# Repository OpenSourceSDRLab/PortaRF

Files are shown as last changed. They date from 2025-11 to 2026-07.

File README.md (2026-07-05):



# PortaRF
Custom Hardware and Firmware Bin Files for the PortaRF Gadget.

# Introduction
The PortaRF is an open-source hardware platform that combines the [HackRF One R10](https://github.com/greatscottgadgets/hackrf/tree/master/hardware/hackrf-one) and [PortaPack H4M](https://github.com/OpenSourceSDRLab/mayhem-firmware/tree/next/hardware/portapack_h4m) into a single Board. It supports the transmission and reception of radio signals ranging from 1 MHz to 6 GHz, rendering it an exceptionally versatile tool for RF exploration and development.  It is a portable, standalone device for signal analysis and transmission without requiring a computer.

Here is a news report about the PortaRF from [RTL-SDR.com](https://www.rtl-sdr.com/two-youtube-reviews-of-the-new-portarf-a-new-hackrf-portapack-combo/).




# Where to buy
[OpenSourceSDRLab](https://opensourcesdrlab.com/products/portarf) official website.

# Videos
Porta RF Deep Dive (https://www.youtube.com/watch?v=B1F76LqbRrY)

HackRF Portapack Evolved? This is PortaRF (https://www.youtube.com/watch?v=LNKeIju5pRY)

PortaRF - HackRF One and PortaPack H4M Combined Gadget for Mayhem Software Defined Radio (https://www.youtube.com/watch?v=UqoFG5f3fv4)

PortaRF - Utilizing the AI Voice-assisted device control function (https://www.youtube.com/watch?v=Xrx7OxZS-OY))

PortaRF Quick Look (https://www.youtube.com/watch?v=y4wdKojJfC0)

# Hardware Improvements
1. **Doubled flash storage capacity**.
We have replaced the original W25Q80DVSSIQ with W25Q16DV SPI Flash chip, expanding the original firmware storage capacity from 1M byte to 2M byte. This provides a broader creative space for Mayhem firmware developers, enabling the implementation of more complex signal processing algorithms and functions.

2. **4.0-inch IPS resistive touch screen**.
The screen has been upgraded to a 4.0-inch IPS full-view high-definition display. Compared with the original 3.2-inch non-IPS matte screen, it has made a significant improvement in color reproduction, viewing angle and touch accuracy. Whether it's spectrum analysis or parameter settings, the text is clearer and the operation is more precise.

3. **3000mAh lithium battery system**.
The battery capacity has been increased to 3000mAh, significantly extending the battery life. At the same time, an intelligent battery protection board has been used in this battery, providing protection against overcharging, overdischarging, short circuiting, and overcurrent. This lithium battery is produced by a legitimate factory with guaranteed quality.

4. **User-friendly hand-held directional keys**.
PortaRF has added a gamepad-style directional button. It is particularly suitable for rapid directional operations in functions such as spectrum scanning and game applications. It will significantly enhance the direction control efficiency and comfort.

5. **Modular Expansion Board Design**.
The expansion board adopts a Board to Board connector, a socket interface similar to the memory module, which is smaller in size and more stable in installation. This can optimize the internal space utilization.

6. **Light Guide Column LED Status Indication System**.
PortaRF also incorporates the light guide column design, making the LED status lights more visible. Regardless of day or night, the equipment status is clearly visible.

7. **Nice shell design**.
We have designed a brand new shell for the PortaRF and added many design elements, such as the buckle of the shell, which makes the shell fit tightly. The slot of the memory card is designed with grooves, the SD card can be inserted and removed without the need for tools. The dual speaker sound hole design enables better sound output from the speakers.

8. **AI voice-assisted (Beta version)**.
PortaRF incorporates voice-controlled interaction technology. Users can perform operations such as device activation, application switching, and system reboot through natural voice commands. This feature is particularly suitable for scenarios where hands are not available, providing additional convenience operations.

# Applications
<div class="editor_table_wrap">&nbsp;
<table border="1" style="width: 81.0373%; height: 526px;">
<tbody>
<tr style="height: 26.2px;">
<td style="width: 55.25%; height: 26.2px;">
<h3 class="text-xl font-semibold text-indigo-800 mb-3">Receive Applications</h3>
</td>
<td style="width: 44.7339%; height: 26.2px;">
<h3 class="text-xl font-semibold text-indigo-800 mb-3">Transmit Applications</h3>
</td>
</tr>
<tr style="height: 22.4px;">
<td style="width: 55.25%; height: 22.4px;"><strong>Sniff &amp; Capture</strong>: Sniff &amp; capture signals for instant replay or save to SD card for analysis</td>
<td style="width: 44.7339%; height: 22.4px;"><strong>ADS-B</strong>: Transmit ADS-B (Aviation) signals for testing</td>
</tr>
<tr style="height: 44.8px;">
<td style="width: 55.25%; height: 44.8px;"><strong>ADS-B</strong>: Receive and analyze aviation signals with real-time location display</td>
<td style="width: 44.7339%; height: 44.8px;"><strong>APRS</strong>: Transmit APRS packets for GPS, weather stations and telemetry</td>
</tr>
<tr style="height: 22.4px;">
<td style="width: 55.25%; height: 22.4px;"><strong>AIS</strong>: Receive and analyze marine vessel signals</td>
<td style="width: 44.7339%; height: 22.4px;"><strong>GPS</strong>: Transmit GPS signals for testing</td>
</tr>
<tr style="height: 22.4px;">
<td style="width: 55.25%; height: 22.4px;"><strong>AFSK</strong>: Receive, demodulate and analyze AFSK signals</td>
<td style="width: 44.7339%; height: 22.4px;"><strong>Key Fob</strong>: Key-fob capture, replay and emulation for multiple models</td>
</tr>
<tr style="height: 22.4px;">
<td style="width: 55.25%; height: 22.4px;"><strong>Bluetooth</strong>: Sniff MAC addresses of BLE devices</td>
<td style="width: 44.7339%; height: 22.4px;"><strong>Morse Code</strong>: Morse code transmission tool</td>
</tr>
<tr style="height: 22.4px;">
<td style="width: 55.25%; height: 22.4px;"><strong>NRF</strong>: Decode NRF24L01 signals, commonly used for drones</td>
<td style="width: 44.7339%; height: 22.4px;"><strong>Burger Pager</strong>: Transmit restaurant pager signals</td>
</tr>
<tr style="height: 22.4px;">
<td style="width: 55.25%; height: 22.4px;"><strong>Audio</strong>: Decode WFM/NFM/AM radio transmissions</td>
<td style="width: 44.7339%; height: 22.4px;"><strong>POCSAG</strong>: Transmit pager signals</td>
</tr>
<tr style="height: 22.4px;">
<td style="width: 55.25%; height: 22.4px;"><strong>Spectrum Analyzer</strong>: Waterfall spectrum analyzer for detecting signals</td>
<td style="width: 44.7339%; height: 22.4px;"><strong>SSTV</strong>: Transmit Slow Scan Television signals</td>
</tr>
<tr style="height: 22.4px;">
<td style="width: 55.25%; height: 22.4px;"><strong>Analog TV</strong>: Decode and watch analog TV signals, used on FPV drones</td>
<td style="width: 44.7339%; height: 22.4px;"><strong>RDS</strong>: Send Radio Data System messages</td>
</tr>
<tr style="height: 22.4px;">
<td style="width: 55.25%; height: 22.4px;"><strong>ERT Meters</strong>: Decode ERT Meter signals</td>
<td style="width: 44.7339%; height: 22.4px;"><strong>OOK</strong>: Send On-Off Keying packages</td>
</tr>
<tr style="height: 22.4px;">
<td style="width: 55.25%; height: 22.4px;"><strong>POCSAG</strong>: Sniff and decode pager signals</td>
<td style="width: 44.7339%; height: 22.4px;"></td>
</tr>
<tr style="height: 22.4px;">
<td style="width: 55.25%; height: 22.4px;"><strong>Radiosonde</strong>: Sniff and decode weather station signals</td>
<td style="width: 44.7339%; height: 22.4px;"></td>
</tr>
<tr style="height: 22.4px;">
<td style="width: 55.25%; height: 22.4px;"><strong>TPMS</strong>: Decode Tire Pressure Monitoring System sensors</td>
<td style="width: 44.7339%; height: 22.4px;">&nbsp; &nbsp; &nbsp; &nbsp;</td>
</tr>
</tbody>
</table>

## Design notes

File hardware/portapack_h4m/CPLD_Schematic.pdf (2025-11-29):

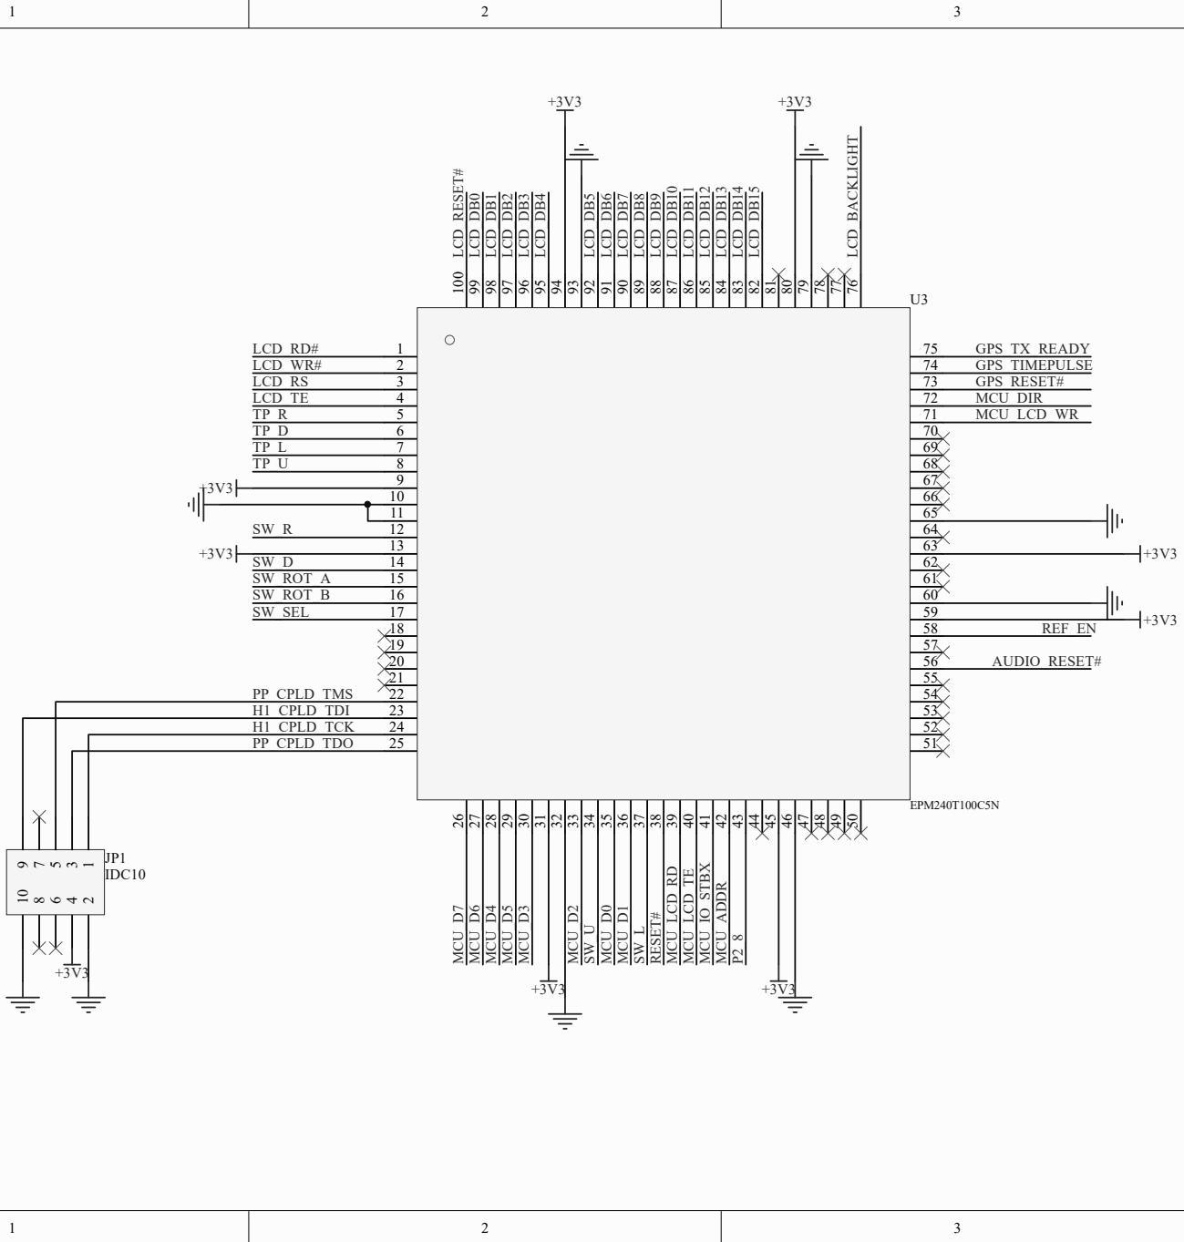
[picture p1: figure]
LCD_DB10; LCD_DB11; LCD_DB12; LCD_DB13; LCD_DB14; LCD_DB15; MCU_DIR MCU_LCD_WR; LCD_RESET#; LCD_BACKLIGHT; GPS_TX_READY GPS_TIMEPULSE; MCU_ADDR; PP_CPLD_TDO; MCU_D7; MCU_D6; MCU_D4; MCU_D5; MCU_D3; MCU_D2; MCU_D0; MCU_D1; RESET#; MCU_LCD_RD; MCU_LCD_TE; MCU_IO_STBX; H1_CPLD_TCK; SW_D SW_ROT_A SW_ROT_B SW_SEL; PP_CPLD_TMS H1_CPLD_TDI; GPS_RESET#; AUDIO_RESET#; REF_EN; LCD_TE; LCD_WR#; LCD_RD#; LCD_DB0; LCD_DB1; LCD_RS; LCD_DB2; LCD_DB3; LCD_DB4; LCD_DB5; LCD_DB6; LCD_DB7; LCD_DB8; LCD_DB9; EPM240T100C5N; JP1 IDC10

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
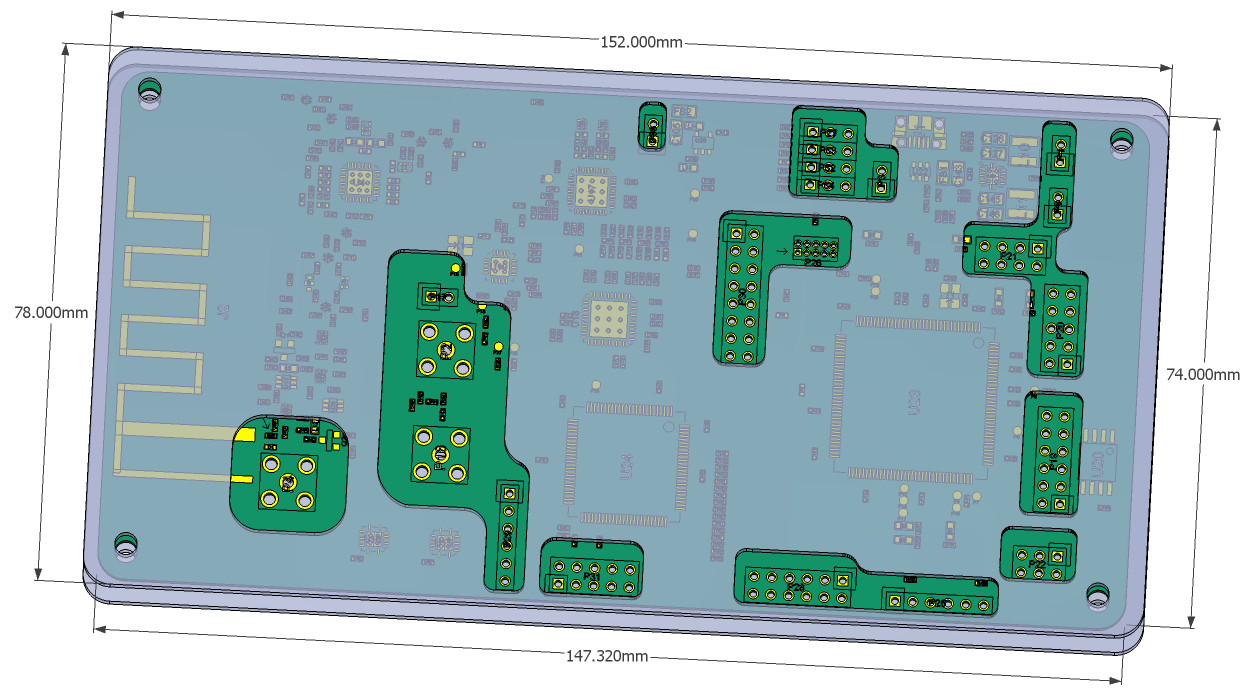
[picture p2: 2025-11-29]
hackrf/hardware/jawbreaker/SoBv1_DP17298/jawbreaker_and_case.png

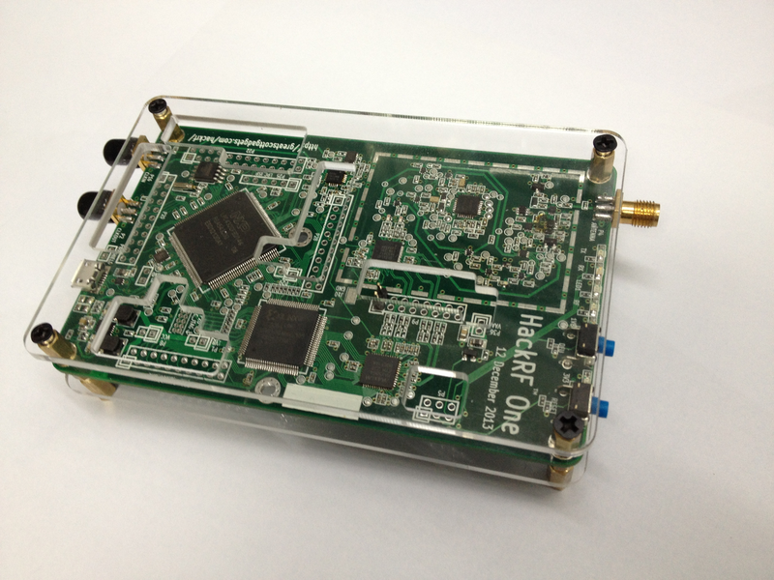
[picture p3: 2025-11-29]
hackrf/hardware/hackrf-one/PlasticCase_CAD/Case_With_HackRF.png

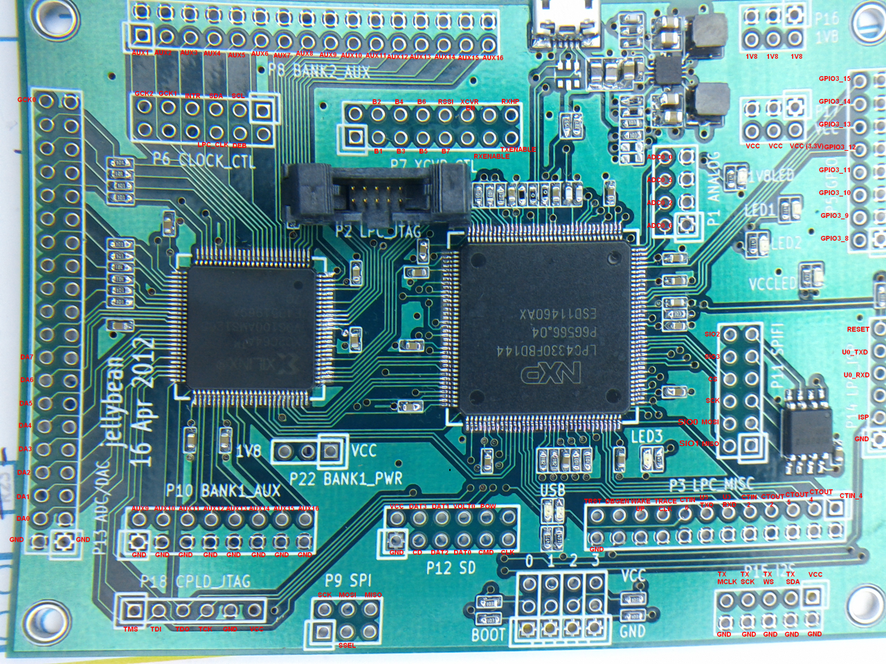
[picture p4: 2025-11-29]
hackrf/hardware/jellybean/JellyBean_pins.png

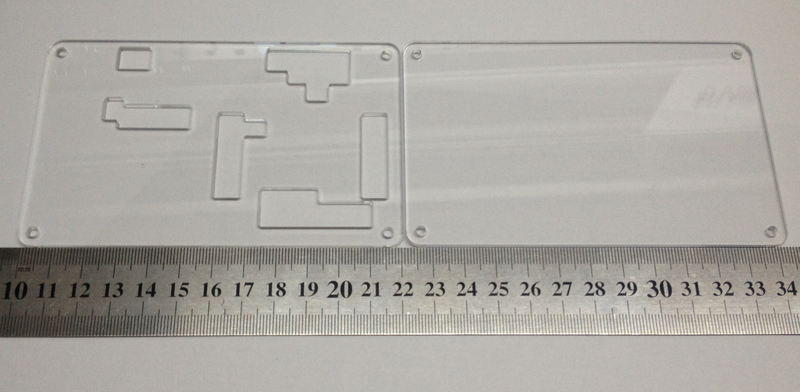
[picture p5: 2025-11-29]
hackrf/hardware/hackrf-one/PlasticCase_CAD/HackRF_One_Case.png

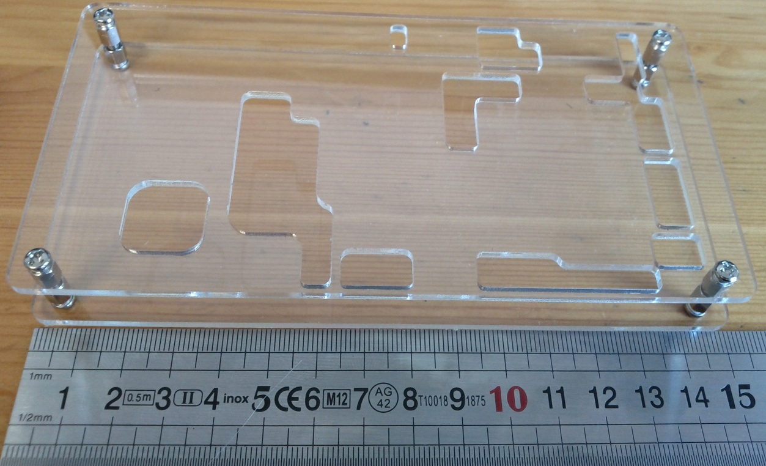
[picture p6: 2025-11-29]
hackrf/hardware/jawbreaker/SoBv1_DP17298/SoBv1-DP17298-jawbreaker.jpg

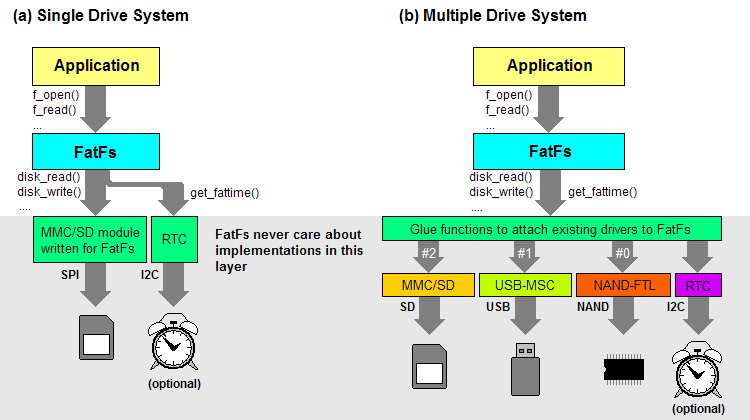
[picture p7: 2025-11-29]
firmware/chibios-portapack/ext/fatfs/doc/res/funcs.png

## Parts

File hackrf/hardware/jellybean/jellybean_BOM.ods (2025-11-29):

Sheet: JellyBean_BOM
Ref | Value | Manufacturer | Footprint | Details | DigiKey Quantity | DigiKey PN
R1 | 0 | Panasonic | ERJ-3GEY0R00V | RES 0.0 OHM 1/10W 0603 SMD | 2 | P0.0GCT-ND
R2 | 0 | Panasonic | ERJ-3GEY0R00V | RES 0.0 OHM 1/10W 0603 SMD
R18 | 100 | Panasonic | ERJ-3GEYJ101V | RES 100 OHM 1/10W 5% 0603 SMD | 10 | P100GCT-ND
R19 | 100 | Panasonic | ERJ-3GEYJ101V | RES 100 OHM 1/10W 5% 0603 SMD
R20 | 100 | Panasonic | ERJ-3GEYJ101V | RES 100 OHM 1/10W 5% 0603 SMD
R21 | 100 | Panasonic | ERJ-3GEYJ101V | RES 100 OHM 1/10W 5% 0603 SMD
R22 | 100 | Panasonic | ERJ-3GEYJ101V | RES 100 OHM 1/10W 5% 0603 SMD
R23 | 100 | Panasonic | ERJ-3GEYJ101V | RES 100 OHM 1/10W 5% 0603 SMD
R24 | 100 | Panasonic | ERJ-3GEYJ101V | RES 100 OHM 1/10W 5% 0603 SMD
R25 | 100 | Panasonic | ERJ-3GEYJ101V | RES 100 OHM 1/10W 5% 0603 SMD
R26 | 100 | Panasonic | ERJ-3GEYJ101V | RES 100 OHM 1/10W 5% 0603 SMD
R27 | 100 | Panasonic | ERJ-3GEYJ101V | RES 100 OHM 1/10W 5% 0603 SMD
R12 | 470 | Panasonic | ERJ-3GEYJ471V | RES 470 OHM 1/10W 5% 0603 SMD | 7 | P470GCT-ND
R13 | 470 | Panasonic | ERJ-3GEYJ471V | RES 470 OHM 1/10W 5% 0603 SMD
R15 | 470 | Panasonic | ERJ-3GEYJ471V | RES 470 OHM 1/10W 5% 0603 SMD
R29 | 470 | Panasonic | ERJ-3GEYJ471V | RES 470 OHM 1/10W 5% 0603 SMD
R3 | 470 | Panasonic | ERJ-3GEYJ471V | RES 470 OHM 1/10W 5% 0603 SMD
R8 | 470 | Panasonic | ERJ-3GEYJ471V | RES 470 OHM 1/10W 5% 0603 SMD
R9 | 470 | Panasonic | ERJ-3GEYJ471V | RES 470 OHM 1/10W 5% 0603 SMD
R30 | 1k8 | Panasonic | ERJ-3GEYJ182V | RES 1.8K OHM 1/10W 5% 0603 SMD | 2 | P1.8KGCT-ND
R31 | 1k8 | Panasonic | ERJ-3GEYJ182V | RES 1.8K OHM 1/10W 5% 0603 SMD
R16 | 10k | Panasonic | ERJ-3GEYJ103V | RES 10K OHM 1/10W 5% 0603 SMD | 13 | P10KGCT-ND
R17 | 10k | Panasonic | ERJ-3GEYJ103V | RES 10K OHM 1/10W 5% 0603 SMD
R28 | 10k | Panasonic | ERJ-3GEYJ103V | RES 10K OHM 1/10W 5% 0603 SMD
R32 | 10k | Panasonic | ERJ-3GEYJ103V | RES 10K OHM 1/10W 5% 0603 SMD
R39 | 10k | Panasonic | ERJ-3GEYJ103V | RES 10K OHM 1/10W 5% 0603 SMD
R4 | 10k | Panasonic | ERJ-3GEYJ103V | RES 10K OHM 1/10W 5% 0603 SMD
R40 | 10k | Panasonic | ERJ-3GEYJ103V | RES 10K OHM 1/10W 5% 0603 SMD
R41 | 10k | Panasonic | ERJ-3GEYJ103V | RES 10K OHM 1/10W 5% 0603 SMD
R42 | 10k | Panasonic | ERJ-3GEYJ103V | RES 10K OHM 1/10W 5% 0603 SMD
R43 | 10k | Panasonic | ERJ-3GEYJ103V | RES 10K OHM 1/10W 5% 0603 SMD
R5 | 10k | Panasonic | ERJ-3GEYJ103V | RES 10K OHM 1/10W 5% 0603 SMD
R6 | 10k | Panasonic | ERJ-3GEYJ103V | RES 10K OHM 1/10W 5% 0603 SMD
R7 | 10k | Panasonic | ERJ-3GEYJ103V | RES 10K OHM 1/10W 5% 0603 SMD
R14 | 12k | Panasonic | ERJ-3EKF1202V | RES 12.0K OHM 1/10W 1% 0603 SMD | 1 | P12.0KHCT-ND
R10 | 15k | Panasonic | ERJ-3GEYJ153V | RES 15K OHM 1/10W 5% 0603 SMD | 1 | P15KGCT-ND
R11 | 33k | Panasonic | ERJ-3GEYJ333V | RES 33K OHM 1/10W 5% 0603 SMD | 1 | P33KGCT-ND
R36 | 160k+560k in parallel (to obtain 3,3V instead of 2.7V) | Panasonic | ERJ-3EKF1603V | RES 160K OHM 1/10W 1% 0603 SMD | 1 | P160KHCT-ND
R35 | 180k | Panasonic | ERJ-3EKF1803V | RES 180K OHM 1/10W 1% 0603 SMD | 1 | P180KHCT-ND
R37 | 360k | Panasonic | ERJ-3EKF3603V | RES 360K OHM 1/10W 1% 0603 SMD | 1 | P360KHCT-ND
R38 | 560k | Panasonic | ERJ-3EKF5603V | RES 560K OHM 1/10W 1% 0603 SMD | 2 | P560KHCT-ND
C24 | 22pF | Murata | GRM1885C1H220JA01D | CAP CER 22PF 50V 5% NP0 0603 | 10 | 490-1411-1-ND
C18 | 47pF | Murata | GRM1885C1H470JA01D | CAP CER 47PF 50V 5% NP0 0603 | 10 | 490-1419-1-ND
C1 | 100nF | Murata | GRM188R71C104KA01D | CAP CER 0.1UF 16V 10% X7R 0603 | 30 | 490-1532-1-ND
C10 | 100nF | Murata | GRM188R71C104KA01D | CAP CER 0.1UF 16V 10% X7R 0603
C11 | 100nF | Murata | GRM188R71C104KA01D | CAP CER 0.1UF 16V 10% X7R 0603
C12 | 100nF | Murata | GRM188R71C104KA01D | CAP CER 0.1UF 16V 10% X7R 0603
C13 | 100nF | Murata | GRM188R71C104KA01D | CAP CER 0.1UF 16V 10% X7R 0603
C14 | 100nF | Murata | GRM188R71C104KA01D | CAP CER 0.1UF 16V 10% X7R 0603
C15 | 100nF | Murata | GRM188R71C104KA01D | CAP CER 0.1UF 16V 10% X7R 0603
C17 | 100nF | Murata | GRM188R71C104KA01D | CAP CER 0.1UF 16V 10% X7R 0603
C19 | 100nF | Murata | GRM188R71C104KA01D | CAP CER 0.1UF 16V 10% X7R 0603
C2 | 100nF | Murata | GRM188R71C104KA01D | CAP CER 0.1UF 16V 10% X7R 0603
C20 | 100nF | Murata | GRM188R71C104KA01D | CAP CER 0.1UF 16V 10% X7R 0603
C22 | 100nF | Murata | GRM188R71C104KA01D | CAP CER 0.1UF 16V 10% X7R 0603
C23 | 100nF | Murata | GRM188R71C104KA01D | CAP CER 0.1UF 16V 10% X7R 0603
C25 | 100nF | Murata | GRM188R71C104KA01D | CAP CER 0.1UF 16V 10% X7R 0603
C26 | 100nF | Murata | GRM188R71C104KA01D | CAP CER 0.1UF 16V 10% X7R 0603
C29 | 100nF | Murata | GRM188R71C104KA01D | CAP CER 0.1UF 16V 10% X7R 0603
C3 | 100nF | Murata | GRM188R71C104KA01D | CAP CER 0.1UF 16V 10% X7R 0603
C32 | 100nF | Murata | GRM188R71C104KA01D | CAP CER 0.1UF 16V 10% X7R 0603
C33 | 100nF | Murata | GRM188R71C104KA01D | CAP CER 0.1UF 16V 10% X7R 0603
C4 | 100nF | Murata | GRM188R71C104KA01D | CAP CER 0.1UF 16V 10% X7R 0603
C5 | 100nF | Murata | GRM188R71C104KA01D | CAP CER 0.1UF 16V 10% X7R 0603
C7 | 100nF | Murata | GRM188R71C104KA01D | CAP CER 0.1UF 16V 10% X7R 0603
C8 | 100nF | Murata | GRM188R71C104KA01D | CAP CER 0.1UF 16V 10% X7R 0603
C9 | 100nF | Murata | GRM188R71C104KA01D | CAP CER 0.1UF 16V 10% X7R 0603
C16 | 100pF | Murata | GRM1885C1H101JA01D | CAP CER 100PF 50V 5% NP0 0603 | 10 | 490-1427-1-ND
C6 | 4u7 | Taiyo Yuden | LMK212BJ475KD-T | CAP CER 4.7UF 10V 10% X5R 0805 | 1 | 587-1297-1-ND
C21 | 10uF | Murata | GRM21BR61A106KE19L | CAP CER 10UF 10V 10% X5R 0805 | 10 | 490-1709-1-ND
C27 | 10uF | Murata | GRM21BR61A106KE19L | CAP CER 10UF 10V 10% X5R 0805
C28 | 10uF | Murata | GRM21BR61A106KE19L | CAP CER 10UF 10V 10% X5R 0805
C30 | 10uF | Murata | GRM21BR61A106KE19L | CAP CER 10UF 10V 10% X5R 0805
C31 | 10uF | Murata | GRM21BR61A106KE19L | CAP CER 10UF 10V 10% X5R 0805
L1 | 4u7 | Taiyo Yuden | NRG4026T4R7M | INDUCTOR 4.7UH 1.6A 20% SMD | 2 | 587-2382-1-ND
L2 | 4u7 | Taiyo Yuden | NRG4026T4R7M | INDUCTOR 4.7UH 1.6A 20% SMD
FB1 | FILTER | Murata | BLM21PG221SN1D | FERRITE CHIP 220 OHM 2000MA 0805 | 1 | 490-1054-1-ND
U1 | GSG-IP4220CZ6 | NXP | IP4220CZ6,125 | IC USB DUAL ESD PROTECT 6TSOP | 1 | 568-3529-1-ND
J1 | GSG-USB-MICRO-B | FCI | 10103594-0001LF | CONN RCPT STD MICRO USB TYPE B | 1 | 609-4050-1-ND
U4 | GSG-XC2C64A-7VQG100C | Xilinx | XC2C64A-7VQG100C | IC CR-II CPLD 64MCELL 100-VQFP | 1 | 122-1409-ND
U2 | LPC43XXFBD144 | NXP | LPC4330FBD144,551 | IC MCU 32BIT 144LQFP | 1 | 568-9450-ND
U5 | TPS62410 | Texas Instruments | TPS62410DRCR | IC BUCK SYNC DUAL ADJ 0.8A 10SON | 1 | 296-25488-1-ND
D3 | LED3 | Everlight | QTLP601CRTR | LED RED STD BRIGHT 0603 SMD | 1 | 1080-1407-1-ND
D5 | 1V8LED | Everlight | QTLP600CYTR | LED YLW SUPER BRIGHT 0606 SMD | 3 | 1080-1404-1-ND
D2 | LED2 | Everlight | QTLP600CYTR | LED YLW SUPER BRIGHT 0606 SMD
D7 | USBLED0 | Everlight | QTLP600CYTR | LED YLW SUPER BRIGHT 0606 SMD
D1 | LED1 | Everlight | QTLP601C4TR | LED GREEN STD BRIGHT 0603 SMD | 3 | 1080-1405-1-ND
D6 | USBLED1 | Everlight | QTLP601C4TR | LED GREEN STD BRIGHT 0603 SMD
D4 | VCCLED | Everlight | QTLP601C4TR | LED GREEN STD BRIGHT 0603 SMD
U3 | W25Q80BV | Winbond | W25Q80BVSSIG | IC FLASH 8MBIT 8SOIC | 1 | W25Q80BVSSIG-ND
P2 | LPC_JTAG | Samtec Inc | EHF-105-01-L-D | CONN HEADER .05" 10POS DUAL T/H | 1 | SAM8205-ND
P16 | 1V8
P13 | ADC/DAC
P1 | ANALOG
P10 | BANK1_AUX
P22 | BANK1_PWR
P8 | BANK2_AUX
P4 | BOOT0
P19 | BOOT1
P20 | BOOT2
P21 | BOOT3
P6 | CLOCK_CTL
P18 | CPLD_JTAG
R33 | DNP
R34 | DNP
P5 | GPIO
P15 | I2S
P14 | LPC_ISP
P3 | LPC_MISC
P12 | SD
P9 | SPI
P11 | SPIFI
P7 | XCVR_CTL
P17 | VCC

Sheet: ImportPart_DigiKey
2,P0.0GCT-ND
10,P100GCT-ND
7,P470GCT-ND
2,P1.8KGCT-ND
13,P10KGCT-ND
1,P12.0KHCT-ND
1,P15KGCT-ND
1,P33KGCT-ND
1,P160KHCT-ND
1,P180KHCT-ND
1,P360KHCT-ND
2,P560KHCT-ND
10,490-1411-1-ND
10,490-1419-1-ND
30,490-1532-1-ND
10,490-1427-1-ND
1,587-1297-1-ND
10,490-1709-1-ND
2,587-2382-1-ND
1,490-1054-1-ND
1,568-3529-1-ND
1,609-4050-1-ND
1,122-1409-ND
1,568-9450-ND
1,296-25488-1-ND
1,1080-1407-1-ND
3,1080-1404-1-ND
3,1080-1405-1-ND
1,W25Q80BVSSIG-ND
1,SAM8205-ND

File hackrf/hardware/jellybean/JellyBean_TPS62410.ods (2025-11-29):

 | TPS62410 VCC |  | TPS62410 1V8
R36 (OHM) | 160000 | R35 (OHM) | 180000
R38 (OHM) | 560000 | R37 (OHM) | 360000
 | VCC (Converter1) |  | 1V8
Out Voltage | 2,7 | Out Voltage | 1,8
After Fix 3.3V
 | TPS62410 VCC
R36 (OHM) | 124444 | 160KOHM in // with 560KOHM
R38 (OHM) | 560000
 | VCC (Converter1)
Out Voltage | 3,3

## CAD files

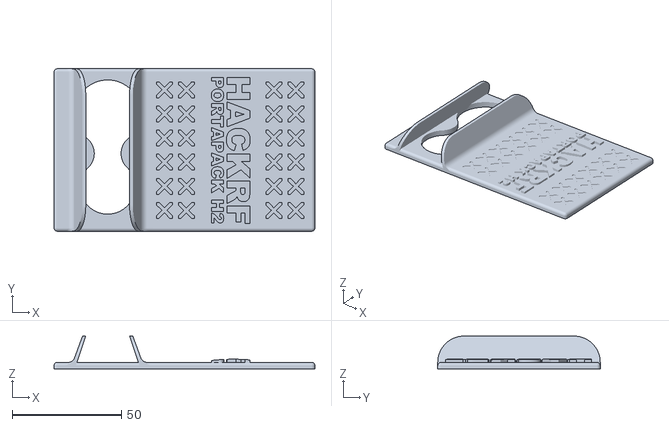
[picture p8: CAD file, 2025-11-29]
hardware/portapack_h2/3d_printed/cover/revisited_cover.stl
119.2 x 74.2 x 15.0

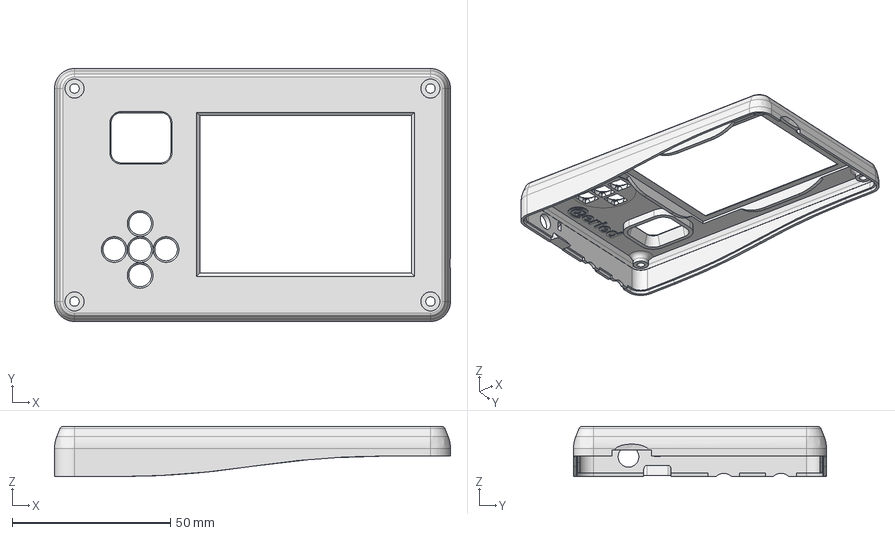
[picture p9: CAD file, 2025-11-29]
hardware/portapack_h2/3d_printed/enclosure/revisited_up.stp
124.9 x 79.8 x 15.9 mm

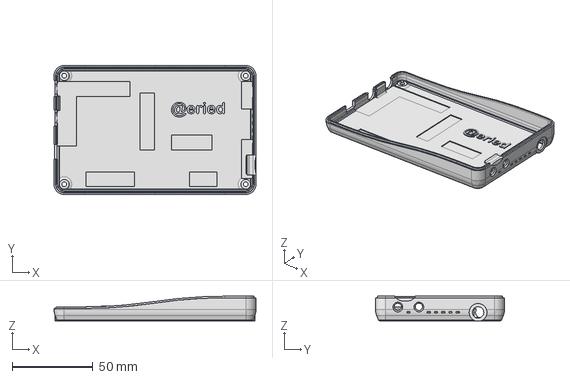
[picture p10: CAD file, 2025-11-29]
hardware/portapack_h2/3d_printed/enclosure/revisited_down.stp
124.9 x 79.8 x 15.2 mm

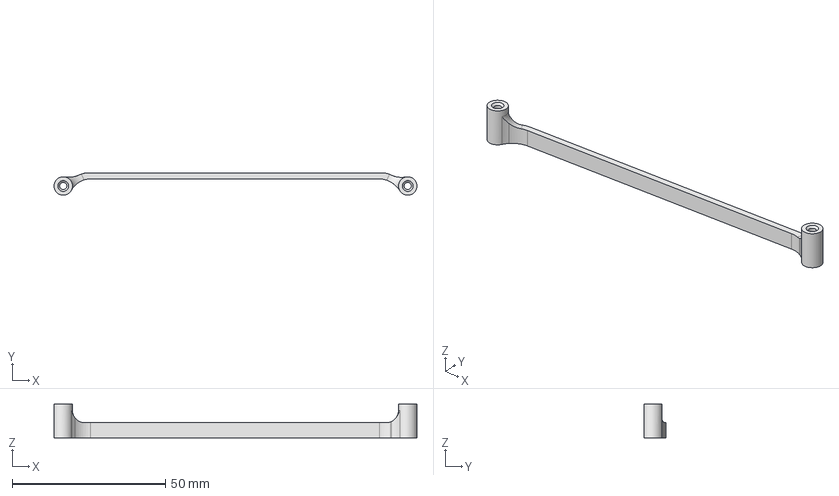
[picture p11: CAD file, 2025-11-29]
hardware/portapack_h2/3d_printed/enclosure/revisited_support.stp
118.3 x 7.32 x 11.0 mm

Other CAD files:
hackrf/hardware/jawbreaker/SoBv1_DP17298/SoBv1-DP17298-jawbreaker-Bottom.skp
hackrf/hardware/jawbreaker/SoBv1_DP17298/SoBv1-DP17298-jawbreaker-Top.skp
hardware/portapack_h2/3d_printed/enclosure/revisited_down.stl
hardware/portapack_h2/3d_printed/enclosure/revisited_support.stl
hardware/portapack_h2/3d_printed/enclosure/revisited_up.stl

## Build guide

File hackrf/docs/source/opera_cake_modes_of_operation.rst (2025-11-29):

==================
Modes of Operation
==================

Opera Cake supports three modes of operation: ``manual``, ``frequency``, and ``time``. The operating mode can be set with the ``--mode`` or ``-m`` option, and the active operating mode is displayed with the ``--list`` or ``-l`` option.

Manual Mode
~~~~~~~~~~~

The default mode of operation is ``manual``. In manual mode, fixed port connections are configured with the ``-a`` and ``-b`` options as in the :ref:`port configuration examples <portconfiguration>`. If the operating mode has been changed, it can be changed back to manual mode with:

.. code-block:: sh

	hackrf_operacake -m manual

Frequency Mode
~~~~~~~~~~~~~~

In frequency mode, the A0 port connection switches automatically whenever the HackRF is tuned to a different frequency. This is useful when antennas for different frequency bands are connected to various ports.

The bands are specified in priority order. The final band specified will be used for frequencies not covered by the other bands specified.

To assign frequency bands to ports you must use the ``-f <port:min:max>`` option for each band, with the minimum and maximum frequencies specified in MHz. For example, to use port A1 for 100 MHz to 600 MHz, A3 for 600 MHz to 1200 MHz, and B2 for 0 MHz to 4 GHz:

.. code-block:: sh

	hackrf_operacake -m frequency -f A1:100:600 -f A3:600:1200 -f B2:0:4000

If tuning to precisely 600 MHz, A1 will be used as it is listed first. Tuning to any frequency over 4 GHz will use B2 as it is the last listed and therefore the default port.

Only the A0 port connection is specified in frequency mode. Whenever the A0 connection is switched, the B0 connection is also switched to the secondary port mirroring A0's secondary port. For example, when A0 switches to B2, B0 is switched to A2.

Once configured, an Opera Cake will remain in frequency mode until the mode is reconfigured or until the HackRF One is reset. You can pre-configure the Opera Cake in frequency mode, and the automatic switching will continue to work while using other software.

Although multiple Opera Cakes on a single HackRF One may be set to frequency mode at the same time, they share a single switching plan. This can be useful, for example, for a filter bank consisting of eight filters.

Time Mode
~~~~~~~~~

In time mode, the A0 port connection switches automatically over time, counted in units of the sample period. This is useful for experimentation with pseudo-doppler direction finding.

To cycle through four ports, one port every 1000 samples:

.. code-block:: none

	hackrf_operacake -m time -t A1:1000 -t A2:1000 -t A3:1000 -t A4:1000

When the duration on multiple ports is the same, the ``-w`` option can be used to set the default dwell time:

.. code-block:: none

	hackrf_operacake --mode time -w 1000 -t A1 -t A2 -t A3 -t A4

Only the A0 port connection is specified in time mode. Whenever the A0 connection is switched, the B0 connection is switched to the secondary port mirroring A0's secondary port. For example, when A0 switches to B2, B0 is switched to A2.

Once configured, an Opera Cake will remain in time mode until the mode is reconfigured or until the HackRF One is reset. You can pre-configure the Opera Cake in time mode, and the automatic switching will continue to work while using other software.

Although multiple Opera Cakes on a single HackRF One may be set to time mode at the same time, they share a single switching plan.

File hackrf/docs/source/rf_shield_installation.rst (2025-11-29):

===============================================
RF Shield Installation Instructions
===============================================

Official Great Scott Gadgets HackRF Ones do not come from the factory with an RF shield installed around the radio section of the PCB. They do, however, have pads in place so that one may be installed if a user has a reason and an inclination to do so. The reason that they do not come preinstalled is that early testing revealed that the RF shield did little to improve the performance of the HackRF One. The recommended RF shield is the BMI-S-230-F-R (frame) with the BMI-S-230-C (shield). A two part RF shield is recommended because the shield section can be removed to allow access to the RF section of the HackRF One. This can be important if it becomes necessary to probe any part of the RF section, or to replace any parts of the RF section. However, even with a two part RF shield, it can be difficult to access the RF section of the HackRF One in certain situations. The following steps are a basic set of instructions for installing a RF shield on a HackRF One.

**CAUTION: Soldering a RF shield onto a HackRF One comes with a certain amount of risk. Beyond the inherent risks of soldering itself, this process may damage the HackRF One and no warranty is available to cover damage incurred from this process. If you do choose to install a RF shield on your HackRF One please proceed with caution.**

1. Remove the HackRF One from the injection molded plastic case. 

  **BE WARNED: Opening the plastic case of your HackRF One will most likely destroy the tabs that hold it together.**  

  Instructions for removing a HackRF One from its case can be found :ref:`here <open_your_hackrf_one>`.

2. Prepare the HackRF One PCB for soldering on the shield frame, by adding flux to the RF shield pads around the radio section on the PCB.

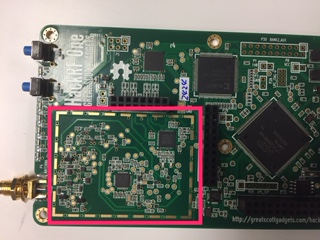
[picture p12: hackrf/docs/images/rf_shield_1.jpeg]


3. Place the RF shield frame on the HackRF One, aligning it so that it makes contact with all of the pads around the RF section of the board.

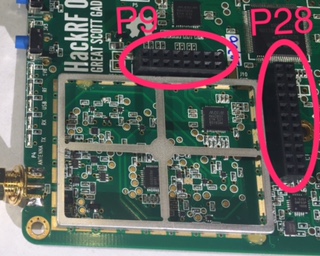
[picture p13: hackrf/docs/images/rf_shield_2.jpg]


4. Solder the shield to one pad to anchor it to the H1. Visually inspect the frame to assure that it is still aligned properly.

+---------------------------------------+---------------------------------------+
| 
+---------------------------------------+---------------------------------------+

5. Connect the frame to another pad on the opposite side from the first connection. Again, check that the frame is still aligned properly.

+---------------------------------------+---------------------------------------+
| 
+---------------------------------------+---------------------------------------+

6. Connect at least one more pad, and then remove the pick and place bridge from the frame. *Removing the pick and place bridge is optional, but it is recommended.*

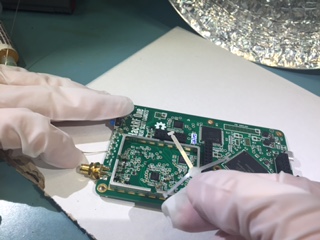
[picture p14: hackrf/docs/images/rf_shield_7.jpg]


7. Continue soldering the rest of the pads to the frame.

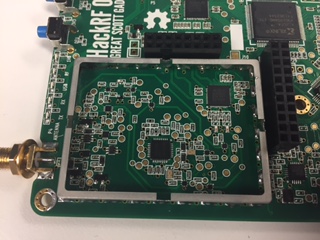
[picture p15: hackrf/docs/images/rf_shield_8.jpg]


8. Clean the flux and soldering residue with the appropriate solvent for the type of flux used. Be sure to let the HackRF One dry completely before plugging it in to a power source.

9. Place the RF shield onto the frame and snap it into place.

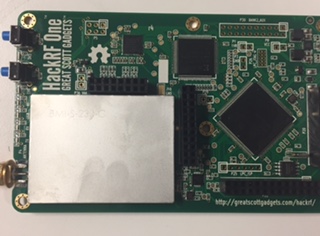
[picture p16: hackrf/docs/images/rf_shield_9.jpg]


10. If desired, put the HackRF One back into the plastic case, if it is still able to click together.

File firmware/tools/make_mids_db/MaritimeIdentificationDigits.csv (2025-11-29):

Digit | Allocated to
201 | Albania (Republic of)
202 | Andorra (Principality of)
203 | Austria
204 | Portugal - Azores
205 | Belgium
206 | Belarus (Republic of)
207 | Bulgaria (Republic of)
208 | Vatican City State
209 | Cyprus (Republic of)
210 | Cyprus (Republic of)
211 | Germany (Federal Republic of)
212 | Cyprus (Republic of)
213 | Georgia
214 | Moldova (Republic of)
215 | Malta
216 | Armenia (Republic of)
218 | Germany (Federal Republic of)
219 | Denmark
220 | Denmark
224 | Spain
225 | Spain
226 | France
227 | France
228 | France
229 | Malta
230 | Finland
231 | Denmark - Faroe Islands
232 | United Kingdom of Great Britain and Northern Ireland
233 | United Kingdom of Great Britain and Northern Ireland
234 | United Kingdom of Great Britain and Northern Ireland
235 | United Kingdom of Great Britain and Northern Ireland
236 | United Kingdom of Great Britain and Northern Ireland - Gibraltar
237 | Greece
238 | Croatia (Republic of)
239 | Greece
240 | Greece
241 | Greece
242 | Morocco (Kingdom of)
243 | Hungary
244 | Netherlands (Kingdom of the)
245 | Netherlands (Kingdom of the)
246 | Netherlands (Kingdom of the)
247 | Italy
248 | Malta
249 | Malta
250 | Ireland
251 | Iceland
252 | Liechtenstein (Principality of)
253 | Luxembourg
254 | Monaco (Principality of)
255 | Portugal - Madeira
256 | Malta
257 | Norway
258 | Norway
259 | Norway
261 | Poland (Republic of)
262 | Montenegro
263 | Portugal
264 | Romania
265 | Sweden
266 | Sweden
267 | Slovak Republic
268 | San Marino (Republic of)
269 | Switzerland (Confederation of)
270 | Czech Republic
271 | Turkey
272 | Ukraine
273 | Russian Federation
274 | North Macedonia (Republic of)
275 | Latvia (Republic of)
276 | Estonia (Republic of)
277 | Lithuania (Republic of)
278 | Slovenia (Republic of)
279 | Serbia (Republic of)
301 | United Kingdom of Great Britain and Northern Ireland - Anguilla
303 | United States of America - Alaska (State of)
304 | Antigua and Barbuda
305 | Antigua and Barbuda
306 | Netherlands (Kingdom of the) - Bonaire, Sint Eustatius and Saba
306 | Netherlands (Kingdom of the) - Curaçao
306 | Netherlands (Kingdom of the) - Sint Maarten (Dutch part)
307 | Netherlands (Kingdom of the) - Aruba
308 | Bahamas (Commonwealth of the)
309 | Bahamas (Commonwealth of the)
310 | United Kingdom of Great Britain and Northern Ireland - Bermuda
311 | Bahamas (Commonwealth of the)
312 | Belize
314 | Barbados
316 | Canada
319 | United Kingdom of Great Britain and Northern Ireland - Cayman Islands
321 | Costa Rica
323 | Cuba
325 | Dominica (Commonwealth of)
327 | Dominican Republic
329 | France - Guadeloupe (French Department of)
330 | Grenada
331 | Denmark - Greenland
332 | Guatemala (Republic of)
334 | Honduras (Republic of)
336 | Haiti (Republic of)
338 | United States of America
339 | Jamaica
341 | Saint Kitts and Nevis (Federation of)
343 | Saint Lucia
345 | Mexico
347 | France - Martinique (French Department of)
348 | United Kingdom of Great Britain and Northern Ireland - Montserrat
350 | Nicaragua
351 | Panama (Republic of)
352 | Panama (Republic of)
353 | Panama (Republic of)
354 | Panama (Republic of)
355 | Panama (Republic of)
356 | Panama (Republic of)
357 | Panama (Republic of)
358 | United States of America - Puerto Rico
359 | El Salvador (Republic of)
361 | France - Saint Pierre and Miquelon (Territorial Collectivity of)
362 | Trinidad and Tobago
364 | United Kingdom of Great Britain and Northern Ireland - Turks and Caicos Islands
366 | United States of America
367 | United States of America
368 | United States of America
369 | United States of America
370 | Panama (Republic of)
371 | Panama (Republic of)
372 | Panama (Republic of)
373 | Panama (Republic of)
374 | Panama (Republic of)
375 | Saint Vincent and the Grenadines
376 | Saint Vincent and the Grenadines
377 | Saint Vincent and the Grenadines
378 | United Kingdom of Great Britain and Northern Ireland - British Virgin Islands
379 | United States of America - United States Virgin Islands
401 | Afghanistan
403 | Saudi Arabia (Kingdom of)
405 | Bangladesh (People's Republic of)
408 | Bahrain (Kingdom of)
410 | Bhutan (Kingdom of)
412 | China (People's Republic of)
413 | China (People's Republic of)
414 | China (People's Republic of)
416 | China (People's Republic of) - Taiwan (Province of China)
417 | Sri Lanka (Democratic Socialist Republic of)
419 | India (Republic of)
422 | Iran (Islamic Republic of)
423 | Azerbaijan (Republic of)
425 | Iraq (Republic of)
428 | Israel (State of)
431 | Japan
432 | Japan
434 | Turkmenistan
436 | Kazakhstan (Republic of)
437 | Uzbekistan (Republic of)
438 | Jordan (Hashemite Kingdom of)
440 | Korea (Republic of)
441 | Korea (Republic of)
443 | State of Palestine (In accordance with Resolution 99 Rev. Dubai, 2018)
445 | Democratic People's Republic of Korea
447 | Kuwait (State of)
450 | Lebanon
451 | Kyrgyz Republic
453 | China (People's Republic of) - Macao (Special Administrative Region of China)
455 | Maldives (Republic of)
457 | Mongolia
459 | Nepal (Federal Democratic Republic of)
461 | Oman (Sultanate of)
463 | Pakistan (Islamic Republic of)
466 | Qatar (State of)
468 | Syrian Arab Republic
470 | United Arab Emirates
471 | United Arab Emirates
472 | Tajikistan (Republic of)
473 | Yemen (Republic of)
475 | Yemen (Republic of)
477 | China (People's Republic of) - Hong Kong (Special Administrative Region of China)
478 | Bosnia and Herzegovina
501 | France - Adelie Land
503 | Australia
506 | Myanmar (Union of)
508 | Brunei Darussalam
510 | Micronesia (Federated States of)
511 | Palau (Republic of)
512 | New Zealand
514 | Cambodia (Kingdom of)
515 | Cambodia (Kingdom of)
516 | Australia - Christmas Island (Indian Ocean)
518 | New Zealand - Cook Islands
520 | Fiji (Republic of)
523 | Australia - Cocos (Keeling) Islands
525 | Indonesia (Republic of)
529 | Kiribati (Republic of)
531 | Lao People's Democratic Republic
533 | Malaysia
536 | United States of America - Northern Mariana Islands (Commonwealth of the)
538 | Marshall Islands (Republic of the)
540 | France - New Caledonia
542 | New Zealand - Niue
544 | Nauru (Republic of)
546 | France - French Polynesia
548 | Philippines (Republic of the)
550 | Timor-Leste (Democratic Republic of)
553 | Papua New Guinea
555 | United Kingdom of Great Britain and Northern Ireland - Pitcairn Island
557 | Solomon Islands
559 | United States of America - American Samoa
561 | Samoa (Independent State of)
563 | Singapore (Republic of)
564 | Singapore (Republic of)
565 | Singapore (Republic of)
566 | Singapore (Republic of)
567 | Thailand
570 | Tonga (Kingdom of)
572 | Tuvalu
574 | Viet Nam (Socialist Republic of)
576 | Vanuatu (Republic of)
577 | Vanuatu (Republic of)
578 | France - Wallis and Futuna Islands
601 | South Africa (Republic of)
603 | Angola (Republic of)
605 | Algeria (People's Democratic Republic of)
607 | France - Saint Paul and Amsterdam Islands
608 | United Kingdom of Great Britain and Northern Ireland - Ascension Island
609 | Burundi (Republic of)
610 | Benin (Republic of)
611 | Botswana (Republic of)
612 | Central African Republic
613 | Cameroon (Republic of)
615 | Congo (Republic of the)
616 | Comoros (Union of the)
617 | Cabo Verde (Republic of)
618 | France - Crozet Archipelago
619 | Côte d'Ivoire (Republic of)
620 | Comoros (Union of the)
621 | Djibouti (Republic of)
622 | Egypt (Arab Republic of)
624 | Ethiopia (Federal Democratic Republic of)
625 | Eritrea
626 | Gabonese Republic
627 | Ghana
629 | Gambia (Republic of the)
630 | Guinea-Bissau (Republic of)
631 | Equatorial Guinea (Republic of)
632 | Guinea (Republic of)
633 | Burkina Faso
634 | Kenya (Republic of)
635 | France - Kerguelen Islands
636 | Liberia (Republic of)
637 | Liberia (Republic of)
638 | South Sudan (Republic of)
642 | Libya (State of)
644 | Lesotho (Kingdom of)
645 | Mauritius (Republic of)
647 | Madagascar (Republic of)
649 | Mali (Republic of)
650 | Mozambique (Republic of)
654 | Mauritania (Islamic Republic of)
655 | Malawi
656 | Niger (Republic of the)
657 | Nigeria (Federal Republic of)
659 | Namibia (Republic of)
660 | France - Reunion (French Department of)
661 | Rwanda (Republic of)
662 | Sudan (Republic of the)
663 | Senegal (Republic of)
664 | Seychelles (Republic of)
665 | United Kingdom of Great Britain and Northern Ireland - Saint Helena
666 | Somalia (Federal Republic of)
667 | Sierra Leone
668 | Sao Tome and Principe (Democratic Republic of)
669 | Eswatini (Kingdom of)
670 | Chad (Republic of)
671 | Togolese Republic
672 | Tunisia
674 | Tanzania (United Republic of)
675 | Uganda (Republic of)
676 | Democratic Republic of the Congo
677 | Tanzania (United Republic of)
678 | Zambia (Republic of)
679 | Zimbabwe (Republic of)
701 | Argentine Republic
710 | Brazil (Federative Republic of)
720 | Bolivia (Plurinational State of)
725 | Chile
730 | Colombia (Republic of)
735 | Ecuador
740 | United Kingdom of Great Britain and Northern Ireland - Falkland Islands (Malvinas)
745 | France - Guiana (French Department of)
750 | Guyana
755 | Paraguay (Republic of)
760 | Peru
765 | Suriname (Republic of)
770 | Uruguay (Eastern Republic of)
775 | Venezuela (Bolivarian Republic of)

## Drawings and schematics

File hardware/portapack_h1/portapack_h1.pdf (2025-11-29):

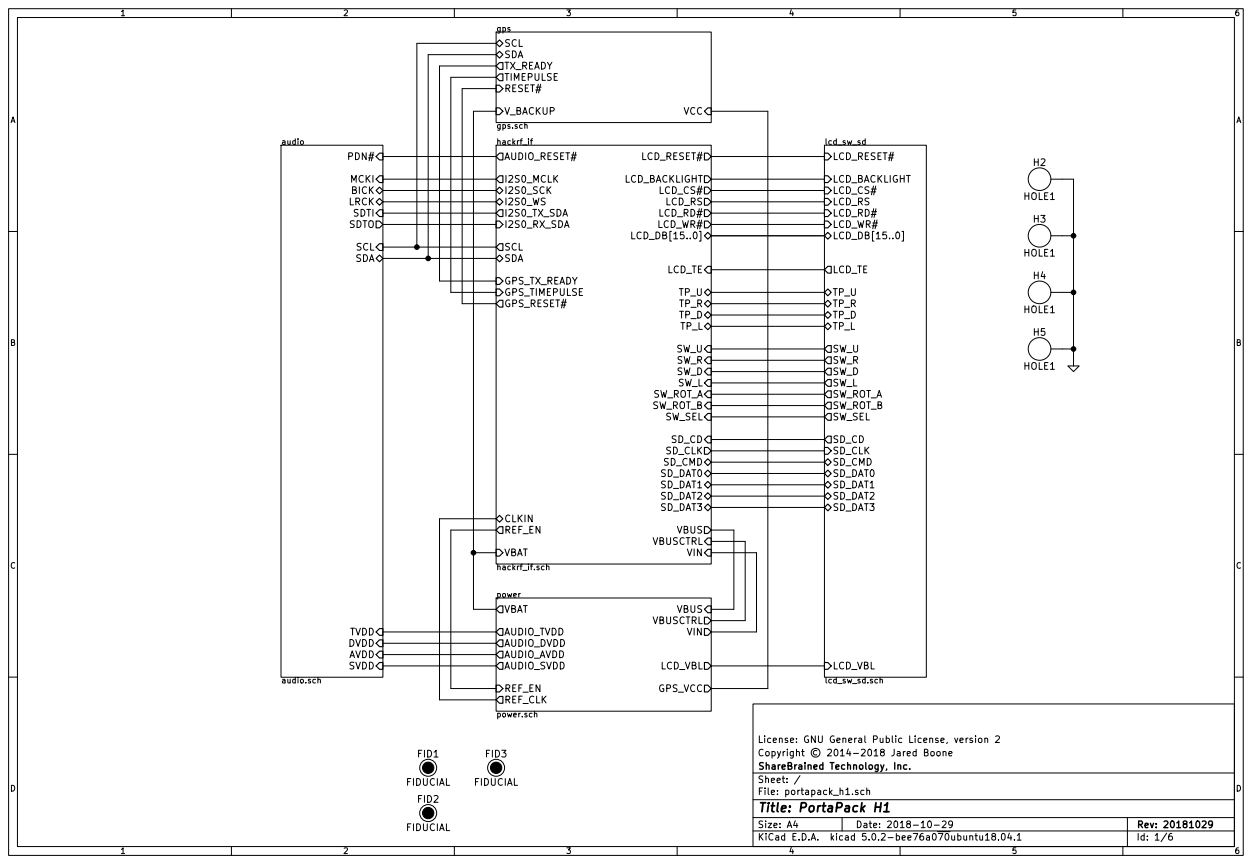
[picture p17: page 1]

License: GNU General Public License, version 2
Copyright © 2014-2018 Jared Boone
File: portapack_h1.sch Sheet: / ShareBrained Technology, Inc.

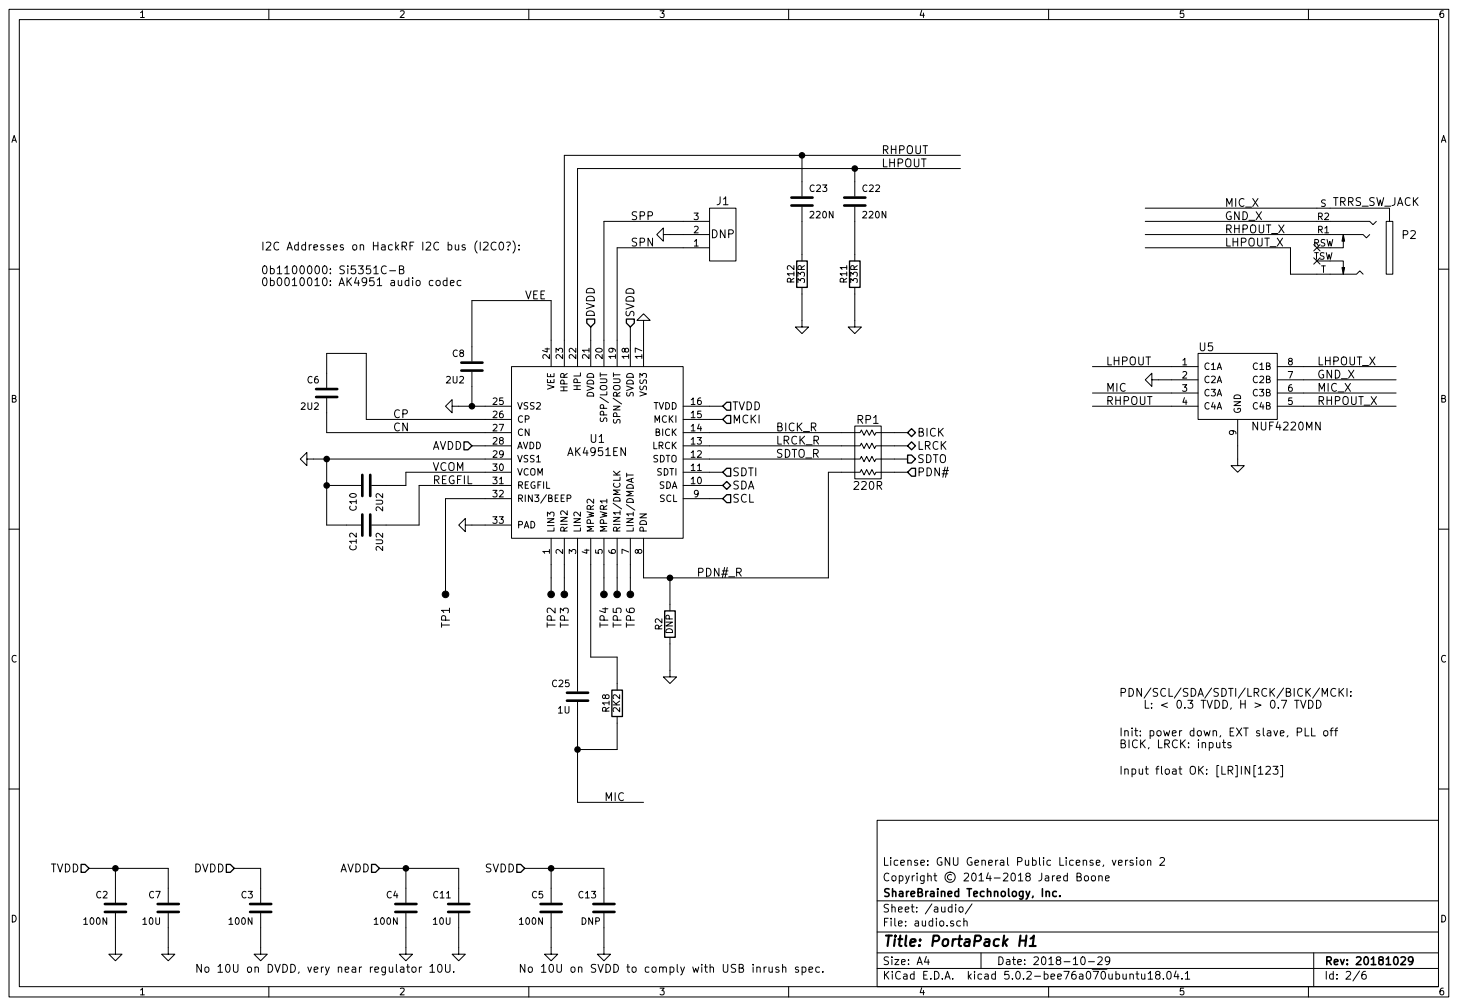
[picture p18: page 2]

I2C Addresses on HackRF I2C bus (I2C0?):

8 SCL 9 SDA 10 SPP/LOUT 20 VCOM 30 SDTI 11 DVDD 21 REGFIL 31 SDTO 12 HPL 22 RIN3/BEEP 32

LRCK_R
SDTO_R

PDN/SCL/SDA/SDTI/LRCK/BICK/MCKI:
L: < 0.3 TVDD, H > 0.7 TVDD

Init: power down, EXT slave, PLL off
BICK, LRCK: inputs

Copyright © 2014-2018 Jared Boone
File: audio.sch Sheet: /audio/ ShareBrained Technology, Inc.

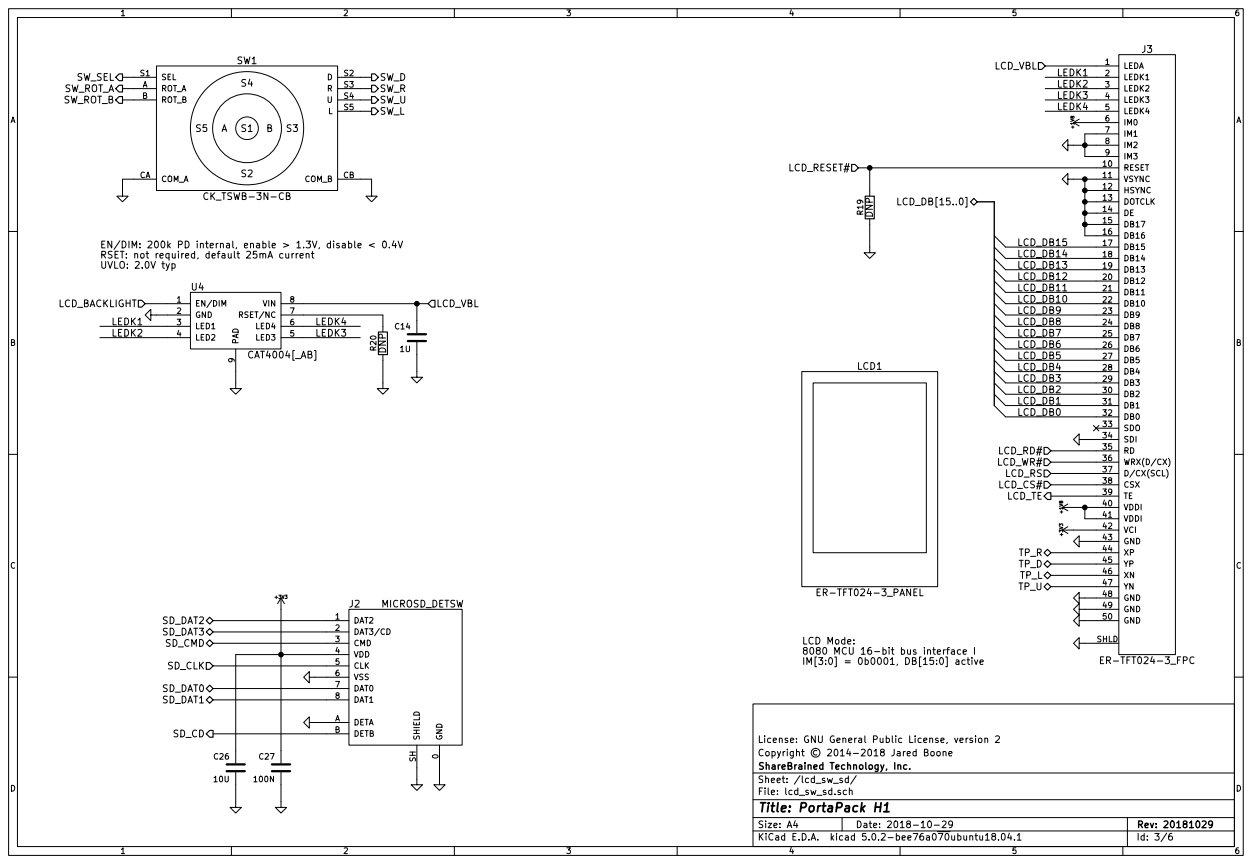
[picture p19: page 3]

EN/DIM: 200k PD internal, enable > 1.3V, disable < 0.4V
RSET: not required, default 25mA current
UVLO: 2.0V typ

LCD Mode:
8080 MCU 16-bit bus interface I
IM[3:0] = 0b0001, DB[15:0] active

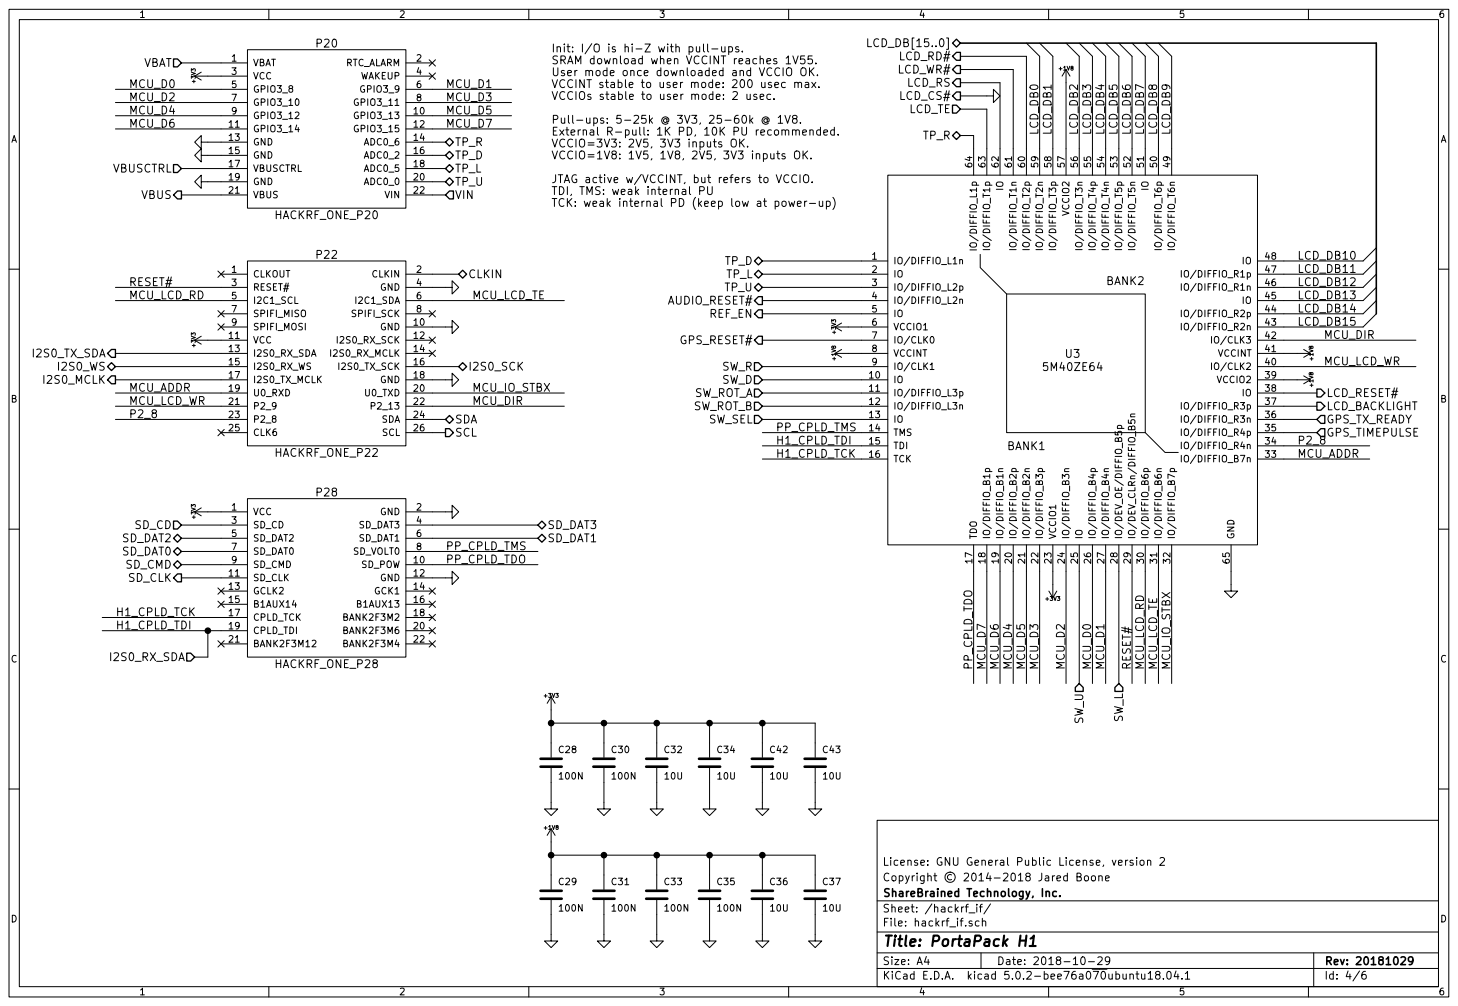
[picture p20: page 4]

Init: I/O is hi-Z with pull-ups.
SRAM download when VCCINT reaches 1V55.
User mode once downloaded and VCCIO OK.
VCCINT stable to user mode: 200 usec max.
VCCIOs stable to user mode: 2 usec.
Pull-ups: 5-25k @ 3V3, 25-60k @ 1V8.
External R-pull: 1K PD, 10K PU recommended.
VCCIO=3V3: 2V5, 3V3 inputs OK.
VCCIO=1V8: 1V5, 1V8, 2V5, 3V3 inputs OK.
JTAG active w/VCCINT, but refers to VCCIO.
TDI, TMS: weak internal PU
TCK: weak internal PD (keep low at power-up)

License: GNU General Public License, version 2
Copyright © 2014-2018 Jared Boone
ShareBrained Technology, Inc.
Sheet: /hackrf_if/
File: hackrf_if.sch
Id: 4/6 Title: PortaPack H1

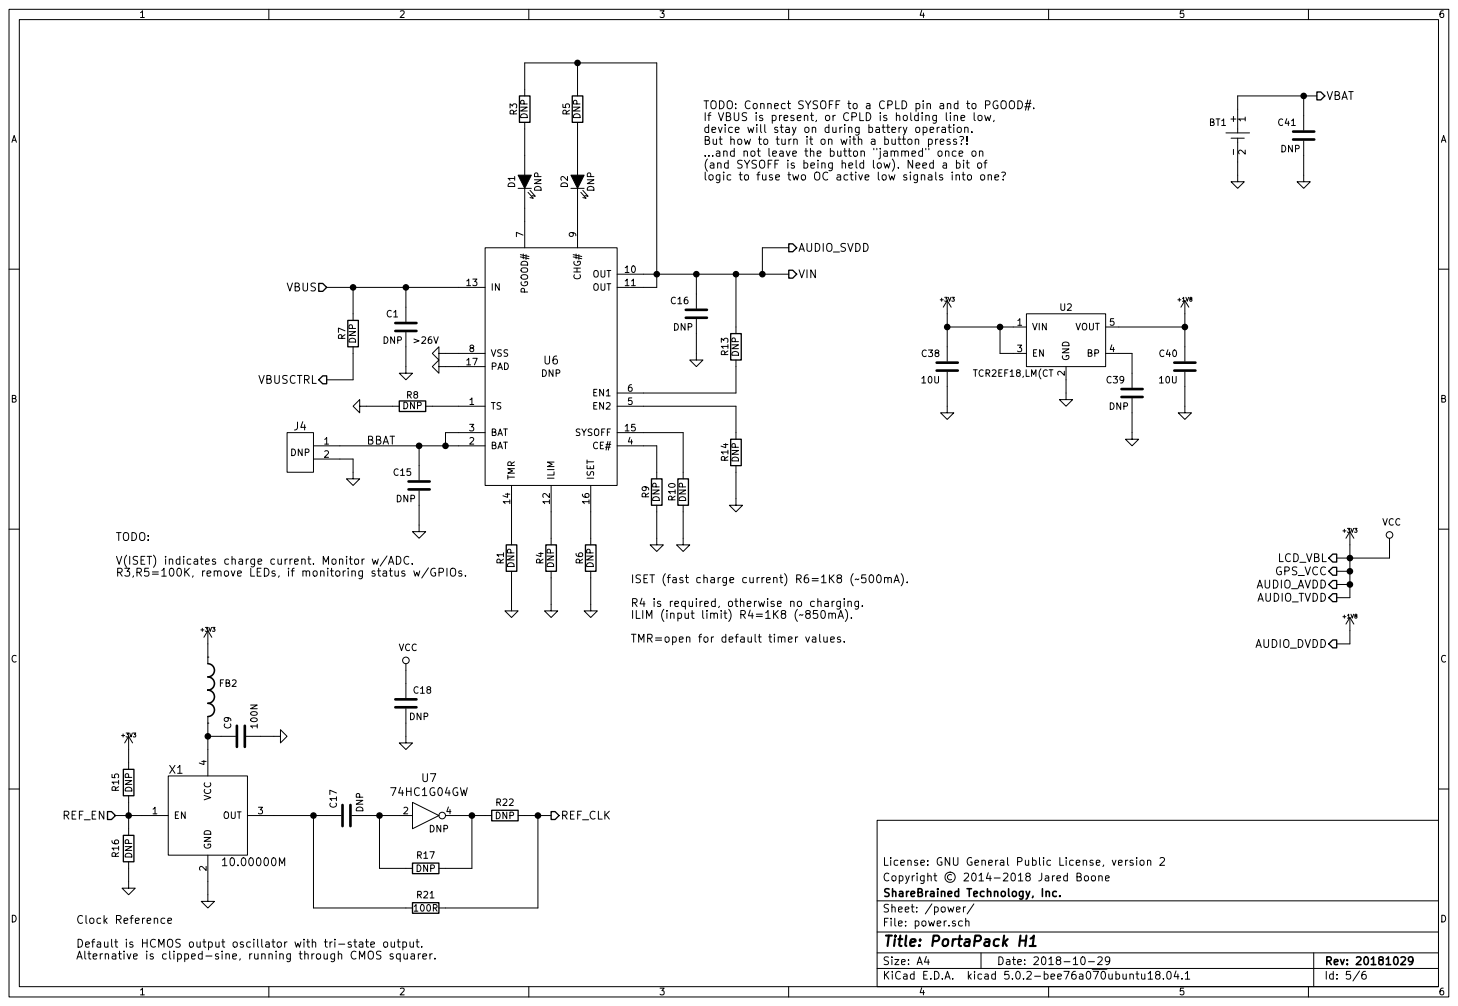
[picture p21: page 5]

TODO: Connect SYSOFF to a CPLD pin and to PGOOD#.
If VBUS is present, or CPLD is holding line low,
device will stay on during battery operation.
But how to turn it on with a button press?!
...and not leave the button "jammed" once on
(and SYSOFF is being held low). Need a bit of
logic to fuse two OC active low signals into one?

2 EN 3 BP 4 VOUT 5 U2 TCR2EF18,LM(CT C38

TODO:
V(ISET) indicates charge current. Monitor w/ADC.

R4 is required, otherwise no charging.
ILIM (input limit) R4=1K8 (850mA).

License: GNU General Public License, version 2
Copyright © 2014-2018 Jared Boone
ShareBrained Technology, Inc.
Sheet: /power/
File: power.sch
Id: 5/6 Title: PortaPack H1

Default is HCMOS output oscillator with tri-state output.

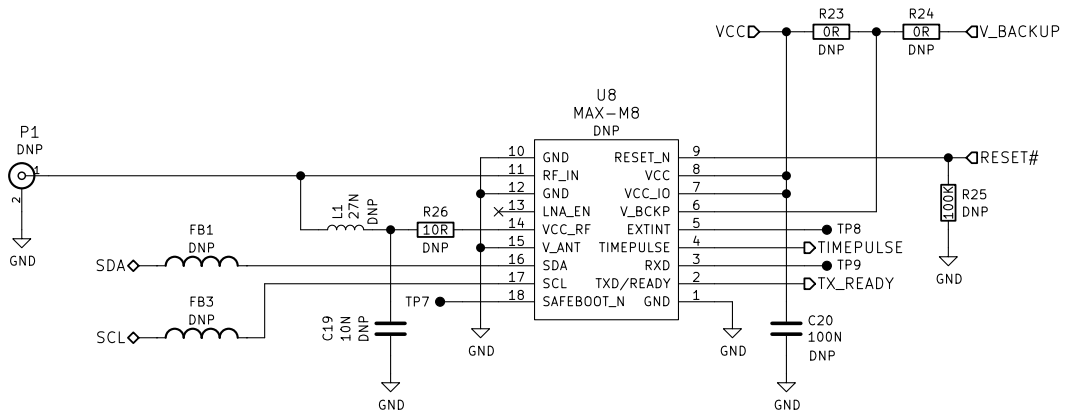
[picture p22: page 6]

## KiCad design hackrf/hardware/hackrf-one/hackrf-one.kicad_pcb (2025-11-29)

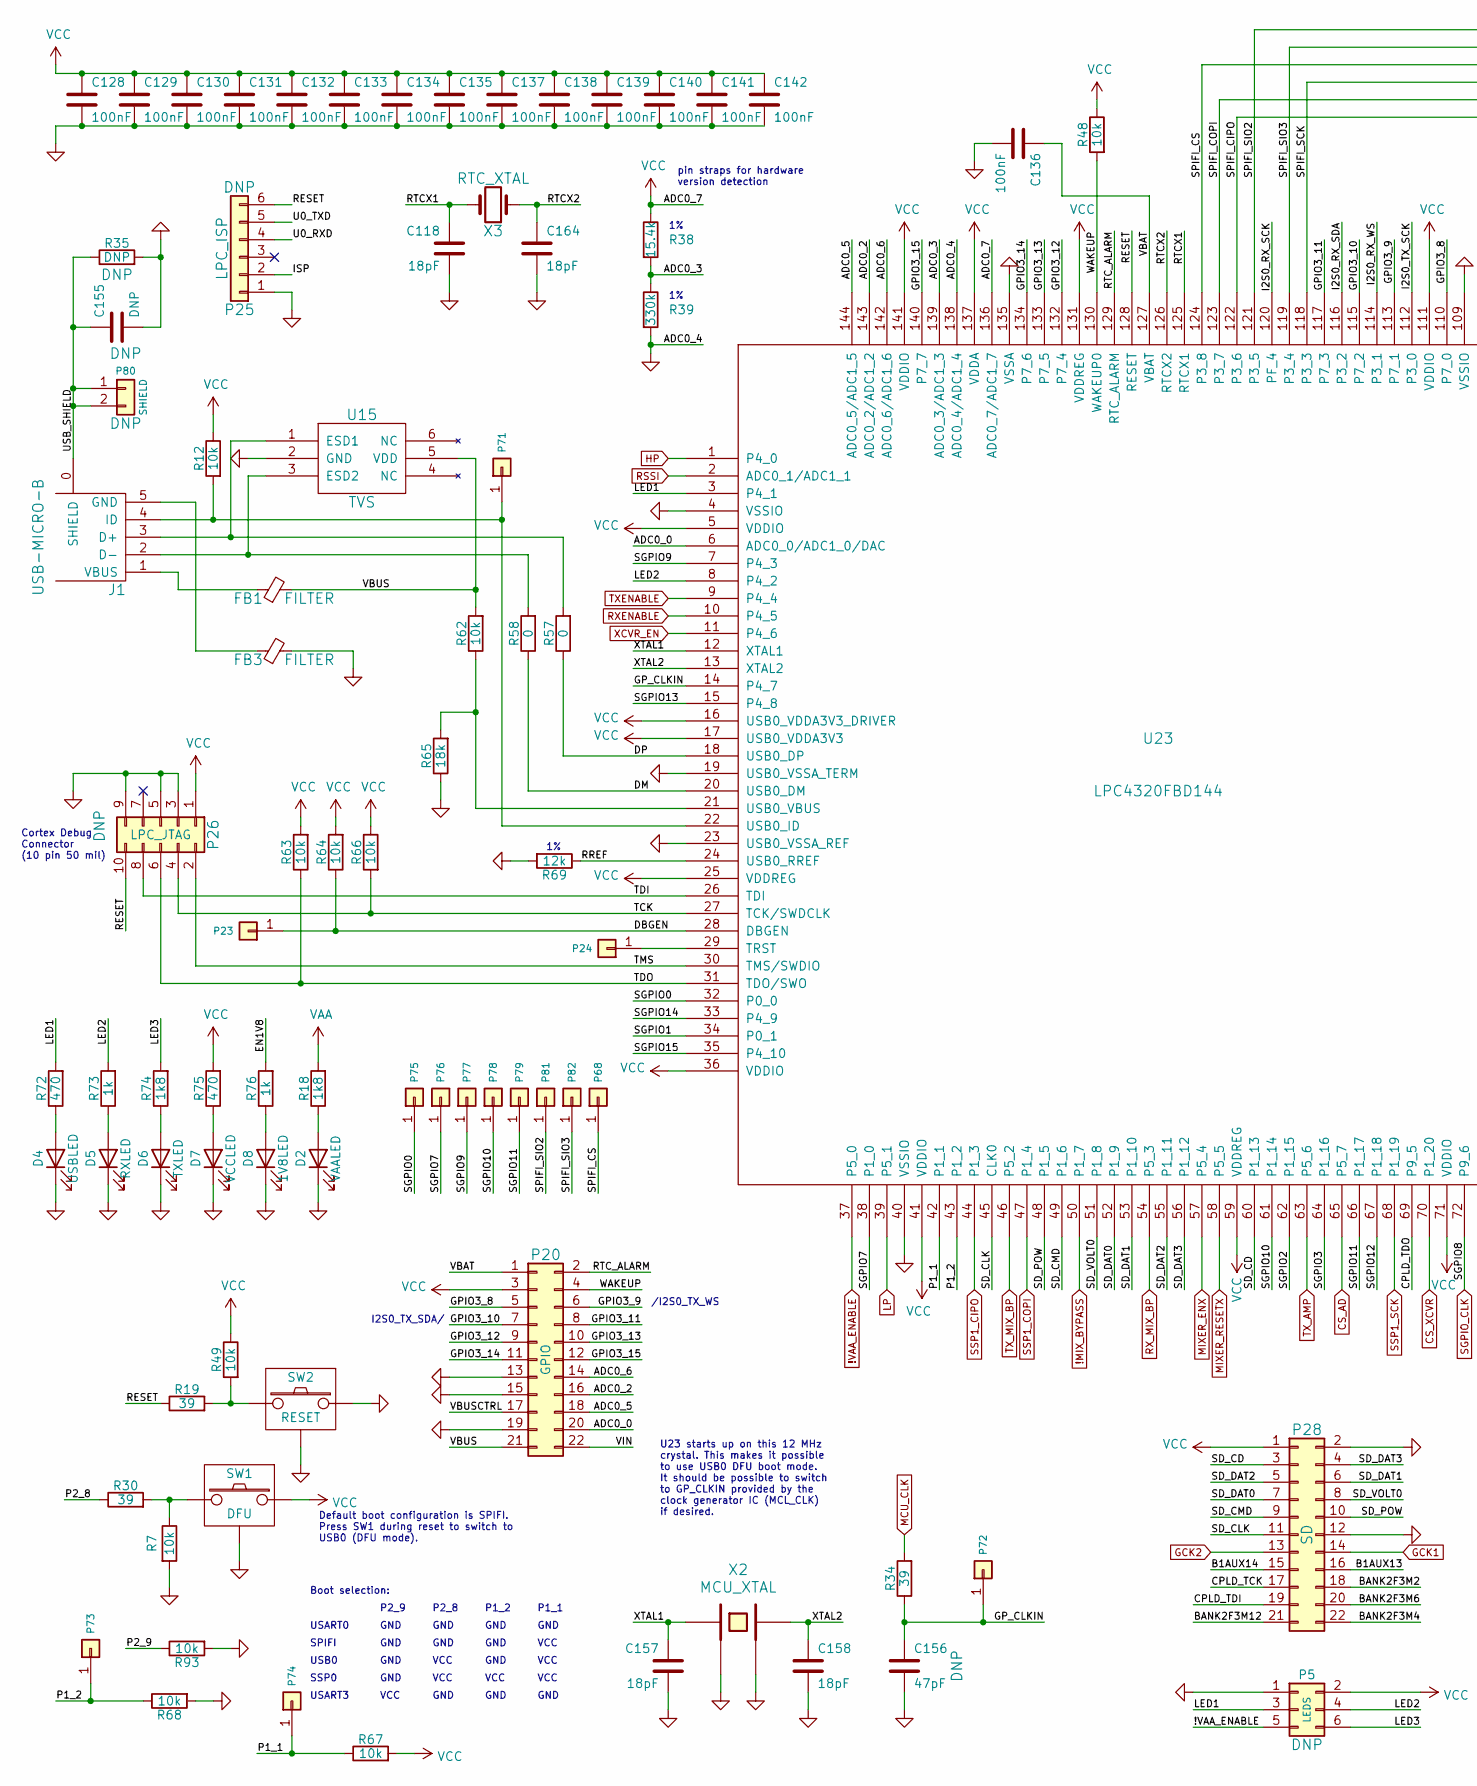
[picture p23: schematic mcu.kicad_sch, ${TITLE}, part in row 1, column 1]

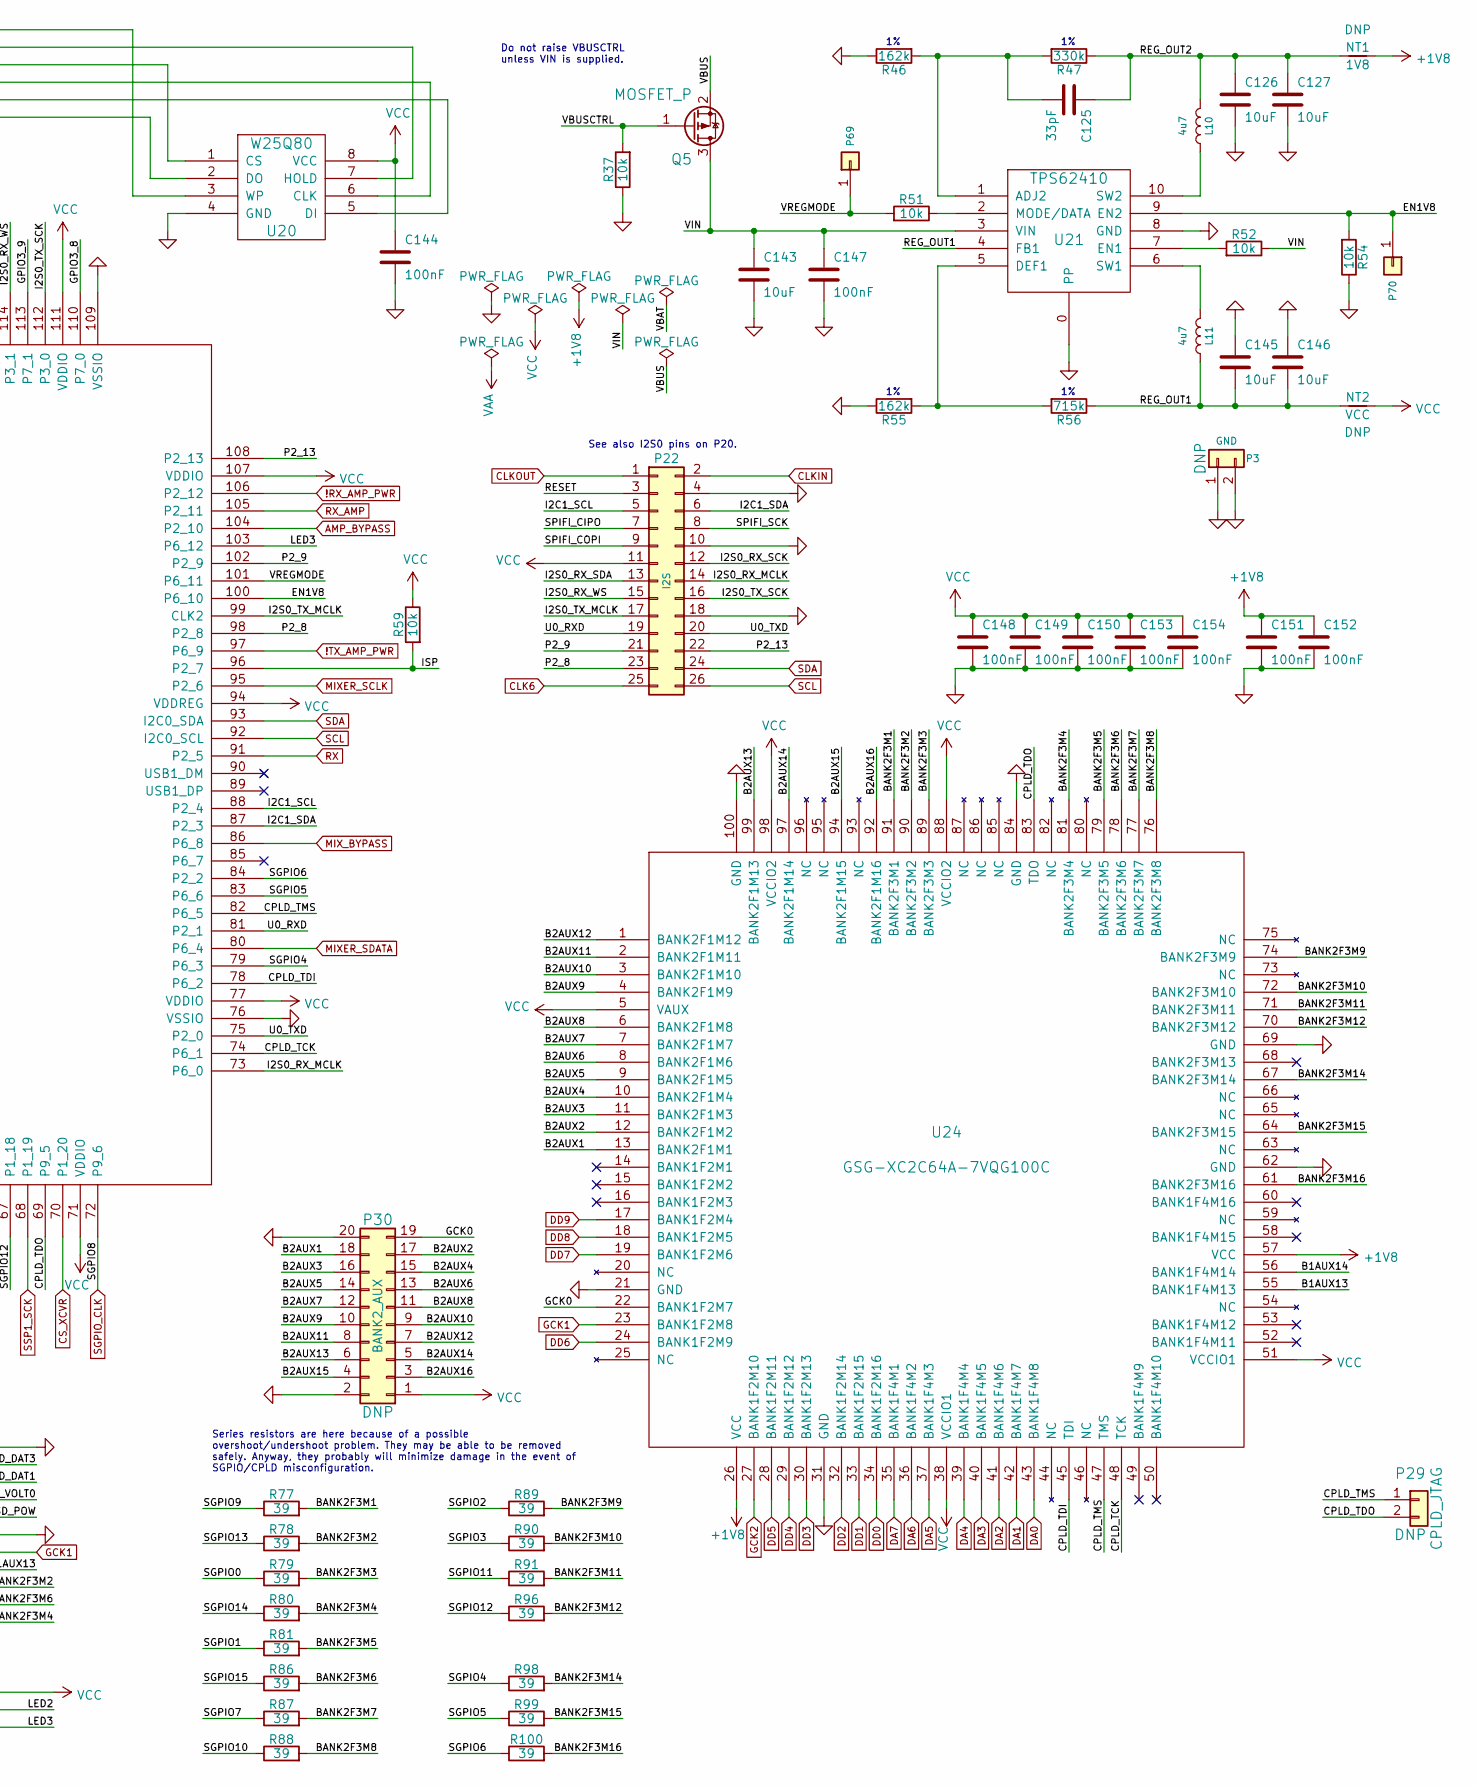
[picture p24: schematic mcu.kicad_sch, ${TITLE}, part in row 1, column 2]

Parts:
C118, C157, C158, C164: 18pF; GSG-0402; Part Number CL05C180JB5NNNC
C125: 33pF; GSG-0402; Part Number CL05C330JB5NNNC
C126, C127, C143, C145, C146: 10uF; GSG-0805; Part Number CL21A106KOQNNNE
C128, C129, C130, C131, C132, C133, C134, C135, C136, C137, C138, C139, C140, C141, C142, C144, C147, C148, C149, C150, C151, C152, C153, C154: 100nF; GSG-0402; Part Number CL05A104KA5NNNC
C155: DNP; GSG-0805
C156: 47pF; GSG-0402; Part Number CL05C470JB5NNNC
D2: VAALED; LTST-S220; Part Number LTST-S220KRKT
D4: USBLED; LTST-S220; Part Number LTST-S220KGKT
D5: RXLED; LTST-S220; Part Number LTST-S220KSKT
D6: TXLED; LTST-S220; Part Number LTST-S220KRKT
D7: VCCLED; LTST-S220; Part Number LTST-S220KGKT
D8: 1V8LED; LTST-S220; Part Number LTST-S220KSKT
FB1, FB3: FILTER; GSG-0805; Part Number BLM21PG221SN1D
J1: USB-MICRO-B; GSG-USB-MICROB-FCI-10103592-EXT; Part Number 10103592-0001LF
L10, L11: 4u7; GSG-NRG4026; Part Number NRS4018T4R7MDGJ
NT1: 1V8; HEADER-1x2-SHORTED
NT2: VCC; HEADER-1x2-SHORTED
P3: GND; GSG-HEADER-NOMARK-1x2
P5: LEDS; GSG-HEADER-2x3
P20: GPIO; GSG-HEADER-2x11; Part Number PPPC112LFBN-RC
P22: I2S; GSG-HEADER-2x13; Part Number PPPC132LFBN-RC
P23: DBGEN; GSG-TESTPOINT-50MIL
P24: TRST; GSG-TESTPOINT-50MIL
P25: LPC_ISP; GSG-HEADER-1x6
P26: LPC_JTAG; GSG-50MIL-HEADER-2x5-TH; Part Number GRPB052VWVN-RC
P28: SD; GSG-HEADER-2x11; Part Number PPPC112LFBN-RC
P29: CPLD_JTAG; GSG-HEADER-1x2
P30: BANK2_AUX; GSG-HEADER-2x10
P68: SPIFI_CS; GSG-TESTPOINT-50MIL
P69: VREGMODE; GSG-TESTPOINT-50MIL
P70: EN_1V8; GSG-TESTPOINT-50MIL
P71: ID; GSG-TESTPOINT-50MIL
P72: GP_CLKIN; GSG-TESTPOINT-50MIL
P73: P1_2; GSG-TESTPOINT-50MIL
P74: P1_1; GSG-TESTPOINT-50MIL
P75: SGPIO0; GSG-TESTPOINT-50MIL
P76: SGPIO7; GSG-TESTPOINT-50MIL
P77: SGPIO9; GSG-TESTPOINT-50MIL
P78: SGPIO10; GSG-TESTPOINT-50MIL
P79: SGPIO11; GSG-TESTPOINT-50MIL
P80: SHIELD; GSG-HEADER-NOMARK-1x2
P81: SPIFI_SIO2; GSG-TESTPOINT-50MIL
P82: SPIFI_SIO3; GSG-TESTPOINT-50MIL
Q5: MOSFET_P; SOT23-3; Part Number YJL2301C
R7, R12, R37, R48, R49, R51, R52, R54, R59, R62, R63, R64, R66, R67, R68, R93: 10k; GSG-0402; Part Number RMCF0402JT10K0
R18, R74: 1k8; GSG-0402; Part Number RMCF0402JT1K80
R19, R30, R34, R77, R78, R79, R80, R81, R86, R87, R88, R89, R90, R91, R96, R98, R99, R100: 39; GSG-0402; Part Number RMCF0402JT39R0
R35: DNP; GSG-0805
R38: 15.4k; GSG-0402; Part Number RC0402FR-0715K4L
R39, R47: 330k; GSG-0402; Part Number RMCF0402FT330K
R46, R55: 162k; GSG-0402; Part Number RMCF0402FT162K
R56: 715k; GSG-0402; Part Number RMCF0402FT715K
R57, R58: 0; GSG-0402; Part Number RMCF0402ZT0R00
R65: 18k; GSG-0402; Part Number RC0402JR-0718KL
R69: 12k; GSG-0402; Part Number RC0402FR-0712KL
R72, R75: 470; GSG-0402; Part Number RMCF0402JT470R
R73, R76: 1k; GSG-0402; Part Number RMCF0402FT1K00
SW1: DFU; GSG-SWITCH-FSMRA; Part Number FSMRA3JH
SW2: RESET; GSG-SWITCH-FSMRA; Part Number FSMRA3JH
U15: TVS; GSG-LXES1TBCC2-004; Part Number VBUS54CV-HSF-G4-08
U20: W25Q80; GSG-SOIC8-208; Part Number W25Q80DVSSIG
U21: TPS62410; GSG-S-PVSON-N10; Part Number TPS62410DRCR
U23: LPC4320FBD144; GSG-LQFP144; Part Number LPC4320FBD144,551
U24: GSG-XC2C64A-7VQG100C; GSG-VQ100; Part Number XC2C64A-7VQG100C
X2: MCU_XTAL; GSG-XTAL3.2x2.5mm; Part Number 7V-12.000MAAE-T
X3: RTC_XTAL; GSG-XTAL-AB26TRQ; Part Number AB26TRQ-32.768KHZ-T

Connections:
!MIX_BYPASS: U23.50 (P1_7); also elsewhere on the board
!RX_AMP_PWR: U23.106 (P2_12); also elsewhere on the board
!TX_AMP_PWR: U23.97 (P6_9); also elsewhere on the board
!VAA_ENABLE: P5.5, U23.37 (P5_0); also elsewhere on the board
+1V8: C151.1, C152.1, NT1.1, U24.26 (VCC), U24.57 (VCC)
/mcu/usb/power/ADC0_0: P20.20, U23.6 (ADC0_0/ADC1_0/DAC)
/mcu/usb/power/ADC0_2: P20.16, U23.143 (ADC0_2/ADC1_2)
/mcu/usb/power/ADC0_3: R38.2, R39.1, U23.139 (ADC0_3/ADC1_3)
/mcu/usb/power/ADC0_5: P20.18, U23.144 (ADC0_5/ADC1_5)
/mcu/usb/power/ADC0_6: P20.14, U23.142 (ADC0_6/ADC1_6)
/mcu/usb/power/B1AUX13: P28.16, U24.55 (BANK1F4M13)
/mcu/usb/power/B1AUX14: P28.15, U24.56 (BANK1F4M14)
/mcu/usb/power/B2AUX1: P30.18, U24.13 (BANK2F1M1)
/mcu/usb/power/B2AUX2: P30.17, U24.12 (BANK2F1M2)
/mcu/usb/power/B2AUX3: P30.16, U24.11 (BANK2F1M3)
/mcu/usb/power/B2AUX4: P30.15, U24.10 (BANK2F1M4)
/mcu/usb/power/B2AUX5: P30.14, U24.9 (BANK2F1M5)
/mcu/usb/power/B2AUX6: P30.13, U24.8 (BANK2F1M6)
/mcu/usb/power/B2AUX7: P30.12, U24.7 (BANK2F1M7)
/mcu/usb/power/B2AUX8: P30.11, U24.6 (BANK2F1M8)
/mcu/usb/power/B2AUX9: P30.10, U24.4 (BANK2F1M9)
/mcu/usb/power/B2AUX10: P30.9, U24.3 (BANK2F1M10)
/mcu/usb/power/B2AUX11: P30.8, U24.2 (BANK2F1M11)
/mcu/usb/power/B2AUX12: P30.7, U24.1 (BANK2F1M12)
/mcu/usb/power/B2AUX13: P30.6, U24.99 (BANK2F1M13)
/mcu/usb/power/B2AUX14: P30.5, U24.97 (BANK2F1M14)
/mcu/usb/power/B2AUX15: P30.4, U24.94 (BANK2F1M15)
/mcu/usb/power/B2AUX16: P30.3, U24.92 (BANK2F1M16)
/mcu/usb/power/BANK2F3M1: R77.2, U24.91 (BANK2F3M1)
/mcu/usb/power/BANK2F3M2: P28.18, R78.2, U24.90 (BANK2F3M2)
/mcu/usb/power/BANK2F3M3: R79.2, U24.89 (BANK2F3M3)
/mcu/usb/power/BANK2F3M4: P28.22, R80.2, U24.81 (BANK2F3M4)
/mcu/usb/power/BANK2F3M5: R81.2, U24.79 (BANK2F3M5)
/mcu/usb/power/BANK2F3M6: P28.20, R86.2, U24.78 (BANK2F3M6)
/mcu/usb/power/BANK2F3M7: R87.2, U24.77 (BANK2F3M7)
/mcu/usb/power/BANK2F3M8: R88.2, U24.76 (BANK2F3M8)
/mcu/usb/power/BANK2F3M9: R89.2, U24.74 (BANK2F3M9)
/mcu/usb/power/BANK2F3M10: R90.2, U24.72 (BANK2F3M10)
/mcu/usb/power/BANK2F3M11: R91.2, U24.71 (BANK2F3M11)
/mcu/usb/power/BANK2F3M12: P28.21, R96.2, U24.70 (BANK2F3M12)
/mcu/usb/power/BANK2F3M14: R98.2, U24.67 (BANK2F3M14)
/mcu/usb/power/BANK2F3M15: R99.2, U24.64 (BANK2F3M15)
/mcu/usb/power/BANK2F3M16: R100.2, U24.61 (BANK2F3M16)
/mcu/usb/power/CPLD_TCK: P28.17, U23.74 (P6_1), U24.48 (TCK)
/mcu/usb/power/CPLD_TDI: P28.19, U23.78 (P6_2), U24.45 (TDI)
/mcu/usb/power/CPLD_TDO: P29.2, U23.69 (P9_5), U24.83 (TDO)
/mcu/usb/power/CPLD_TMS: P29.1, U23.82 (P6_5), U24.47 (TMS)
/mcu/usb/power/DBGEN: P23.1, R64.1, U23.28 (DBGEN)
/mcu/usb/power/DM: R58.1, U23.20 (USB0_DM)
/mcu/usb/power/DP: R57.1, U23.18 (USB0_DP)
/mcu/usb/power/EN1V8: P70.1, R54.2, R76.2, U21.9 (EN2), U23.100 (P6_10)
/mcu/usb/power/GCK0: P30.19, U24.22 (BANK1F2M7)
/mcu/usb/power/GPIO3_8: P20.5, U23.110 (P7_0)
/mcu/usb/power/GPIO3_9: P20.6, U23.113 (P7_1)
/mcu/usb/power/GPIO3_10: P20.7, U23.115 (P7_2)
/mcu/usb/power/GPIO3_11: P20.8, U23.117 (P7_3)
/mcu/usb/power/GPIO3_12: P20.9, U23.132 (P7_4)
/mcu/usb/power/GPIO3_13: P20.10, U23.133 (P7_5)
/mcu/usb/power/GPIO3_14: P20.11, U23.134 (P7_6)
/mcu/usb/power/GPIO3_15: P20.12, U23.140 (P7_7)
/mcu/usb/power/GP_CLKIN: C156.1, P72.1, R34.1, U23.14 (P4_7)
/mcu/usb/power/I2C1_SCL: P22.5, U23.88 (P2_4)
/mcu/usb/power/I2C1_SDA: P22.6, U23.87 (P2_3)
/mcu/usb/power/I2S0_RX_MCLK: P22.14, U23.73 (P6_0)
/mcu/usb/power/I2S0_RX_SCK: P22.12, U23.120 (PF_4)
/mcu/usb/power/I2S0_RX_SDA: P22.13, U23.116 (P3_2)
/mcu/usb/power/I2S0_RX_WS: P22.15, U23.114 (P3_1)
/mcu/usb/power/I2S0_TX_MCLK: P22.17, U23.99 (CLK2)
/mcu/usb/power/I2S0_TX_SCK: P22.16, U23.112 (P3_0)
/mcu/usb/power/ISP: P25.2, R59.2, U23.96 (P2_7)
/mcu/usb/power/LED1: P5.3, R72.2, U23.3 (P4_1)
/mcu/usb/power/LED2: P5.4, R73.2, U23.8 (P4_2)
/mcu/usb/power/LED3: P5.6, R74.2, U23.103 (P6_12)
/mcu/usb/power/P1_1: P74.1, R67.1, U23.42 (P1_1)
/mcu/usb/power/P1_2: P73.1, R68.1, U23.43 (P1_2)
/mcu/usb/power/P2_8: P22.23, R30.1, U23.98 (P2_8)
/mcu/usb/power/P2_9: P22.21, R93.1, U23.102 (P2_9)
/mcu/usb/power/P2_13: P22.22, U23.108 (P2_13)
/mcu/usb/power/REG_OUT1: C145.2, C146.2, L11.1, NT2.2, R56.1, U21.4 (FB1)
/mcu/usb/power/REG_OUT2: C125.1, C126.1, C127.1, L10.2, NT1.2, R47.1
/mcu/usb/power/RESET: P22.3, P25.6, P26.10, R19.1, U23.128 (RESET)
/mcu/usb/power/RREF: R69.1, U23.24 (USB0_RREF)
/mcu/usb/power/RTCX1: C118.1, U23.125 (RTCX1), X3.2
/mcu/usb/power/RTCX2: C164.1, U23.126 (RTCX2), X3.1
/mcu/usb/power/RTC_ALARM: P20.2, U23.129 (RTC_ALARM)
/mcu/usb/power/SD_CD: P28.3, U23.60 (P1_13)
/mcu/usb/power/SD_CLK: P28.11, U23.45 (CLK0)
/mcu/usb/power/SD_CMD: P28.9, U23.49 (P1_6)
/mcu/usb/power/SD_DAT0: P28.7, U23.52 (P1_9)
/mcu/usb/power/SD_DAT1: P28.6, U23.53 (P1_10)
/mcu/usb/power/SD_DAT2: P28.5, U23.55 (P1_11)
/mcu/usb/power/SD_DAT3: P28.4, U23.56 (P1_12)
/mcu/usb/power/SD_POW: P28.10, U23.48 (P1_5)
/mcu/usb/power/SD_VOLT0: P28.8, U23.51 (P1_8)
/mcu/usb/power/SGPIO0: P75.1, R79.1, U23.32 (P0_0)
/mcu/usb/power/SGPIO1: R81.1, U23.34 (P0_1)
/mcu/usb/power/SGPIO2: R89.1, U23.62 (P1_15)
/mcu/usb/power/SGPIO3: R90.1, U23.64 (P1_16)
/mcu/usb/power/SGPIO4: R98.1, U23.79 (P6_3)
/mcu/usb/power/SGPIO5: R99.1, U23.83 (P6_6)
/mcu/usb/power/SGPIO6: R100.1, U23.84 (P2_2)
/mcu/usb/power/SGPIO7: P76.1, R87.1, U23.38 (P1_0)
/mcu/usb/power/SGPIO9: P77.1, R77.1, U23.7 (P4_3)
/mcu/usb/power/SGPIO10: P78.1, R88.1, U23.61 (P1_14)
/mcu/usb/power/SGPIO11: P79.1, R91.1, U23.66 (P1_17)
/mcu/usb/power/SGPIO12: R96.1, U23.67 (P1_18)
/mcu/usb/power/SGPIO13: R78.1, U23.15 (P4_8)
/mcu/usb/power/SGPIO14: R80.1, U23.33 (P4_9)
/mcu/usb/power/SGPIO15: R86.1, U23.35 (P4_10)
/mcu/usb/power/SPIFI_CIPO: P22.7, U20.2 (DO), U23.122 (P3_6)
/mcu/usb/power/SPIFI_COPI: P22.9, U20.5 (DI), U23.123 (P3_7)
/mcu/usb/power/SPIFI_CS: P68.1, U20.1 (CS), U23.124 (P3_8)
/mcu/usb/power/SPIFI_SCK: P22.8, U20.6 (CLK), U23.118 (P3_3)
/mcu/usb/power/SPIFI_SIO2: P81.1, U20.3 (WP), U23.121 (P3_5)
/mcu/usb/power/SPIFI_SIO3: P82.1, U20.7 (HOLD), U23.119 (P3_4)
/mcu/usb/power/TCK: P26.4, R66.2, U23.27 (TCK/SWDCLK)
/mcu/usb/power/TDI: P26.8, U23.26 (TDI)
/mcu/usb/power/TDO: P26.6, R63.1, U23.31 (TDO/SWO)
/mcu/usb/power/TMS: P26.2, U23.30 (TMS/SWDIO)
/mcu/usb/power/U0_RXD: P22.19, P25.4, U23.81 (P2_1)
/mcu/usb/power/U0_TXD: P22.20, P25.5, U23.75 (P2_0)
/mcu/usb/power/USB_SHIELD: C155.1, J1.0 (SHIELD), P80.1, P80.2, R35.1
/mcu/usb/power/VBAT: C136.1, P20.1, U23.127 (VBAT)
/mcu/usb/power/VBUS: FB1.2, P20.21, Q5.2 (S), R62.2, U15.5 (VDD)
/mcu/usb/power/VBUSCTRL: P20.17, Q5.1 (G), R37.2
/mcu/usb/power/VIN: C143.1, C147.1, P20.22, Q5.3 (D), R52.1, U21.3 (VIN)
/mcu/usb/power/VREGMODE: P69.1, R51.2, U23.101 (P6_11)
/mcu/usb/power/WAKEUP: P20.4, R48.2, U23.130 (WAKEUP0)
/mcu/usb/power/XTAL1: C157.1, U23.12 (XTAL1), X2.1
/mcu/usb/power/XTAL2: C158.1, U23.13 (XTAL2), X2.3
AMP_BYPASS: U23.104 (P2_10); also elsewhere on the board
CLK6: P22.25; also elsewhere on the board
CLKIN: P22.2; also elsewhere on the board
CLKOUT: P22.1; also elsewhere on the board
CS_AD: U23.65 (P5_7); also elsewhere on the board
CS_XCVR: U23.70 (P1_20); also elsewhere on the board
DA0: U24.43 (BANK1F4M8); also elsewhere on the board
DA1: U24.42 (BANK1F4M7); also elsewhere on the board
DA2: U24.41 (BANK1F4M6); also elsewhere on the board
DA3: U24.40 (BANK1F4M5); also elsewhere on the board
DA4: U24.39 (BANK1F4M4); also elsewhere on the board
DA5: U24.37 (BANK1F4M3); also elsewhere on the board
DA6: U24.36 (BANK1F4M2); also elsewhere on the board
DA7: U24.35 (BANK1F4M1); also elsewhere on the board
DD0: U24.34 (BANK1F2M16); also elsewhere on the board
DD1: U24.33 (BANK1F2M15); also elsewhere on the board
DD2: U24.32 (BANK1F2M14); also elsewhere on the board
DD3: U24.30 (BANK1F2M13); also elsewhere on the board
DD4: U24.29 (BANK1F2M12); also elsewhere on the board
DD5: U24.28 (BANK1F2M11); also elsewhere on the board
DD6: U24.24 (BANK1F2M9); also elsewhere on the board
DD7: U24.19 (BANK1F2M6); also elsewhere on the board
DD8: U24.18 (BANK1F2M5); also elsewhere on the board
DD9: U24.17 (BANK1F2M4); also elsewhere on the board
GCK1: P28.14, U24.23 (BANK1F2M8); also elsewhere on the board
GCK2: P28.13, U24.27 (BANK1F2M10); also elsewhere on the board
GND: C118.2, C126.2, C127.2, C128.2, C129.2, C130.2, C131.2, C132.2, C133.2, C134.2, C135.2, C136.2, C137.2, C138.2, C139.2, C140.2, C141.2, C142.2, C143.2, C144.2, C145.1, C146.1, C147.2, C148.2, C149.2, C150.2, C151.2, C152.2, C153.2, C154.2, C155.2, C156.2, C157.2, C158.2, C164.2, D2.1 (K), D4.1 (K), D5.1 (K), D6.1 (K), D7.1 (K), D8.1 (K), FB3.2, P3.1, P3.2, P5.1, P20.13, P20.15, P20.19, P22.4, P22.10, P22.18, P25.1, P26.3, P26.5, P26.9, P28.2, P28.12, P30.2, P30.20, R7.2, R35.2, R37.1, R39.2, R46.1, R54.1, R55.1, R65.1, R68.2, R69.2, R93.2, SW1.0 (SHIELD), SW2.0 (SHIELD), SW2.1, U15.2 (GND), U20.4 (GND), U21.0 (PP), U21.8 (GND), U23.4 (VSSIO), U23.19 (USB0_VSSA_TERM), U23.23 (USB0_VSSA_REF), U23.40 (VSSIO), U23.76 (VSSIO), U23.109 (VSSIO), U23.135 (VSSA), U23.138 (ADC0_4/ADC1_4), U24.21 (GND), U24.31 (GND), U24.62 (GND), U24.69 (GND), U24.84 (GND), U24.100 (GND), X2.2, X2.4; also elsewhere on the board
HP: U23.1 (P4_0); also elsewhere on the board
LP: U23.39 (P5_1); also elsewhere on the board
MCU_CLK: R34.2; also elsewhere on the board
MIXER_ENX: U23.57 (P5_4); also elsewhere on the board
MIXER_RESETX: U23.58 (P5_5); also elsewhere on the board
MIXER_SCLK: U23.95 (P2_6); also elsewhere on the board
MIXER_SDATA: U23.80 (P6_4); also elsewhere on the board
MIX_BYPASS: U23.86 (P6_8); also elsewhere on the board
unnamed: C125.2, R46.2, R47.2, U21.1 (ADJ2)
unnamed: D2.2 (A), R18.1
unnamed: D4.2 (A), R72.1
unnamed: D5.2 (A), R73.1
unnamed: D6.2 (A), R74.1
unnamed: D7.2 (A), R75.1
unnamed: D8.2 (A), R76.1
unnamed: FB1.1, J1.1 (VBUS)
unnamed: FB3.1, J1.5 (GND)
unnamed: J1.2 (D-), R58.2, U15.3 (ESD2)
unnamed: J1.3 (D+), R57.2, U15.1 (ESD1)
unnamed: J1.4 (ID), P71.1, R12.2, U23.22 (USB0_ID)
unnamed: L10.1, U21.10 (SW2)
unnamed: L11.2, U21.6 (SW1)
unnamed: P24.1, U23.29 (TRST)
unnamed: R19.2, R49.2, SW2.2
unnamed: R7.1, R30.2, SW1.2
unnamed: R51.1, U21.2 (MODE/DATA)
unnamed: R52.2, U21.7 (EN1)
unnamed: R55.2, R56.2, U21.5 (DEF1)
unnamed: R62.1, R65.2, U23.21 (USB0_VBUS)
RSSI: U23.2 (ADC0_1/ADC1_1); also elsewhere on the board
RX: U23.91 (P2_5); also elsewhere on the board
RXENABLE: U23.10 (P4_5); also elsewhere on the board
RX_AMP: U23.105 (P2_11); also elsewhere on the board
RX_MIX_BP: U23.54 (P5_3); also elsewhere on the board
SCL: P22.26, U23.92 (I2C0_SCL); also elsewhere on the board
SDA: P22.24, U23.93 (I2C0_SDA); also elsewhere on the board
SGPIO_CLK: U23.72 (P9_6); also elsewhere on the board
SSP1_CIPO: U23.44 (P1_3); also elsewhere on the board
SSP1_COPI: U23.47 (P1_4); also elsewhere on the board
SSP1_SCK: U23.68 (P1_19); also elsewhere on the board
TXENABLE: U23.9 (P4_4); also elsewhere on the board
TX_AMP: U23.63 (P5_6); also elsewhere on the board
TX_MIX_BP: U23.46 (P5_2); also elsewhere on the board
VAA: R18.2; also elsewhere on the board
VCC: C128.1, C129.1, C130.1, C131.1, C132.1, C133.1, C134.1, C135.1, C137.1, C138.1, C139.1, C140.1, C141.1, C142.1, C144.1, C148.1, C149.1, C150.1, C153.1, C154.1, NT2.1, P5.2, P20.3, P22.11, P26.1, P28.1, P30.1, R12.1, R38.1, R48.1, R49.1, R59.1, R63.2, R64.2, R66.1, R67.2, R75.2, SW1.1, U20.8 (VCC), U23.5 (VDDIO), U23.16 (USB0_VDDA3V3_DRIVER), U23.17 (USB0_VDDA3V3), U23.25 (VDDREG), U23.36 (VDDIO), U23.41 (VDDIO), U23.59 (VDDREG), U23.71 (VDDIO), U23.77 (VDDIO), U23.94 (VDDREG), U23.107 (VDDIO), U23.111 (VDDIO), U23.131 (VDDREG), U23.136 (ADC0_7/ADC1_7), U23.137 (VDDA), U23.141 (VDDIO), U24.5 (VAUX), U24.38 (VCCIO1), U24.51 (VCCIO1), U24.88 (VCCIO2), U24.98 (VCCIO2); also elsewhere on the board
XCVR_EN: U23.11 (P4_6); also elsewhere on the board

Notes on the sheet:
GND
VCC
Series resistors are here because of a possible overshoot/undershoot problem. They may be able to be removed safely. Anyway, they probably will minimize damage in the event of SGPIO/CPLD misconfiguration.
Default boot configuration is SPIFI. Press SW1 during reset to switch to USB0 (DFU mode).
I2S0_TX_SDA/
USB0
Boot selection:
pin straps for hardware version detection
See also I2S0 pins on P20.
/I2S0_TX_WS
USART0
SSP0
P2_8
P1_1
P2_9
USART3
Do not raise VBUSCTRL unless VIN is supplied.
Cortex Debug Connector (10 pin 50 mil)
P1_2
U23 starts up on this 12 MHz crystal. This makes it possible to use USB0 DFU boot mode. It should be possible to switch to GP_CLKIN provided by the clock generator IC (MCL_CLK) if desired.
SPIFI

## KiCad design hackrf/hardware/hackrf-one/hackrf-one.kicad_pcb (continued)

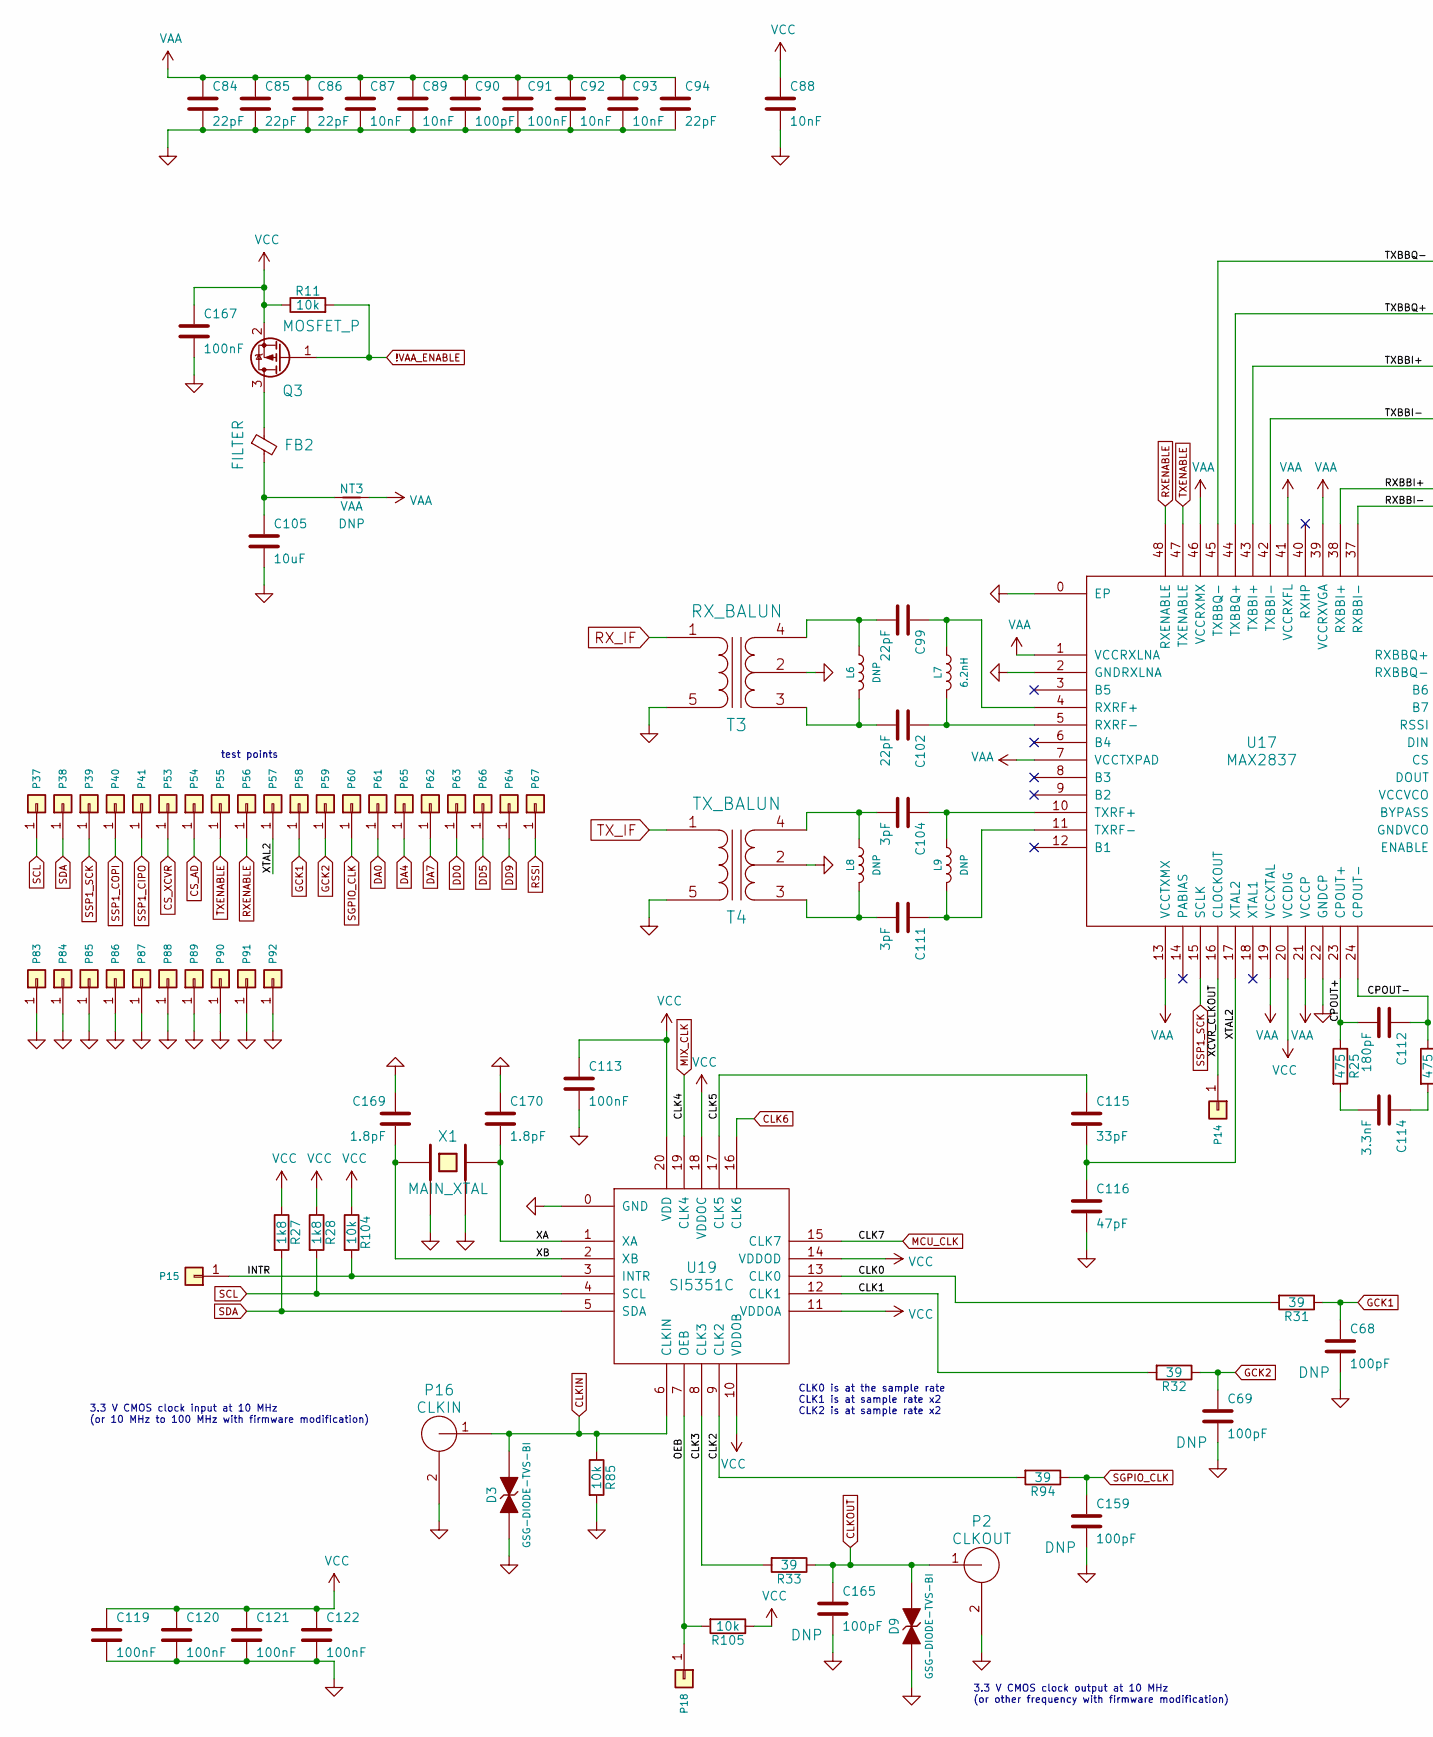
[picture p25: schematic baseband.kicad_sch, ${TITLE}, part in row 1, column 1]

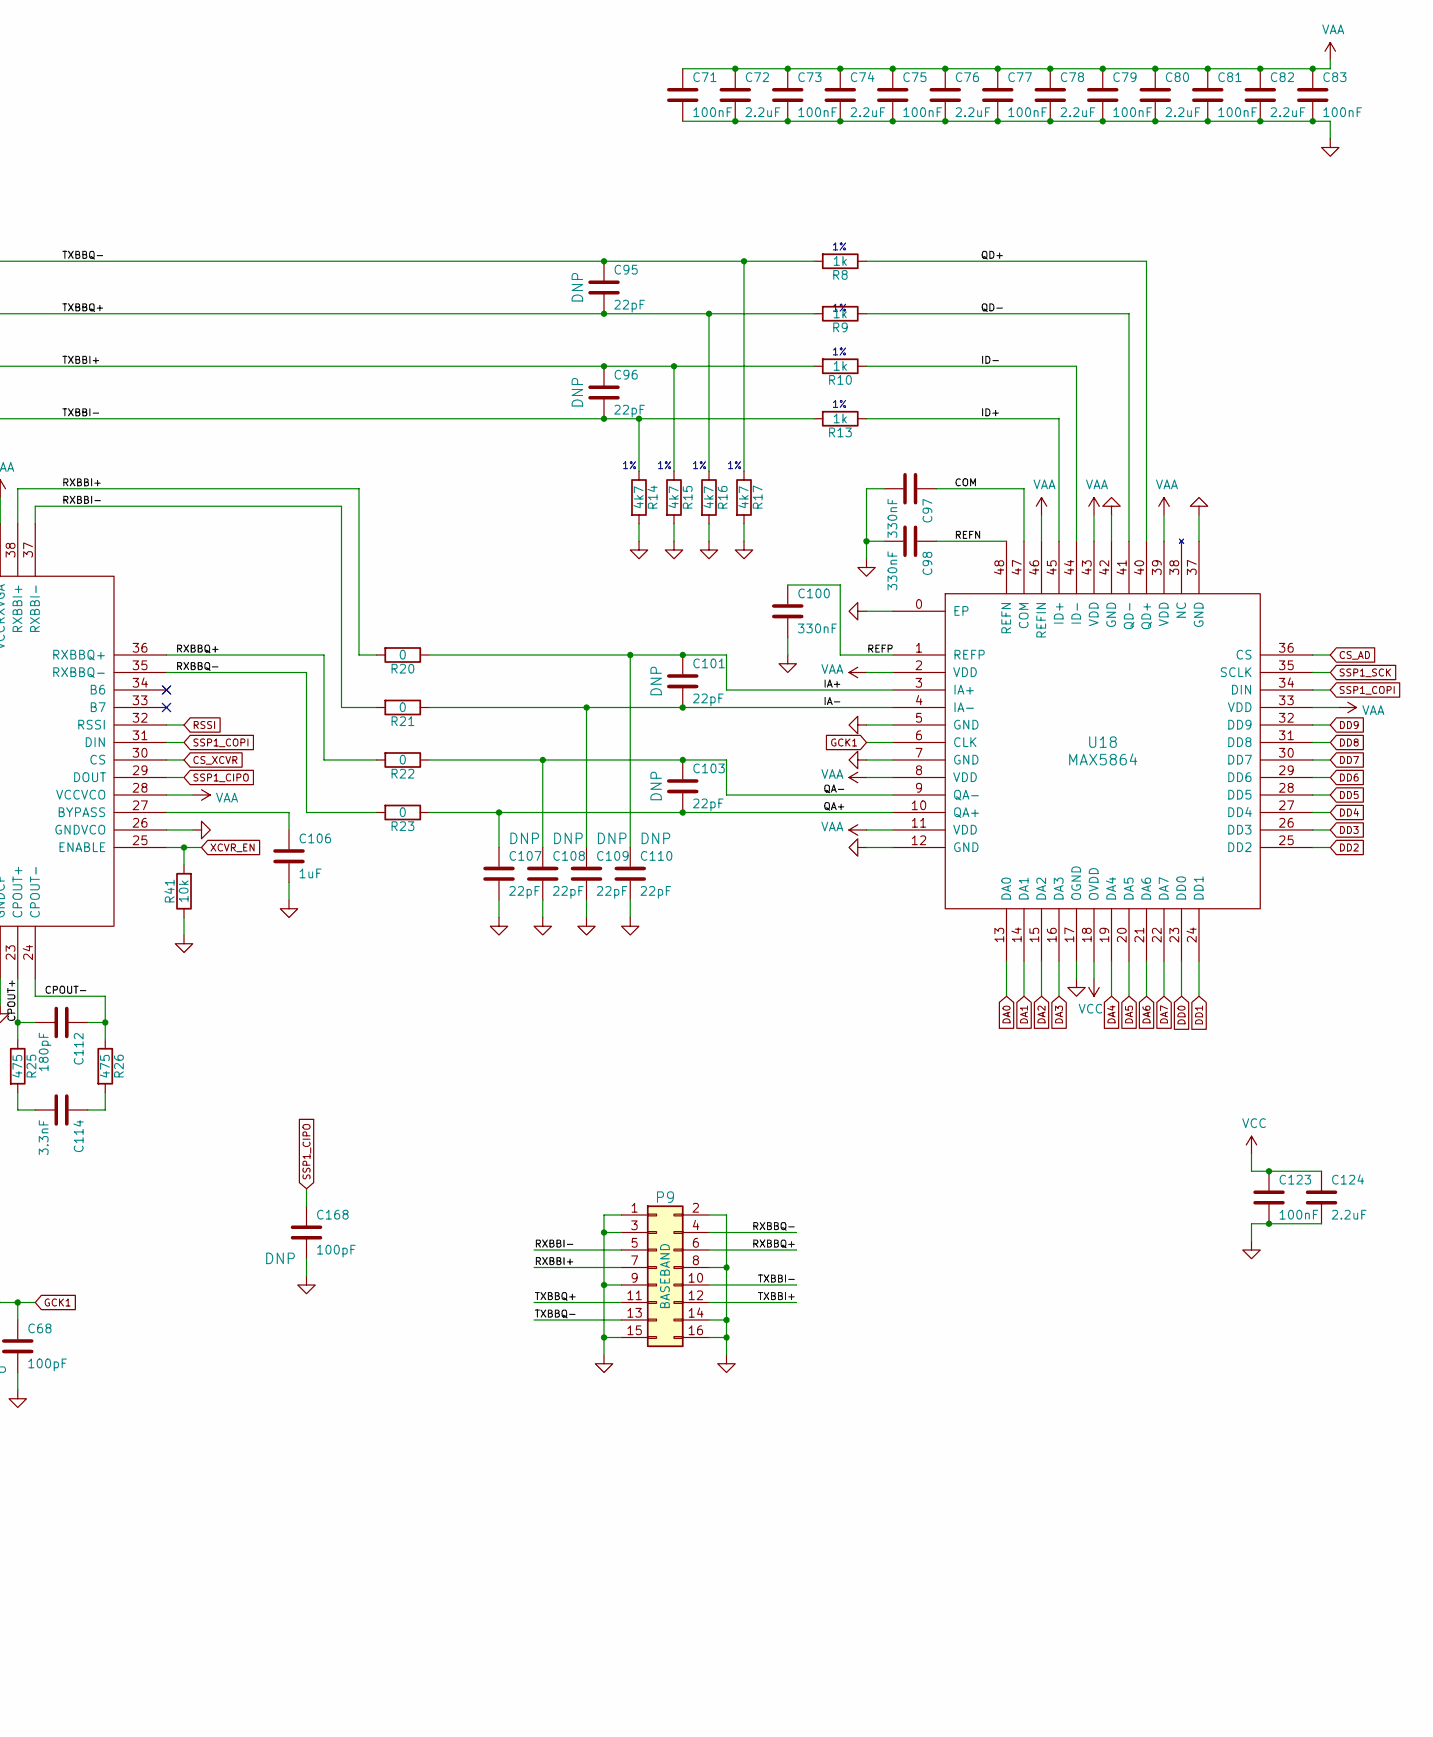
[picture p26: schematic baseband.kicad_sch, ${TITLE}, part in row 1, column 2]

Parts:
C68, C69, C90, C159, C165, C168: 100pF; GSG-0402; Part Number CL05C101JB5NNNC
C71, C73, C75, C77, C79, C81, C83, C91, C113, C119, C120, C121, C122, C123, C167: 100nF; GSG-0402; Part Number CL05A104KA5NNNC
C72, C74, C76, C78, C80, C82, C124: 2.2uF; GSG-0402; Part Number LMK105BJ225MV-F
C84, C85, C86, C94, C95, C96, C99, C101, C102, C103, C107, C108, C109, C110: 22pF; GSG-0402; Part Number CL05C220JB5NNNC
C87, C88, C89, C92, C93: 10nF; GSG-0402; Part Number CL05B103KB5NNNC
C97, C98, C100: 330nF; GSG-0402; Part Number CC0402KRX5R6BB334
C104, C111: 3pF; GSG-0402; Part Number GCM1555C1H3R0CA16D
C105: 10uF; GSG-0805; Part Number CL21A106KOQNNNE
C106: 1uF; GSG-0402; Part Number CL05A105KP5NNNC
C112: 180pF; GSG-0402; Part Number CC0402JRNPO9BN181
C114: 3.3nF; GSG-0402; Part Number CC0402KRX7R9BB332
C115: 33pF; GSG-0402; Part Number CL05C330JB5NNNC
C116: 47pF; GSG-0402; Part Number CL05C470JB5NNNC
C169, C170: 1.8pF; GSG-0402; Part Number CC0402CRNPO9BN1R8
D3, D9: GSG-DIODE-TVS-BI; GSG-0402; Part Number LXES15AAA1-100
FB2: FILTER; GSG-0805; Part Number BLM21PG221SN1D
L6, L8, L9: DNP; GSG-0402
L7: 6.2nH; GSG-0402; Part Number LQG15HS6N2S02D
NT3: VAA; HEADER-1x2-SHORTED
P2: CLKOUT; GSG-SMA-73251-2120; Part Number 73251-2121
P9: BASEBAND; GSG-HEADER-2x8; Part Number PPPC082LFBN-RC
P14: XCVR_CLKOUT; GSG-TESTPOINT-50MIL
P15: INTR; GSG-TESTPOINT-50MIL
P16: CLKIN; GSG-SMA-73251-2120; Part Number 73251-2121
P18: OEB; GSG-TESTPOINT-50MIL
P37: SCL; GSG-TESTPOINT-50MIL
P38: SDA; GSG-TESTPOINT-50MIL
P39: SSP1_SCK; GSG-TESTPOINT-50MIL
P40: SSP1_COPI; GSG-TESTPOINT-50MIL
P41: SSP1_CIPO; GSG-TESTPOINT-50MIL
P53: CS_XCVR; GSG-TESTPOINT-50MIL
P54: CS_AD; GSG-TESTPOINT-50MIL
P55: TXENABLE; GSG-TESTPOINT-50MIL
P56: RXENABLE; GSG-TESTPOINT-50MIL
P57: XTAL2; GSG-TESTPOINT-50MIL
P58: GCK1; GSG-TESTPOINT-50MIL
P59: GCK2; GSG-TESTPOINT-50MIL
P60: SGPIO_CLK; GSG-TESTPOINT-50MIL
P61: DA0; GSG-TESTPOINT-50MIL
P62: DA7; GSG-TESTPOINT-50MIL
P63: DD0; GSG-TESTPOINT-50MIL
P64: DD9; GSG-TESTPOINT-50MIL
P65: DA4; GSG-TESTPOINT-50MIL
P66: DD5; GSG-TESTPOINT-50MIL
P67: RSSI; GSG-TESTPOINT-50MIL
P83, P84, P85, P86, P87, P88, P89, P90, P91, P92: GND; GSG-TESTPOINT-50MIL
Q3: MOSFET_P; SOT23-3; Part Number YJL2301C
R8, R9, R10, R13: 1k; GSG-0402; Part Number RMCF0402FT1K00
R11, R41, R85, R104, R105: 10k; GSG-0402; Part Number RMCF0402JT10K0
R14, R15, R16, R17: 4k7; GSG-0402; Part Number RMCF0402FT4K70
R20, R21, R22, R23: 0; GSG-0402; Part Number RMCF0402ZT0R00
R25, R26: 475; GSG-0402; Part Number RMCF0402JT470R
R27, R28: 1k8; GSG-0402; Part Number RMCF0402JT1K80
R31, R32, R33, R94: 39; GSG-0402; Part Number RMCF0402JT39R0
T3: RX_BALUN; GSG-2500BL14M100; Part Number 2500BL14M100T
T4: TX_BALUN; GSG-2500BL14M100; Part Number 2500BL14M100T
U17: MAX2837; GSG-QFN48-6; Part Number MAX2837ETM+T
U18: MAX5864; GSG-QFN48-7; Part Number MAX5864ETM+T
U19: SI5351C; GSG-QFN20-4; Part Number SI5351C-B-GM
X1: MAIN_XTAL; GSG-XTAL3.2x2.5mm; Part Number ABM8-25.000MHZ-10-D1G-T

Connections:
!VAA_ENABLE: Q3.1 (G), R11.2; also elsewhere on the board
/baseband/CLK0: R31.2, U19.13 (CLK0)
/baseband/CLK1: R32.2, U19.12 (CLK1)
/baseband/CLK2: R94.2, U19.9 (CLK2)
/baseband/CLK3: R33.2, U19.8 (CLK3)
/baseband/CLK5: C115.1, U19.17 (CLK5)
/baseband/COM: C97.1, U18.47 (COM)
/baseband/CPOUT+: C112.2, R25.1, U17.23 (CPOUT+)
/baseband/CPOUT-: C112.1, R26.1, U17.24 (CPOUT-)
/baseband/IA+: C101.1, C110.1, R20.1, U18.3 (IA+)
/baseband/IA-: C101.2, C109.1, R21.1, U18.4 (IA-)
/baseband/ID+: R13.1, U18.45 (ID+)
/baseband/ID-: R10.1, U18.44 (ID-)
/baseband/INTR: P15.1, R104.2, U19.3 (INTR)
/baseband/OEB: P18.1, R105.2, U19.7 (OEB)
/baseband/QA+: C103.2, C107.1, R23.1, U18.10 (QA+)
/baseband/QA-: C103.1, C108.1, R22.1, U18.9 (QA-)
/baseband/QD+: R8.1, U18.40 (QD+)
/baseband/QD-: R9.1, U18.41 (QD-)
/baseband/REFN: C98.1, U18.48 (REFN)
/baseband/REFP: C100.1, U18.1 (REFP)
/baseband/RXBBI+: P9.7, R20.2, U17.38 (RXBBI+)
/baseband/RXBBI-: P9.5, R21.2, U17.37 (RXBBI-)
/baseband/RXBBQ+: P9.6, R22.2, U17.36 (RXBBQ+)
/baseband/RXBBQ-: P9.4, R23.2, U17.35 (RXBBQ-)
/baseband/TXBBI+: C96.1, P9.12, R10.2, R15.1, U17.43 (TXBBI+)
/baseband/TXBBI-: C96.2, P9.10, R13.2, R14.1, U17.42 (TXBBI-)
/baseband/TXBBQ+: C95.2, P9.11, R9.2, R16.1, U17.44 (TXBBQ+)
/baseband/TXBBQ-: C95.1, P9.13, R8.2, R17.1, U17.45 (TXBBQ-)
/baseband/XA: C170.2, U19.1 (XA), X1.3
/baseband/XB: C169.2, U19.2 (XB), X1.1
/baseband/XCVR_CLKOUT: P14.1, U17.16 (CLOCKOUT)
/baseband/XTAL2: C115.2, C116.1, P57.1, U17.17 (XTAL2)
CLK6: U19.16 (CLK6); also elsewhere on the board
CLKIN: D3.2 (K), P16.1 (RF), R85.1, U19.6 (CLKIN); also elsewhere on the board
CLKOUT: C165.1, D9.2 (K), P2.1 (RF), R33.1; also elsewhere on the board
CS_AD: P54.1, U18.36 (CS); also elsewhere on the board
CS_XCVR: P53.1, U17.30 (CS); also elsewhere on the board
DA0: P61.1, U18.13 (DA0); also elsewhere on the board
DA1: U18.14 (DA1); also elsewhere on the board
DA2: U18.15 (DA2); also elsewhere on the board
DA3: U18.16 (DA3); also elsewhere on the board
DA4: P65.1, U18.19 (DA4); also elsewhere on the board
DA5: U18.20 (DA5); also elsewhere on the board
DA6: U18.21 (DA6); also elsewhere on the board
DA7: P62.1, U18.22 (DA7); also elsewhere on the board
DD0: P63.1, U18.23 (DD0); also elsewhere on the board
DD1: U18.24 (DD1); also elsewhere on the board
DD2: U18.25 (DD2); also elsewhere on the board
DD3: U18.26 (DD3); also elsewhere on the board
DD4: U18.27 (DD4); also elsewhere on the board
DD5: P66.1, U18.28 (DD5); also elsewhere on the board
DD6: U18.29 (DD6); also elsewhere on the board
DD7: U18.30 (DD7); also elsewhere on the board
DD8: U18.31 (DD8); also elsewhere on the board
DD9: P64.1, U18.32 (DD9); also elsewhere on the board
GCK1: C68.1, P58.1, R31.1, U18.6 (CLK); also elsewhere on the board
GCK2: C69.1, P59.1, R32.1; also elsewhere on the board
GND: C68.2, C69.2, C71.2, C72.2, C73.2, C74.2, C75.2, C76.2, C77.2, C78.2, C79.2, C80.2, C81.2, C82.2, C83.2, C84.2, C85.2, C86.2, C87.2, C88.2, C89.2, C90.2, C91.2, C92.2, C93.2, C94.2, C97.2, C98.2, C100.2, C105.2, C106.2, C107.2, C108.2, C109.2, C110.2, C113.2, C116.2, C119.2, C120.2, C121.2, C122.2, C123.2, C124.2, C159.2, C165.2, C167.2, C168.2, C169.1, C170.1, D3.1 (A), D9.1 (A), P2.2 (GND), P9.1, P9.2, P9.3, P9.8, P9.9, P9.14, P9.15, P9.16, P16.2 (GND), P83.1, P84.1, P85.1, P86.1, P87.1, P88.1, P89.1, P90.1, P91.1, P92.1, R14.2, R15.2, R16.2, R17.2, R41.1, R85.2, T3.2 (PC), T3.5 (S2), T4.2 (PC), T4.5 (S2), U17.0 (EP), U17.2 (GNDRXLNA), U17.22 (GNDCP), U17.26 (GNDVCO), U18.0 (EP), U18.5 (GND), U18.7 (GND), U18.12 (GND), U18.17 (OGND), U18.37 (GND), U18.42 (GND), U19.0 (GND), X1.2, X1.4; also elsewhere on the board
MCU_CLK: U19.15 (CLK7); also elsewhere on the board
MIX_CLK: U19.19 (CLK4); also elsewhere on the board
unnamed: C99.1, L7.1, U17.4 (RXRF+)
unnamed: C99.2, L6.1, T3.4 (PR2)
unnamed: C102.1, L7.2, U17.5 (RXRF-)
unnamed: C102.2, L6.2, T3.3 (PR1)
unnamed: C104.1, L9.1, U17.10 (TXRF+)
unnamed: C104.2, L8.1, T4.4 (PR2)
unnamed: C105.1, FB2.2, NT3.2
unnamed: C106.1, U17.27 (BYPASS)
unnamed: C111.1, L9.2, U17.11 (TXRF-)
unnamed: C111.2, L8.2, T4.3 (PR1)
unnamed: C114.1, R26.2
unnamed: C114.2, R25.2
unnamed: FB2.1, Q3.3 (D)
RSSI: P67.1, U17.32 (RSSI); also elsewhere on the board
RXENABLE: P56.1, U17.48 (RXENABLE); also elsewhere on the board
RX_IF: T3.1 (S1); also elsewhere on the board
SCL: P37.1, R28.2, U19.4 (SCL); also elsewhere on the board
SDA: P38.1, R27.2, U19.5 (SDA); also elsewhere on the board
SGPIO_CLK: C159.1, P60.1, R94.1; also elsewhere on the board
SSP1_CIPO: C168.1, P41.1, U17.29 (DOUT); also elsewhere on the board
SSP1_COPI: P40.1, U17.31 (DIN), U18.34 (DIN); also elsewhere on the board
SSP1_SCK: P39.1, U17.15 (SCLK), U18.35 (SCLK); also elsewhere on the board
TXENABLE: P55.1, U17.47 (TXENABLE); also elsewhere on the board
TX_IF: T4.1 (S1); also elsewhere on the board
VAA: C71.1, C72.1, C73.1, C74.1, C75.1, C76.1, C77.1, C78.1, C79.1, C80.1, C81.1, C82.1, C83.1, C84.1, C85.1, C86.1, C87.1, C89.1, C90.1, C91.1, C92.1, C93.1, C94.1, NT3.1, U17.1 (VCCRXLNA), U17.7 (VCCTXPAD), U17.13 (VCCTXMX), U17.19 (VCCXTAL), U17.21 (VCCCP), U17.28 (VCCVCO), U17.39 (VCCRXVGA), U17.41 (VCCRXFL), U17.46 (VCCRXMX), U18.2 (VDD), U18.8 (VDD), U18.11 (VDD), U18.33 (VDD), U18.39 (VDD), U18.43 (VDD), U18.46 (REFIN); also elsewhere on the board
VCC: C88.1, C113.1, C119.1, C120.1, C121.1, C122.1, C123.1, C124.1, C167.1, Q3.2 (S), R11.1, R27.1, R28.1, R104.1, R105.1, U17.20 (VCCDIG), U18.18 (OVDD), U19.10 (VDDOB), U19.11 (VDDOA), U19.14 (VDDOD), U19.18 (VDDOC), U19.20 (VDD); also elsewhere on the board
XCVR_EN: R41.2, U17.25 (ENABLE); also elsewhere on the board

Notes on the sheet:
3.3 V CMOS clock input at 10 MHz (or 10 MHz to 100 MHz with firmware modification)
CLK0 is at the sample rate CLK1 is at sample rate x2 CLK2 is at sample rate x2
test points
3.3 V CMOS clock output at 10 MHz (or other frequency with firmware modification)

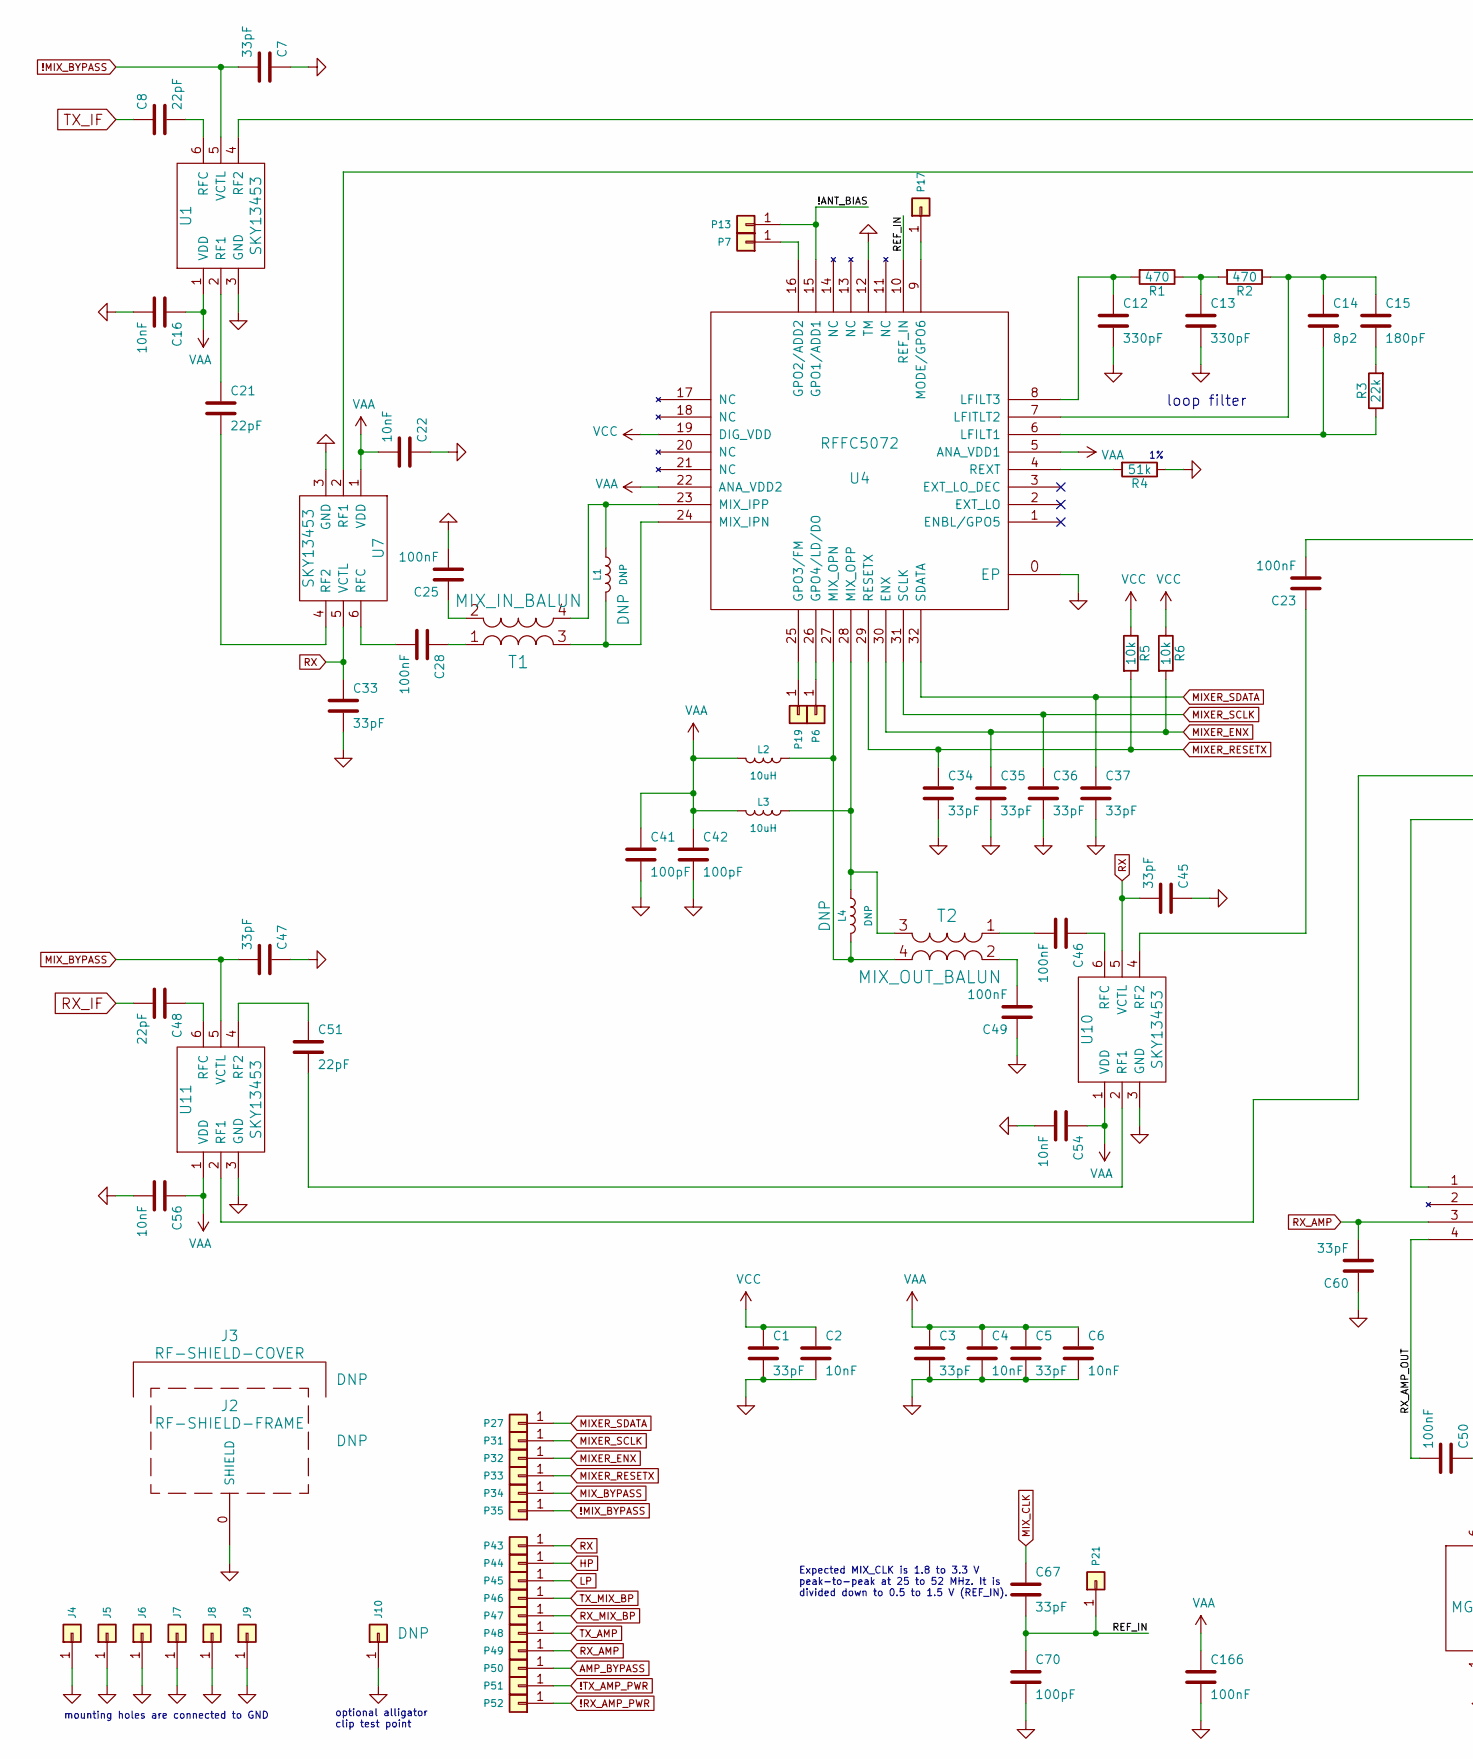
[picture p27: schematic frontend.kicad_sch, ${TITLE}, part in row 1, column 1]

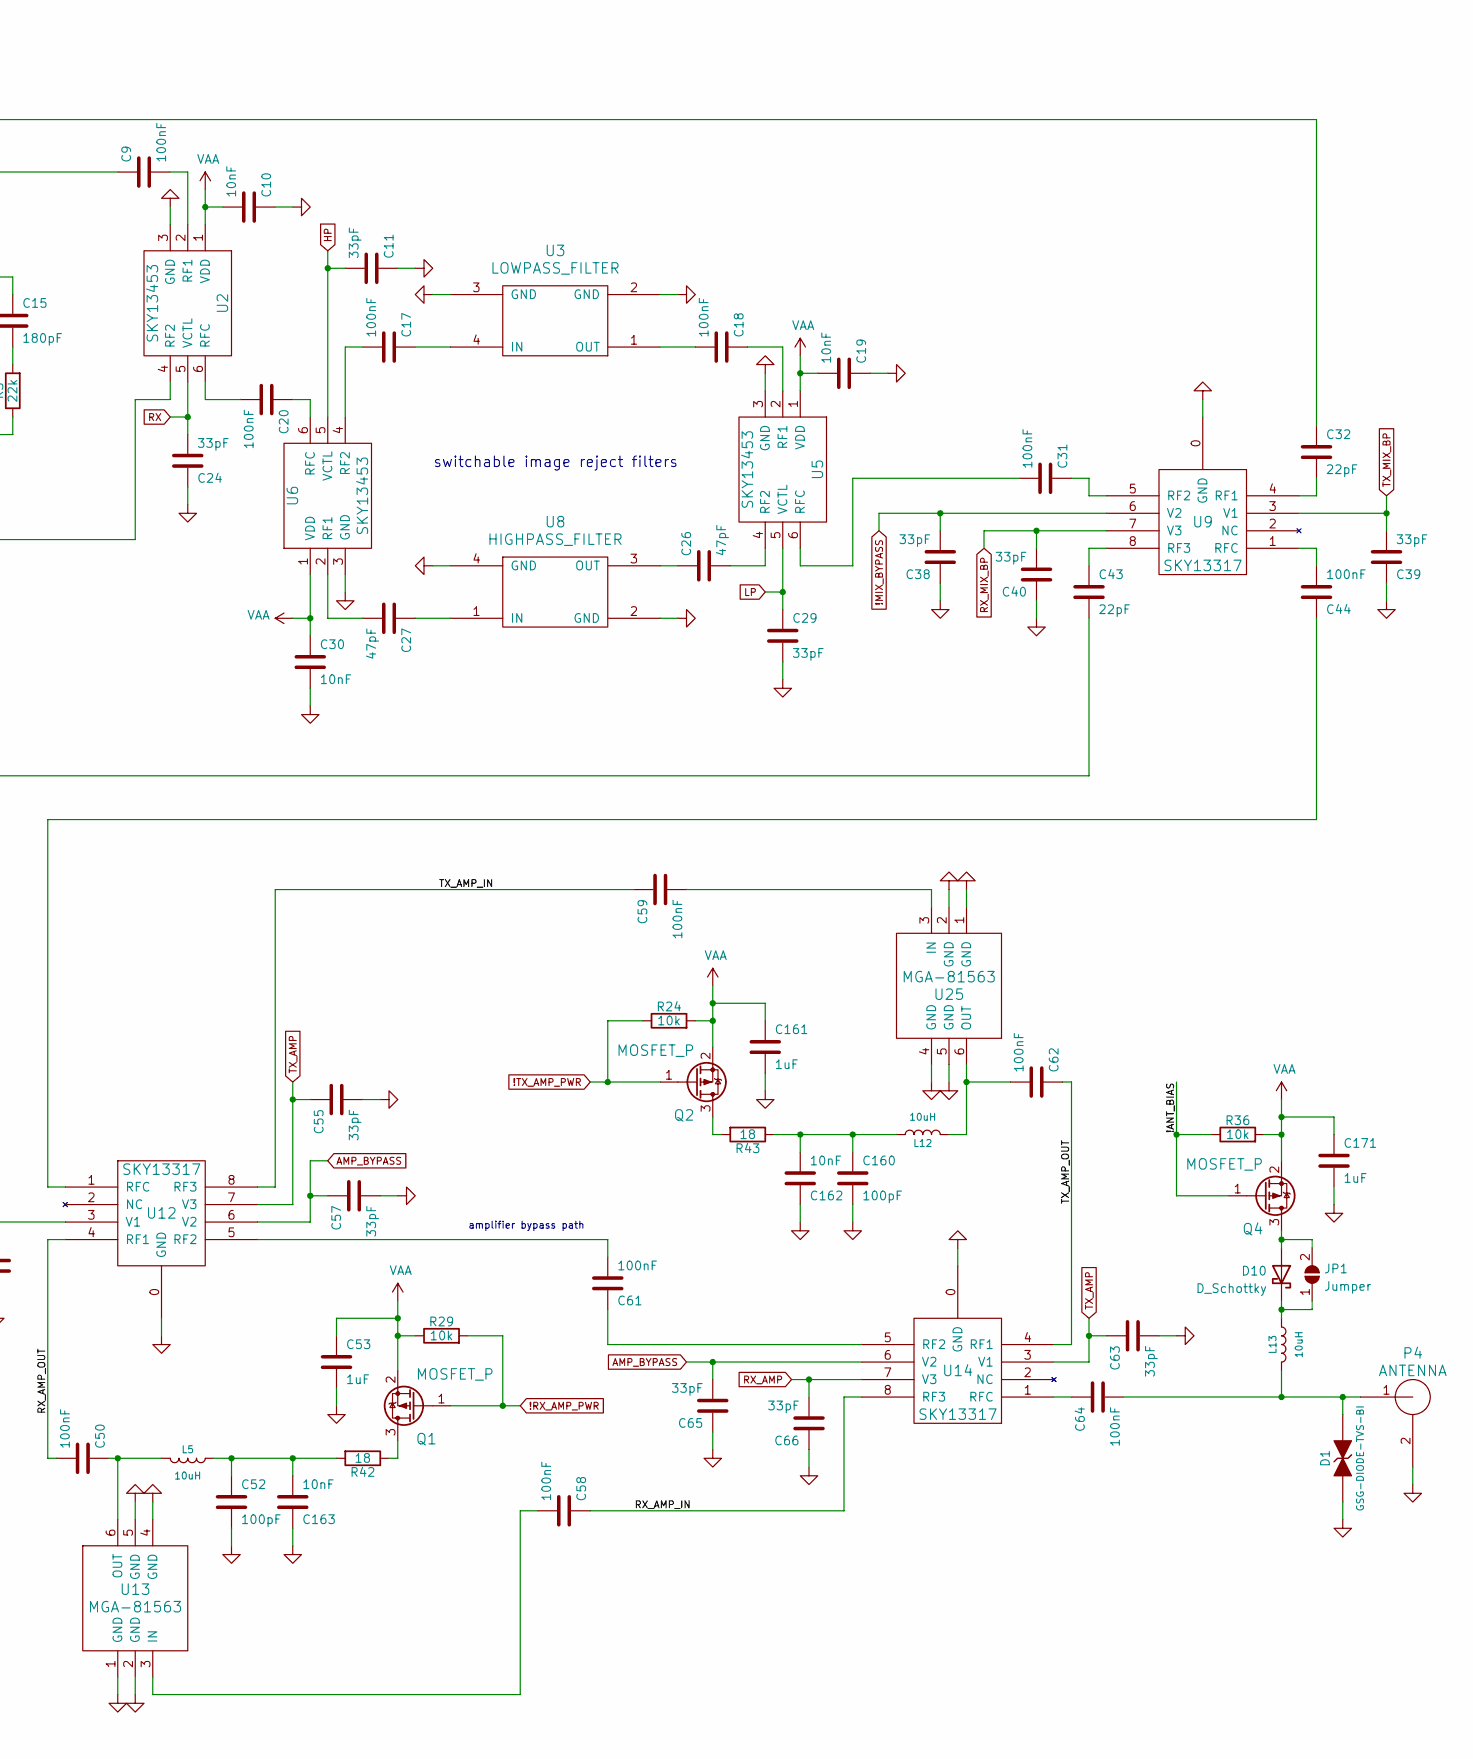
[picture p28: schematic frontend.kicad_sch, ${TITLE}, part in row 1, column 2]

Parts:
C1, C3, C5, C7, C11, C24, C29, C33, C34, C35, C36, C37, C38, C39, C40, C45, C47, C55, C57, C60, C63, C65, C66, C67: 33pF; GSG-0402; Part Number CL05C330JB5NNNC
C2, C4, C6, C10, C16, C19, C22, C30, C54, C56, C162, C163: 10nF; GSG-0402; Part Number CL05B103KB5NNNC
C8, C21, C32, C43, C48, C51: 22pF; GSG-0402; Part Number CL05C220JB5NNNC
C9, C17, C18, C20, C23, C25, C28, C31, C44, C46, C49, C50, C58, C59, C61, C62, C64, C166: 100nF; GSG-0402; Part Number CL05A104KA5NNNC
C12, C13: 330pF; GSG-0402; Part Number CL05C331JB5NNNC
C14: 8p2; GSG-0402; Part Number CC0402CRNPO9BN8R2
C15: 180pF; GSG-0402; Part Number CC0402JRNPO9BN181
C26, C27: 47pF; GSG-0402; Part Number CL05C470JB5NNNC
C41, C42, C52, C70, C160: 100pF; GSG-0402; Part Number CL05C101JB5NNNC
C53, C161, C171: 1uF; GSG-0402; Part Number CL05A105KP5NNNC
D1: GSG-DIODE-TVS-BI; GSG-0402; Part Number LXES15AAA1-100
D10: D_Schottky; DSN1006-2; Part Number PMEG4010ESBYL
J2: RF-SHIELD-FRAME; GSG-SHIELD-BMI-S-230; Part Number BMI-S-230-F-R
J3: RF-SHIELD-COVER; Part Number BMI-S-230-C
J4, J5, J6, J7, J8, J9: MOUNTING_HOLE; GSG-HOLE126MIL-COPPER
J10: GND_CLIP; GSG-TEST-POINT-S1751-46R; Part Number S1751-46R
JP1: Jumper; 0603-JUMPER
L1, L4: DNP; GSG-0402
L2, L3, L5, L12, L13: 10uH; GSG-0603; Part Number BRL1608T100M
P4: ANTENNA; GSG-SMA-73251-2120; Part Number 73251-2121
P6: GPO4; GSG-TESTPOINT-50MIL
P7: GPO2; GSG-TESTPOINT-50MIL
P13: GPO1; GSG-TESTPOINT-50MIL
P17: GPO6; GSG-TESTPOINT-50MIL
P19: GPO3; GSG-TESTPOINT-50MIL
P21: REF_IN; GSG-TESTPOINT-50MIL
P27: MIXER_SDATA; GSG-TESTPOINT-50MIL
P31: MIXER_SCLK; GSG-TESTPOINT-50MIL
P32: MIXER_ENX; GSG-TESTPOINT-50MIL
P33: MIXER_RESETX; GSG-TESTPOINT-50MIL
P34: MIX_BYPASS; GSG-TESTPOINT-50MIL
P35: !MIX_BYPASS; GSG-TESTPOINT-50MIL
P43: RX; GSG-TESTPOINT-50MIL
P44: HP; GSG-TESTPOINT-50MIL
P45: LP; GSG-TESTPOINT-50MIL
P46: TX_MIX_BP; GSG-TESTPOINT-50MIL
P47: RX_MIX_BP; GSG-TESTPOINT-50MIL
P48: TX_AMP; GSG-TESTPOINT-50MIL
P49: RX_AMP; GSG-TESTPOINT-50MIL
P50: AMP_BYPASS; GSG-TESTPOINT-50MIL
P51: !TX_AMP_PWR; GSG-TESTPOINT-50MIL
P52: !RX_AMP_PWR; GSG-TESTPOINT-50MIL
Q1, Q2, Q4: MOSFET_P; SOT23-3; Part Number YJL2301C
R1, R2: 470; GSG-0402; Part Number RMCF0402JT470R
R3: 22k; GSG-0402; Part Number ERJ-2GEJ223X
R4: 51k; GSG-0402; Part Number RMCF0402FT51K0
R5, R6, R24, R29, R36: 10k; GSG-0402; Part Number RMCF0402JT10K0
R42, R43: 18; GSG-0402; Part Number RC0402JR-0718RL
T1: MIX_IN_BALUN; GSG-B0310J50100AHF; Part Number B0310J50100AHF
T2: MIX_OUT_BALUN; GSG-B0310J50100AHF; Part Number B0310J50100AHF
U1, U2, U5, U6, U7, U10, U11: SKY13453; SKY13350-385LF; Part Number SKY13453-385LF
U3: LOWPASS_FILTER; GSG-LP0603; Part Number LP0603A1880ANTR
U4: RFFC5072; GSG-QFN32; Part Number RFFC5072TR7
U8: HIGHPASS_FILTER; GSG-HP-DEA; Part Number DEA162400HT-8004B1
U9, U12, U14: SKY13317; GSG-SKY13317-373LF; Part Number SKY13317-373LF
U13, U25: MGA-81563; GSG-SOT363; Part Number MGA-81563-TR1G

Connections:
!MIX_BYPASS: C7.2, C38.2, P35.1, U1.5 (VCTL), U9.6 (V2); also elsewhere on the board
!RX_AMP_PWR: P52.1, Q1.1 (G), R29.2; also elsewhere on the board
!TX_AMP_PWR: P51.1, Q2.1 (G), R24.1; also elsewhere on the board
/frontend/!ANT_BIAS: P13.1, Q4.1 (G), R36.1, U4.15 (GPO1/ADD1)
/frontend/REF_IN: C67.2, C70.1, P21.1, U4.10 (REF_IN)
/frontend/RX_AMP_IN: C58.1, U14.8 (RF3)
/frontend/RX_AMP_OUT: C50.2, U12.4 (RF1)
/frontend/TX_AMP_IN: C59.1, U12.8 (RF3)
/frontend/TX_AMP_OUT: C62.1, U14.4 (RF1)
AMP_BYPASS: C57.1, C65.2, P50.1, U12.6 (V2), U14.6 (V2); also elsewhere on the board
GND: C1.2, C2.2, C3.2, C4.2, C5.2, C6.2, C7.1, C10.1, C11.1, C12.2, C13.2, C16.2, C19.1, C22.1, C24.1, C25.2, C29.2, C30.2, C33.2, C34.2, C35.2, C36.2, C37.2, C38.1, C39.1, C40.1, C41.2, C42.2, C45.1, C47.1, C49.1, C52.2, C53.2, C54.2, C55.2, C56.2, C57.2, C60.1, C63.2, C65.1, C66.1, C70.2, C160.2, C161.2, C162.1, C163.1, C166.2, C171.2, D1.1 (A), J2.0 (SHIELD), J4.1, J5.1, J6.1, J7.1, J8.1, J9.1, J10.1, P4.2 (GND), R4.1, U1.3 (GND), U2.3 (GND), U3.2 (GND), U3.3 (GND), U4.0 (EP), U4.12 (TM), U5.3 (GND), U6.3 (GND), U7.3 (GND), U8.2 (GND), U8.4 (GND), U9.0 (GND), U10.3 (GND), U11.3 (GND), U12.0 (GND), U13.1 (GND), U13.2 (GND), U13.4 (GND), U13.5 (GND), U14.0 (GND), U25.1 (GND), U25.2 (GND), U25.4 (GND), U25.5 (GND); also elsewhere on the board
HP: C11.2, P44.1, U6.5 (VCTL); also elsewhere on the board
LP: C29.1, P45.1, U5.5 (VCTL); also elsewhere on the board
MIXER_ENX: C35.1, P32.1, R6.2, U4.30 (ENX); also elsewhere on the board
MIXER_RESETX: C34.1, P33.1, R5.2, U4.29 (RESETX); also elsewhere on the board
MIXER_SCLK: C36.1, P31.1, U4.31 (SCLK); also elsewhere on the board
MIXER_SDATA: C37.1, P27.1, U4.32 (SDATA); also elsewhere on the board
MIX_BYPASS: C47.2, P34.1, U11.5 (VCTL); also elsewhere on the board
MIX_CLK: C67.1; also elsewhere on the board
unnamed: C8.2, U1.6 (RFC)
unnamed: C9.1, U7.2 (RF1)
unnamed: C9.2, U2.2 (RF1)
unnamed: C12.1, R1.2, U4.8 (LFILT3)
unnamed: C13.1, R1.1, R2.2
unnamed: C14.1, C15.1, R2.1, U4.7 (LFITLT2)
unnamed: C14.2, R3.1, U4.6 (LFILT1)
unnamed: C15.2, R3.2
unnamed: C17.1, U3.4 (IN)
unnamed: C17.2, U6.4 (RF2)
unnamed: C18.1, U5.2 (RF1)
unnamed: C18.2, U3.1 (OUT)
unnamed: C20.1, U6.6 (RFC)
unnamed: C20.2, U2.6 (RFC)
unnamed: C21.1, U1.2 (RF1)
unnamed: C21.2, U7.4 (RF2)
unnamed: C23.1, U10.4 (RF2)
unnamed: C23.2, U2.4 (RF2)
unnamed: C25.1, T1.2 (S2)
unnamed: C26.1, U8.3 (OUT)
unnamed: C26.2, U5.4 (RF2)
unnamed: C27.1, U8.1 (IN)
unnamed: C27.2, U6.2 (RF1)
unnamed: C28.1, T1.1 (S1)
unnamed: C28.2, U7.6 (RFC)
unnamed: C31.1, U9.5 (RF2)
unnamed: C31.2, U5.6 (RFC)
unnamed: C32.1, U1.4 (RF2)
unnamed: C32.2, U9.4 (RF1)
unnamed: C43.1, U9.8 (RF3)
unnamed: C43.2, U11.2 (RF1)
unnamed: C44.1, U12.1 (RFC)
unnamed: C44.2, U9.1 (RFC)
unnamed: C46.1, U10.6 (RFC)
unnamed: C46.2, T2.1 (S1)
unnamed: C48.1, U11.6 (RFC)
unnamed: C49.2, T2.2 (S2)
unnamed: C50.1, L5.2, U13.6 (OUT)
unnamed: C51.1, U11.4 (RF2)
unnamed: C51.2, U10.2 (RF1)
unnamed: C58.2, U13.3 (IN)
unnamed: C59.2, U25.3 (IN)
unnamed: C61.1, U14.5 (RF2)
unnamed: C61.2, U12.5 (RF2)
unnamed: C62.2, L12.2, U25.6 (OUT)
unnamed: C64.1, U14.1 (RFC)
unnamed: C64.2, D1.2 (K), L13.2, P4.1 (RF)
unnamed: C160.1, C162.2, L12.1, R43.1
unnamed: C52.1, C163.2, L5.1, R42.2
unnamed: D10.1 (K), JP1.1 (A), L13.1
unnamed: D10.2 (A), JP1.2 (B), Q4.3 (D)
unnamed: L1.1, T1.4 (PR2), U4.23 (MIX_IPP)
unnamed: L1.2, T1.3 (PR1), U4.24 (MIX_IPN)
unnamed: L2.1, L4.2, T2.4 (PR2), U4.27 (MIX_OPN)
unnamed: L3.1, L4.1, T2.3 (PR1), U4.28 (MIX_OPP)
unnamed: P6.1, U4.26 (GPO4/LD/DO)
unnamed: P7.1, U4.16 (GPO2/ADD2)
unnamed: P17.1, U4.9 (MODE/GPO6)
unnamed: P19.1, U4.25 (GPO3/FM)
unnamed: Q1.3 (D), R42.1
unnamed: Q2.3 (D), R43.2
unnamed: R4.2, U4.4 (REXT)
RX: C24.2, C33.1, C45.2, P43.1, U2.5 (VCTL), U7.5 (VCTL), U10.5 (VCTL); also elsewhere on the board
RX_AMP: C60.2, C66.2, P49.1, U12.3 (V1), U14.7 (V3); also elsewhere on the board
RX_IF: C48.2; also elsewhere on the board
RX_MIX_BP: C40.2, P47.1, U9.7 (V3); also elsewhere on the board
TX_AMP: C55.1, C63.1, P48.1, U12.7 (V3), U14.3 (V1); also elsewhere on the board
TX_IF: C8.1; also elsewhere on the board
TX_MIX_BP: C39.2, P46.1, U9.3 (V1); also elsewhere on the board
VAA: C3.1, C4.1, C5.1, C6.1, C10.2, C16.1, C19.2, C22.2, C30.1, C41.1, C42.1, C53.1, C54.1, C56.1, C161.1, C166.1, C171.1, L2.2, L3.2, Q1.2 (S), Q2.2 (S), Q4.2 (S), R24.2, R29.1, R36.2, U1.1 (VDD), U2.1 (VDD), U4.5 (ANA_VDD1), U4.22 (ANA_VDD2), U5.1 (VDD), U6.1 (VDD), U7.1 (VDD), U10.1 (VDD), U11.1 (VDD); also elsewhere on the board
VCC: C1.1, C2.1, R5.1, R6.1, U4.19 (DIG_VDD); also elsewhere on the board

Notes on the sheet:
optional alligator clip test point
mounting holes are connected to GND
Expected MIX_CLK is 1.8 to 3.3 V peak-to-peak at 25 to 52 MHz. It is divided down to 0.5 to 1.5 V (REF_IN).
switchable image reject filters
amplifier bypass path
loop filter

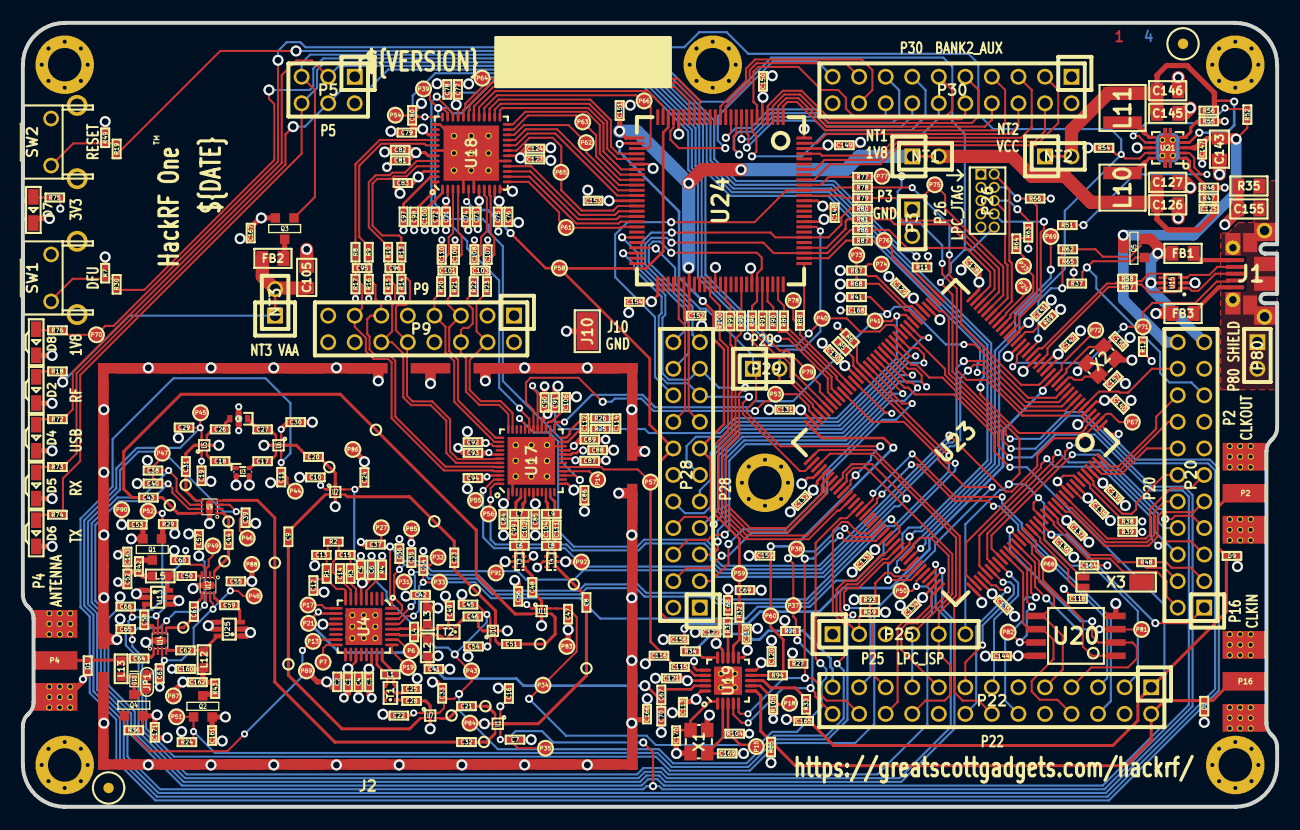
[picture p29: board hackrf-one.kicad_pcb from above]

Board: 4 copper layers, 120.0 x 75.0 mm, 437 parts (0 on the bottom side), 319 nets.

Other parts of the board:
FID1, FID2: FIDUCIAL; GSG-MARK1MM
TESTPOINT-30MIL-MASKONLY, TESTPOINT-30MIL-MASKONLY#2, TESTPOINT-30MIL-MASKONLY#3, TESTPOINT-30MIL-MASKONLY#4, TESTPOINT-30MIL-MASKONLY#5, TESTPOINT-30MIL-MASKONLY#6, TESTPOINT-30MIL-MASKONLY#7, TESTPOINT-30MIL-MASKONLY#8, TESTPOINT-30MIL-MASKONLY#9, TESTPOINT-30MIL-MASKONLY#10, TESTPOINT-30MIL-MASKONLY#11, TESTPOINT-30MIL-MASKONLY#12, TESTPOINT-30MIL-MASKONLY#13, TESTPOINT-30MIL-MASKONLY#14, TESTPOINT-30MIL-MASKONLY#15, TESTPOINT-30MIL-MASKONLY#16, TESTPOINT-30MIL-MASKONLY#17: VAL**; GSG-TESTPOINT-30MIL-MASKONLY

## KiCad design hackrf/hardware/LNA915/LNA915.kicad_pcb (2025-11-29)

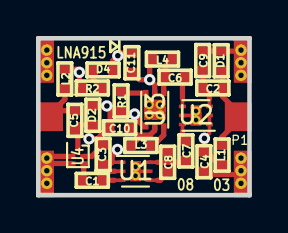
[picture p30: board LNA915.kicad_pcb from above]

Board: 4 copper layers, 11.7 x 8.7 mm, 25 parts (0 on the bottom side), 17 nets.

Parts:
C1, C2, C3, C4, C5, C6, C7, C8: 100pF; 0402
C9: 1 pF; 0402
C10, C11: 1uF; 0402
D1, D2: D_TVS; 0402
D4: LNALED; 0402
L1, L2, L3, L4: 39nH; 0402
P1: SMA-KIT-1.5MF
R1: 3k; 0402
R2: 470; 0402
U1, U2: SWITCH; GRF6011
U3: LNA; TSLP-7-1
U4: SAW; F5Q

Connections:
GND: C3.1, C4.1, C9.2, C10.1, C11.1, D1.1, D2.1, D4.1, P1.2, P1.4, U1.5, U1.7, U2.5, U2.7, U3.7, U4.2, U4.3, U4.5
unnamed: C1.1, U4.4
unnamed: C1.2, U1.3
unnamed: C2.1, C9.1, U2.3
unnamed: C2.2, D1.2, L1.1, P1.1
unnamed: C5.1, L2.1, P1.3
unnamed: C5.2, D2.2, U4.1
unnamed: C6.1, L4.2, U3.4
unnamed: C6.2, U2.4
unnamed: C7.1, U1.6
unnamed: C7.2, U2.6
unnamed: C8.1, U1.4
unnamed: C8.2, L3.1, U3.3
unnamed: C10.2, L3.2, U3.2
unnamed: D4.2, R2.2
unnamed: R1.2, U3.6
VCC: C3.2, C4.2, C11.2, L1.2, L2.2, L4.1, R1.1, R2.1, U1.1, U1.2, U2.1, U2.2, U3.1, U3.5

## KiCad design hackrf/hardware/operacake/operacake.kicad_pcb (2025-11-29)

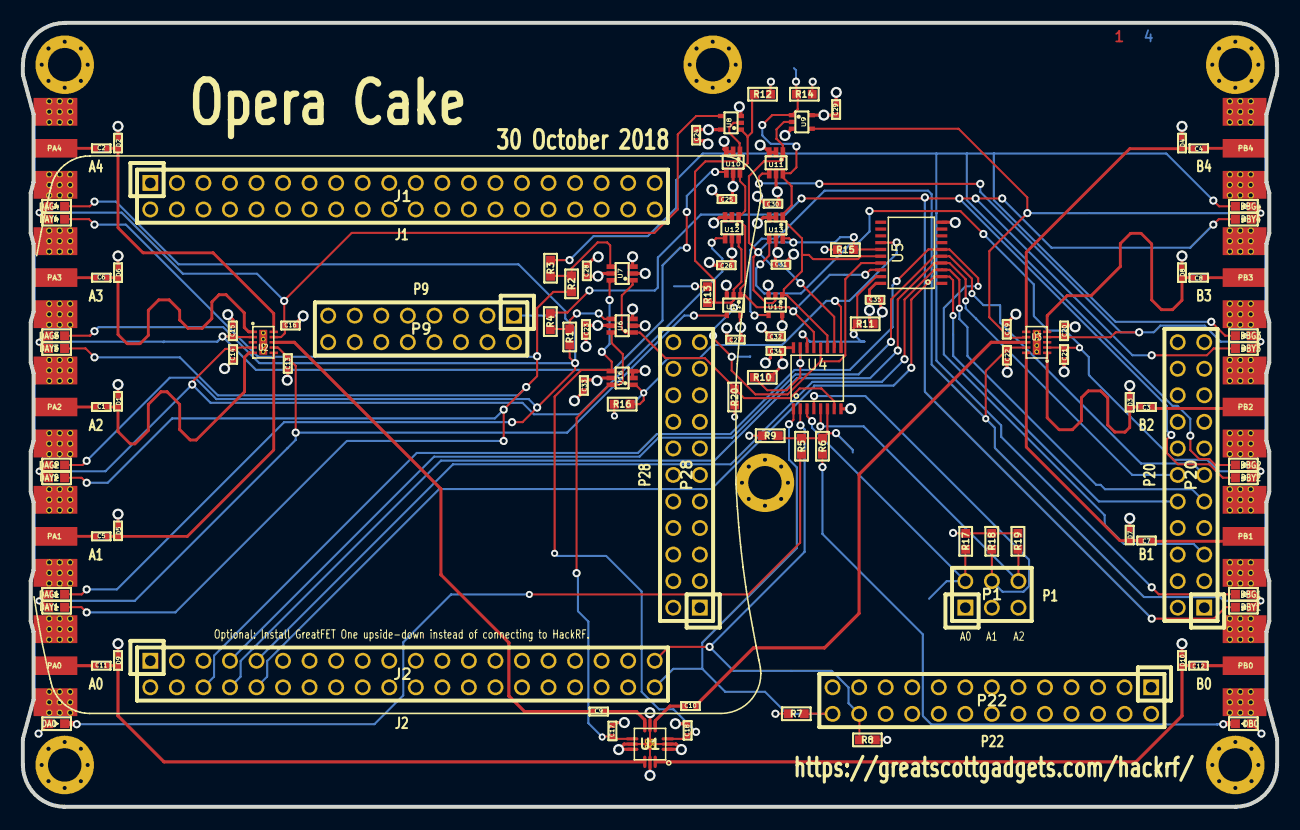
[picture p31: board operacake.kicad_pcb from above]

Board: 4 copper layers, 120.0 x 75.0 mm, 152 parts (0 on the bottom side), 63 nets.

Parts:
C1, C2, C3, C4, C5, C6, C7, C8, C9, C10, C11, C12, C23, C24, C25, C26, C27, C28, C29, C30, C31, C32, C33, C34, C35: 100nF; 0402
C13, C14, C15, C16, C17, C18, C19, C20, C21, C22: 33pF; 0402
D1, D2, D3, D4, D5, D6, D7, D8, D9, D10: GSG-DIODE-TVS-BI; 0402
DA0: LED; 0603D
DAG1, DAG2, DAG3, DAG4: LED; 0603D
DAY1, DAY2, DAY3, DAY4: LED; 0603D
DB0: LED; 0603D
DBG1, DBG2, DBG3, DBG4: LED; 0603D
DBY1, DBY2, DBY3, DBY4: LED; 0603D
J1, J2: CONN_02X20; HEADER-2x20-REVERSE
MH1, MH2, MH3, MH4, MH5, MH6: MOUNTING_HOLE; HOLE126MIL-COPPER
P1: ADDRESS; HEADER-2x3
P9: BASEBAND; HEADER-2x8
P20: GPIO; HEADER-2x11
P22: I2S; HEADER-2x13
P28: SD; HEADER-2x11
PA0, PA1, PA2, PA3, PA4: GSG-RF-CONN; GSG-SMA-73251-2120
PB0, PB1, PB2, PB3, PB4: GSG-RF-CONN; GSG-SMA-73251-2120
R1, R2, R3, R4, R5, R6: 330; 0603
R7, R8: 1k8; 0603
R9, R10, R11, R12, R13, R14, R15, R16, R17, R18, R19, R20: 10k; 0603
TP1, TP2, TP3, TP4, TP5, TP6, TP7, TP8, TP9, TP10, TP11, TP12, TP13, TP14, TP15, TP16, TP17, TP18, TP19, TP20, TP21, TP22, TP23, TP24, TP25, TP26, TP27, TP28, TP29, TP30: CONN_1; TESTPOINT-50MIL
U1: MASWSS0129; QFN12-3
U2, U3: SKY13322; SKY13322-375LF
U4: PCA9557; TSSOP16
U5: TC7MBL3245CFT; TSSOP20
U6, U7, U10, U11, U12, U13: 74LVC1G58; SOT363
U8, U9: 74AHC1G08; SOT353-1
U14, U15: 74AHC1G02; SOT353-1
U16: 74LVC1G19; SOT363

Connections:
/!LED_EN: R5.2, R6.2, R9.2, TP6.1, U4.6
/!OE: R11.1, TP8.1, U4.14, U5.19
/!RESET: R10.1, TP7.1, U4.15
/A0: P1.2, R17.1, TP28.1, U4.3
/A1: P1.4, R18.1, TP29.1, U4.4
/A2: P1.6, R19.1, TP30.1, U4.5
/EXT_U1CTRL: J2.6, P20.5, TP5.1, U5.6
/EXT_U2CTRL0: J2.9, P20.9, TP2.1, U5.3
/EXT_U2CTRL1: J2.10, P20.10, TP1.1, U5.2
/EXT_U3CTRL0: J2.7, P20.11, TP4.1, U5.5
/EXT_U3CTRL1: J2.8, P20.12, TP3.1, U5.4
/LED_EN2: R20.1, U4.7, U6.1, U7.1
/SCL: J2.40, P22.26, R7.2, TP27.1, U4.1
/SDA: J2.39, P22.24, R8.2, TP26.1, U4.2
/U1CTRL: R16.1, TP9.1, U4.9, U5.14, U16.1
/U1VC1: C18.2, TP16.1, U1.3, U7.6, U16.4
/U1VC2: C17.2, TP17.1, U1.7, U6.6, U16.6
/U2CTRL0: R13.1, TP10.1, U4.12, U5.17, U8.2, U10.1, U12.6, U14.2
/U2CTRL1: R12.1, TP11.1, U4.13, U5.18, U8.1, U10.6, U12.1, U14.1
/U2V1: C14.1, DAG2.2, DAY2.2, TP18.1, U2.4, U12.4
/U2V2: C15.2, DAG3.2, DAY3.2, TP19.1, U2.2, U10.4
/U2V3: C13.1, DAG1.2, DAY1.2, TP20.1, U2.7, U14.4
/U2V4: C16.2, DAG4.2, DAY4.2, TP21.1, U2.9, U8.4
/U3CTRL0: R15.1, TP12.1, U4.10, U5.15, U9.2, U11.1, U13.6, U15.2
/U3CTRL1: R14.1, TP13.1, U4.11, U5.16, U9.1, U11.6, U13.1, U15.1
/U3V1: C20.1, DBG3.2, DBY3.2, TP22.1, U3.4, U11.4
/U3V2: C21.2, DBG2.2, DBY2.2, TP23.1, U3.2, U13.4
/U3V3: C19.1, DBG4.2, DBY4.2, TP24.1, U3.7, U9.4
/U3V4: C22.2, DBG1.2, DBY1.2, TP25.1, U3.9, U15.4
GND: C13.2, C14.2, C15.1, C16.1, C17.1, C18.1, C19.2, C20.2, C21.1, C22.1, C23.1, C24.1, C25.1, C26.1, C27.1, C28.1, C29.1, C30.1, C31.1, C32.1, C33.1, C34.1, C35.1, D1.2, D2.2, D3.2, D4.2, D5.2, D6.2, D7.2, D8.2, D9.2, D10.2, J1.1, J2.1, MH1.1, MH2.1, MH3.1, MH4.1, MH5.1, MH6.1, P9.1, P9.2, P9.3, P9.8, P9.9, P9.14, P9.15, P9.16, P20.15, P20.19, P22.4, P22.10, P22.18, P28.2, P28.12, PA0.2, PA1.2, PA2.2, PA3.2, PA4.2, PB0.2, PB1.2, PB2.2, PB3.2, PB4.2, R17.2, R18.2, R19.2, R20.2, TP14.1, U1.0, U1.1, U1.2, U1.5, U1.8, U1.9, U1.11, U2.0, U3.0, U4.8, U5.10, U6.2, U7.2, U8.3, U9.3, U10.2, U10.3, U11.2, U11.3, U12.2, U12.3, U13.2, U13.3, U14.3, U15.3, U16.2, U16.3
unnamed: C1.1, D1.1, U2.5
unnamed: C1.2, PA2.1
unnamed: C2.1, D2.1, U2.10
unnamed: C2.2, PA4.1
unnamed: C3.1, D3.1, U3.1
unnamed: C3.2, PB2.1
unnamed: C4.1, D4.1, U3.6
unnamed: C4.2, PB4.1
unnamed: C5.1, D5.1, U2.6
unnamed: C5.2, PA1.1
unnamed: C6.1, D6.1, U2.1
unnamed: C6.2, PA3.1
unnamed: C7.1, D7.1, U3.10
unnamed: C7.2, PB1.1
unnamed: C8.1, D8.1, U3.5
unnamed: C8.2, PB3.1
unnamed: C9.1, U1.6
unnamed: C9.2, U2.8
unnamed: C10.1, U3.8
unnamed: C10.2, U1.4
unnamed: C11.1, D9.1, U1.10
unnamed: C11.2, PA0.1
unnamed: C12.1, D10.1, U1.12
unnamed: C12.2, PB0.1
unnamed: DA0.1, R5.1
unnamed: DAG1.1, DAG2.1, DAG3.1, DAG4.1, R1.1
unnamed: DAY1.1, DAY2.1, DAY3.1, DAY4.1, R2.1
unnamed: DB0.1, R6.1
unnamed: DBG1.1, DBG2.1, DBG3.1, DBG4.1, R3.1
unnamed: DBY1.1, DBY2.1, DBY3.1, DBY4.1, R4.1
unnamed: R1.2, R4.2, U6.4
unnamed: R2.2, R3.2, U7.4
VCC: C23.2, C24.2, C25.2, C26.2, C27.2, C28.2, C29.2, C30.2, C31.2, C32.2, C33.2, C34.2, C35.2, DA0.2, DB0.2, J1.2, P1.1, P1.3, P1.5, P20.3, P22.11, P28.1, R7.1, R8.1, R9.1, R10.2, R11.2, R12.2, R13.2, R14.2, R15.2, R16.2, TP15.1, U4.16, U5.20, U6.3, U6.5, U7.3, U7.5, U8.5, U9.5, U10.5, U11.5, U12.5, U13.5, U14.5, U15.5, U16.5

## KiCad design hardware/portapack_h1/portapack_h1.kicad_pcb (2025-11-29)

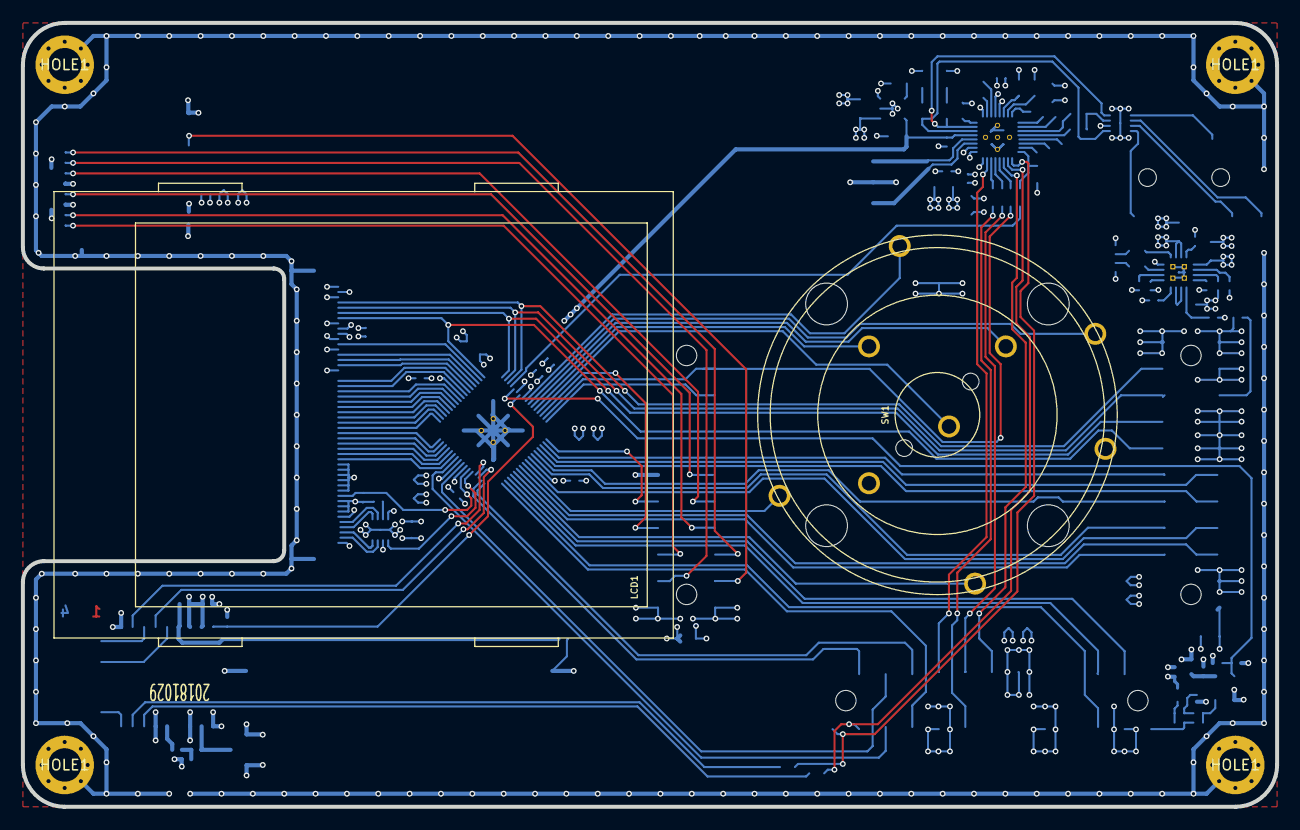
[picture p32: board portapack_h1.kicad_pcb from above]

Board: 4 copper layers, 120.0 x 75.0 mm, 111 parts (0 on the bottom side), 139 nets.

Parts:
BT1: BATTERY; MPD_BU2032SM-BT-G
C1: 1U; IPC_CAPC200X125X135L45N
C2, C3, C4, C5, C9, C18, C20, C27, C28, C29, C30, C31, C33, C35: 100N; IPC_CAPC100X50X55L25N
C6, C8, C10, C12: 2U2; IPC_CAPC160X80X90L35N
C7, C11, C13, C26, C32, C34, C36, C37, C38, C40, C41, C42, C43: 10U; IPC_CAPC200X125X135L45N
C14, C25: 1U; IPC_CAPC160X80X90L35N
C15, C16: 4U7; IPC_CAPC200X125X135L45N
C17: 1N; IPC_CAPC100X50X55L25N
C19: 10N; IPC_CAPC100X50X55L25N
C22, C23: 220N; IPC_CAPC160X80X90L35N
C39: R; IPC_CAPC160X80X90L35N
D1: LED 0603 green; IPC_LEDC1608X90L40N
D2: LED 0603 yellow; IPC_LEDC1608X90L40N
FB1, FB2, FB3: FBEAD; IPC_BEADC160X80X95L40N
FID1, FID2, FID3: FIDUCIAL; FIDUCIAL_65MIL
H2, H3, H4, H5: HOLE1; HOLE_3200UM_VIAS
J1: HEADER_1X3; JST_S3B-PH-SM4-TB
J2: MICROSD_DETSW; ALPS_SCHA4B0419
J3: ER-TFT024-3_FPC; ER-CON50HT-1
J4: HEADER_1X2; JST_S2B-PH-SM4-TB
L1: 27N; IPC_INDC100X50X60L20N
LCD1: ER-TFT024-3_PANEL; ER-TFT024-3
P1: CONN_COAX; 1909763-1
P2: TRRS_SW_JACK; CUI_SJ-43516-SMT
P20: HACKRF_ONE_P20; HEADER_11X2_REV_SM_254_AP
P22: HACKRF_ONE_P22; HEADER_13X2_REV_SM_254_AP
P28: HACKRF_ONE_P28; HEADER_11X2_REV_SM_254_AP
R1: R; IPC_RESC100X50X40L25N
R2: 10K; IPC_RESC160X80X55L25N
R3, R5: 1K5; IPC_RESC100X50X40L25N
R4: 1K91; IPC_RESC100X50X40L25N
R6: 1K8; IPC_RESC100X50X40L25N
R7, R23, R24: 0R; IPC_RESC100X50X40L25N
R8, R9, R10, R13, R14, R15, R16, R19: 10K; IPC_RESC100X50X40L25N
R11, R12: 33R; IPC_RESC160X80X55L25N
R17: 1M; IPC_RESC100X50X40L25N
R18: 2K2; IPC_RESC160X80X55L25N
R20: 3K9; IPC_RESC100X50X40L25N
R21: 100R; IPC_RESC100X50X40L25N
R22: 33R; IPC_RESC100X50X40L25N
R25: 100K; IPC_RESC100X50X40L25N
R26: 10R; IPC_RESC100X50X40L25N
RP1: 220R; IPC_RESCAXS8P80_320X160X60L30X45N
SW1: CK_TSWB-3N-CB; CK_TSWB-3N-CB222_LFS
TP1, TP2, TP3, TP4, TP5, TP6, TP7, TP8, TP9: TP; TP_1MM
U1: AK4951EN; IPC_QFN33P40_400X400X80L35X20T280N
U2: TCR2EF18,LM(CT; IPC_SOT23-5P95_275X135L40X40N
U3: 5M40ZE64; IPC_QFP65P40_900X900X120L60X18T450N
U4: CAT4004[_AB]; IPC_SON9P50_200X200X55L32X24T90X160N
U5: NUF4220MN; IPC_SON9P50_200X200X100L30X25T80X120N
U6: BQ24075RGT; IPC_QFN17P50_300X300X100L40X25T160N
U7: 74HC1G04GW; IPC_SOT23-5P65_212X110L33X22N
U8: MAX-M8
X1: 10.00000M; IPC_OSCCC320X250X110L75X100N

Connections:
+1V8: C3.1, C29.1, C31.1, C33.1, C35.1, C36.1, C37.1, C40.1, J3.6, J3.40, J3.41, U1.21, U2.5, U3.8, U3.39, U3.41, U3.57
+3V3: C2.1, C4.1, C7.1, C11.1, C14.1, C18.1, C20.1, C26.1, C27.1, C28.1, C30.1, C32.1, C34.1, C38.1, C42.1, C43.1, FB2.1, J2.4, J3.1, J3.42, P20.3, P22.11, P28.1, R15.1, R23.2, U1.16, U1.28, U2.1, U2.3, U3.6, U3.23, U4.8, U7.5, U8.7, U8.8
/audio/BICK: P22.16, RP1.8
/audio/BICK_R: RP1.1, U1.14
/audio/CN: C6.2, U1.27
/audio/CP: C6.1, U1.26
/audio/GND_X: P2.4, U5.7
/audio/LHPOUT: C22.1, U1.22, U5.1
/audio/LHPOUT_X: P2.2, U5.8
/audio/LRCK_R: RP1.2, U1.13
/audio/MIC: C25.2, R18.2, U5.3
/audio/MIC_X: P2.1, U5.6
/audio/PDN#_R: R2.1, RP1.4, U1.8
/audio/REGFIL: C12.2, U1.31
/audio/RHPOUT: C23.1, U1.23, U5.4
/audio/RHPOUT_X: P2.3, U5.5
/audio/SCL: FB3.1, P22.26, U1.9
/audio/SDA: FB1.1, P22.24, U1.10
/audio/SDTO_R: RP1.3, U1.12
/audio/SPN: J1.1, U1.19
/audio/SPP: J1.3, U1.20
/audio/VCOM: C10.2, U1.30
/audio/VEE: C8.1, U1.24
/hackrf_if/AUDIO_RESET#: RP1.5, U3.4
/hackrf_if/CLKIN: P22.2, R21.1, R22.1
/hackrf_if/GPS_RESET#: R25.1, U3.7, U8.9
/hackrf_if/GPS_TIMEPULSE: U3.35, U8.4
/hackrf_if/GPS_TX_READY: U3.36, U8.2
/hackrf_if/H1_CPLD_TCK: P28.17, U3.16
/hackrf_if/I2S0_MCLK: P22.17, U1.15
/hackrf_if/I2S0_RX_SDA: P28.19, RP1.6, U3.15
/hackrf_if/I2S0_TX_SDA: P22.13, U1.11
/hackrf_if/I2S0_WS: P22.15, RP1.7
/hackrf_if/LCD_BACKLIGHT: U3.37, U4.1
/hackrf_if/LCD_DB0: J3.32, U3.59
/hackrf_if/LCD_DB1: J3.31, U3.58
/hackrf_if/LCD_DB2: J3.30, U3.56
/hackrf_if/LCD_DB3: J3.29, U3.55
/hackrf_if/LCD_DB4: J3.28, U3.54
/hackrf_if/LCD_DB5: J3.27, U3.53
/hackrf_if/LCD_DB6: J3.26, U3.52
/hackrf_if/LCD_DB7: J3.25, U3.51
/hackrf_if/LCD_DB8: J3.24, U3.50
/hackrf_if/LCD_DB9: J3.23, U3.49
/hackrf_if/LCD_DB10: J3.22, U3.48
/hackrf_if/LCD_DB11: J3.21, U3.47
/hackrf_if/LCD_DB12: J3.20, U3.46
/hackrf_if/LCD_DB13: J3.19, U3.45
/hackrf_if/LCD_DB14: J3.18, U3.44
/hackrf_if/LCD_DB15: J3.17, U3.43
/hackrf_if/LCD_RD#: J3.35, U3.60
/hackrf_if/LCD_RESET#: J3.10, R19.1, U3.38
/hackrf_if/LCD_RS: J3.37, U3.62
/hackrf_if/LCD_TE: J3.39, U3.63
/hackrf_if/LCD_WR#: J3.36, U3.61
/hackrf_if/MCU_ADDR: P22.19, U3.33
/hackrf_if/MCU_D0: P20.5, U3.26
/hackrf_if/MCU_D1: P20.6, U3.27
/hackrf_if/MCU_D2: P20.7, U3.24
/hackrf_if/MCU_D3: P20.8, U3.22
/hackrf_if/MCU_D4: P20.9, U3.20
/hackrf_if/MCU_D5: P20.10, U3.21
/hackrf_if/MCU_D6: P20.11, U3.19
/hackrf_if/MCU_D7: P20.12, U3.18
/hackrf_if/MCU_DIR: P22.22, U3.42
/hackrf_if/MCU_IO_STBX: P22.20, U3.32
/hackrf_if/MCU_LCD_RD: P22.5, U3.30
/hackrf_if/MCU_LCD_TE: P22.6, U3.31
/hackrf_if/MCU_LCD_WR: P22.21, U3.40
/hackrf_if/P2_8: P22.23, U3.34
/hackrf_if/PP_CPLD_TDO: P28.10, U3.17
/hackrf_if/PP_CPLD_TMS: P28.8, U3.14
/hackrf_if/REF_EN: R15.2, R16.1, U3.5, X1.1
/hackrf_if/RESET#: P22.3, U3.29
/hackrf_if/SD_CD: J2.B, P28.3
/hackrf_if/SD_CLK: J2.5, P28.11
/hackrf_if/SD_CMD: J2.3, P28.9
/hackrf_if/SD_DAT0: J2.7, P28.7
/hackrf_if/SD_DAT1: J2.8, P28.6
/hackrf_if/SD_DAT2: J2.1, P28.5
/hackrf_if/SD_DAT3: J2.2, P28.4
/hackrf_if/SW_D: SW1.S2, U3.10
/hackrf_if/SW_L: SW1.S5, U3.28
/hackrf_if/SW_R: SW1.S3, U3.9
/hackrf_if/SW_ROT_A: SW1.A, U3.11
/hackrf_if/SW_ROT_B: SW1.B, U3.12
/hackrf_if/SW_SEL: SW1.S1, U3.13
/hackrf_if/SW_U: SW1.S4, U3.25
/hackrf_if/TP_D: J3.45, P20.16, U3.1
/hackrf_if/TP_L: J3.46, P20.18, U3.2
/hackrf_if/TP_R: J3.44, P20.14, U3.64
/hackrf_if/TP_U: J3.47, P20.20, U3.3
/hackrf_if/VBAT: BT1.1, C41.1, P20.1, R24.1
/hackrf_if/VBUS: C1.1, P20.21, R7.1, U6.13
/hackrf_if/VBUSCTRL: P20.17, R7.2
/lcd_sw_sd/LEDK1: J3.2, U4.3
/lcd_sw_sd/LEDK2: J3.3, U4.4
/lcd_sw_sd/LEDK3: J3.4, U4.5
/lcd_sw_sd/LEDK4: J3.5, U4.6
/power/AUDIO_SVDD: C5.1, C13.1, C16.1, P20.22, R3.1, R5.1, R13.1, U1.18, U6.10, U6.11
/power/BBAT: C15.1, J4.1, U6.2, U6.3
GND: BT1.2, C1.2, C2.2, C3.2, C4.2, C5.2, C7.2, C8.2, C9.2, C10.1, C11.2, C12.1, C13.2, C14.2, C15.2, C16.2, C18.2, C19.2, C20.2, C26.2, C27.2, C28.2, C29.2, C30.2, C31.2, C32.2, C33.2, C34.2, C35.2, C36.2, C37.2, C38.2, C39.2, C40.2, C41.2, C42.2, C43.2, H2.1, H3.1, H4.1, H5.1, J1.2, J2.0, J2.6, J2.A, J2.SH, J3.7, J3.8, J3.9, J3.11, J3.12, J3.13, J3.14, J3.15, J3.16, J3.34, J3.38, J3.43, J3.48, J3.49, J3.50, J3.SHLD, J4.2, P1.2, P20.13, P20.15, P20.19, P22.4, P22.10, P22.18, P28.2, P28.12, R1.2, R2.2, R4.2, R6.2, R8.2, R9.2, R10.2, R11.2, R12.2, R14.2, R16.2, R19.2, R20.2, R25.2, SW1.CA, SW1.CB, U1.17, U1.25, U1.29, U1.33, U2.2, U3.65, U4.2, U4.9, U5.2, U5.9, U6.8, U6.17, U7.3, U8.1, U8.10, U8.12, U8.15, X1.2
unnamed: C9.1, FB2.2, X1.4
unnamed: C17.1, R21.2, X1.3
unnamed: C17.2, R17.2, U7.2
unnamed: C19.1, L1.2, R26.2
unnamed: C22.2, R11.1
unnamed: C23.2, R12.1
unnamed: C25.1, U1.3
unnamed: C39.1, U2.4
unnamed: D1.A, R3.2
unnamed: D1.C, U6.7
unnamed: D2.A, R5.2
unnamed: D2.C, U6.9
unnamed: FB1.2, U8.16
unnamed: FB3.2, U8.17
unnamed: L1.1, P1.1, U8.11
unnamed: R1.1, U6.14
unnamed: R4.1, U6.12
unnamed: R6.1, U6.16
unnamed: R8.1, U6.1
unnamed: R9.1, U6.4
unnamed: R10.1, U6.15
unnamed: R13.2, U6.6
unnamed: R14.1, U6.5
unnamed: R17.1, R22.2, U7.4
unnamed: R18.1, U1.4
unnamed: R20.1, U4.7
unnamed: R23.1, R24.2, U8.6
unnamed: R26.1, U8.14
unnamed: TP1.1, U1.32
unnamed: TP2.1, U1.1
unnamed: TP3.1, U1.2
unnamed: TP4.1, U1.5
unnamed: TP5.1, U1.6
unnamed: TP6.1, U1.7
unnamed: TP7.1, U8.18
unnamed: TP8.1, U8.5
unnamed: TP9.1, U8.3

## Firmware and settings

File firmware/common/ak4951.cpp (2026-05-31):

/*
 * Copyright (C) 2017 Jared Boone, ShareBrained Technology, Inc.
 *
 * This file is part of PortaPack.
 *
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
 * You should have received a copy of the GNU General Public License
 * along with this program; see the file COPYING.  If not, write to
 * the Free Software Foundation, Inc., 51 Franklin Street,
 * Boston, MA 02110-1301, USA.
 */

#include "ak4951.hpp"

#include "portapack_io.hpp"
using namespace portapack;

#include <ch.h>

namespace asahi_kasei {
namespace ak4951 {

void AK4951::configure_digital_interface_i2s() {
    // Configure for external slave mode.
    map.r.mode_control_1.DIF = 0b11;  // I2S compatible
    map.r.mode_control_1.BCKO = 0;    // BICK = 32fs
    update(Register::ModeControl1);

    map.r.mode_control_2.CM = 0b00;    // MCKI = 256fs
    map.r.mode_control_2.FS = 0b1011;  // fs = 48kHz
    update(Register::ModeControl2);
}

void AK4951::configure_digital_interface_external_slave() {
    map.r.power_management_2.MS = 0;     // Slave mode
    map.r.power_management_2.PMPLL = 0;  // EXT mode
    update(Register::PowerManagement2);
}

void AK4951::configure_digital_interface_external_master() {
    map.r.power_management_2.MS = 1;     // Master mode
    map.r.power_management_2.PMPLL = 0;  // EXT mode
    update(Register::PowerManagement2);
}

void AK4951::init() {
    reset();

    // Write dummy address to "release" the reset.
    write(0x00, 0x00);

    configure_digital_interface_i2s();
    configure_digital_interface_external_slave();

    map.r.power_management_1.PMVCM = 1;
    update(Register::PowerManagement1);

    // Headphone output is hi-Z when not active, reduces crosstalk from speaker output.
    map.r.beep_control.HPZ = 1;
    update(Register::BeepControl);

    // Pause for VCOM and REGFIL pins to stabilize.
    chThdSleepMilliseconds(2);

    headphone_mute();

    // SPK-Amp gain setting: SPKG1-0 bits = “00” → “01”
    map.r.signal_select_2.SPKG = 0b01;
    update(Register::SignalSelect2);

    map.r.signal_select_3.MONO = 0b00;
    update(Register::SignalSelect3);

    map.r.digital_filter_mode.PFSDO = 0;     // ADC bypass digital filter block.
    map.r.digital_filter_mode.ADCPF = 1;     // ADC output
    map.r.digital_filter_mode.PFDAC = 0b00;  // SDTI
    update(Register::DigitalFilterMode);

    // Set up FRN, FRATT and ADRST1-0 bits (Addr = 09H)
    // map.r.timer_select.FRN = 0;
    // map.r.timer_select.FRATT = 0;
    // map.r.timer_select.ADRST = 0b00;
    // update(Register::TimerSelect);

    // Set up ALC mode (Addr = 0AH, 0BH)
    // map.r.alc_timer_select. = ;
    // update(Register::ALCTimerSelect);
    // map.r.alc_mode_control_1. = ;
    // update(Register::ALCModeControl1);

    // Set up REF value of ALC (Addr = 0CH)
    // map.r.alc_mode_control_2. = ;
    // update(Register::ALCModeControl2);

    // Set up IVOL value of ALC operation start (Addr = 0DH)
    // map.r.l_ch_input_volume_control. = ;
    // update(Register::LchInputVolumeControl);
    // map.r.r_ch_input_volume_control. = ;
    // update(Register::RchInputVolumeControl);

    // Set up the output digital volume. (Addr = 13H)
    // set_headphone_volume(...);

    // Set up Programmable Filter Path: PFDAC1-0 bits=“01”, PFSDO=ADCPF bits=“0” (Addr = 1DH)
    // map.r.digital_filter_mode.PFDAC = 0b01;
    // update(Register::DigitalFilterMode);
}

bool AK4951::detected() {
    return reset();
}

bool AK4951::reset() {
    io.audio_reset_state(true);

    // PDN# pulse must be >200ns
    chThdSleepMicroseconds(10);

    io.audio_reset_state(false);

    return true;
}

// void AK4951::set_digtal_volume_control(const reg_t value) {
//     map.r.l_ch_digital_volume_control.DV = value;
//     update(Register::LchDigitalVolumeControl);
// }

bool AK4951::set_digtal_volume_control(const reg_t value) {
    map.r.l_ch_digital_volume_control.DV = value;
    return update(Register::LchDigitalVolumeControl);
}

// void AK4951::set_headphone_volume(const volume_t volume) {
//     const auto normalized = headphone_gain_range().normalize(volume);
//     auto n = normalized.centibel() / 5;
//     set_digtal_volume_control(0xcb - n);
// }

bool AK4951::set_headphone_volume(const volume_t volume) {
    const auto normalized = headphone_gain_range().normalize(volume);
    auto n = normalized.centibel() / 5;
    return set_digtal_volume_control(0xcb - n);
}

void AK4951::headphone_mute() {
    set_digtal_volume_control(0xff);
}

void AK4951::set_dac_power(const bool enable) {
    map.r.power_management_1.PMDAC = enable;
    update(Register::PowerManagement1);
}

void AK4951::set_headphone_power(const bool enable) {
    map.r.power_management_2.PMHPL = map.r.power_management_2.PMHPR = enable;
    update(Register::PowerManagement2);
}

void AK4951::set_speaker_power(const bool enable) {
    map.r.power_management_2.PMSL = enable;
    update(Register::PowerManagement2);
}

void AK4951::select_line_out(const LineOutSelect value) {
    map.r.power_management_2.LOSEL = (value == LineOutSelect::Line) ? 1 : 0;
    update(Register::PowerManagement2);
}

void AK4951::headphone_enable() {
    set_dac_power(true);
    set_headphone_power(true);

    // Wait for headphone amplifier charge pump power-up.
    chThdSleepMilliseconds(35);
}

void AK4951::headphone_disable() {
    set_headphone_power(false);

    // Don't power off DAC unless Speaker is disabled also
    if (map.r.power_management_2.PMSL == 0) {
        set_dac_power(false);
    }
}

void AK4951::speaker_enable() {
    // Set up the path of DAC → SPK-Amp: DACS bit = “0” → “1”
    map.r.signal_select_1.DACS = 1;
    update(Register::SignalSelect1);

    // Enter Speaker-Amp Output Mode: LOSEL bit = “0”
    select_line_out(LineOutSelect::Speaker);

    // Power up DAC, Programmable Filter and Speaker-Amp: PMDAC=PMPFIL=PMSL bits=“0”→“1”
    set_dac_power(true);
    // map.r.power_management_1.PMPFIL = 1;
    // update(Register::PowerManagement1);
    set_speaker_power(true);

    // Time from PMSL=1 to SLPSN=1.
    chThdSleepMilliseconds(1);

    // Exit the power-save mode of Speaker-Amp: SLPSN bit = “0” → “1”
    map.r.signal_select_1.SLPSN = 1;
    update(Register::SignalSelect1);
}

void AK4951::speaker_disable() {
    // Enter Speaker-Amp Power Save Mode: SLPSN bit = “1” → “0”
    map.r.signal_select_1.SLPSN = 0;
    update(Register::SignalSelect1);

    // Disable the path of DAC → SPK-Amp: DACS bit = “1” → “0”
    map.r.signal_select_1.DACS = 0;
    update(Register::SignalSelect1);

    // Power down DAC, Programmable Filter and speaker: PMDAC=PMPFIL=PMSL bits= “1”→“0”
    // Exception: Don't power off DAC unless Headphones are disabled too
    if (map.r.power_management_2.PMHPL == 0) {
        set_dac_power(false);
    }

    // map.r.power_management_1.PMPFIL = 0;
    // update(Register::PowerManagement1);
    set_speaker_power(false);
}
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

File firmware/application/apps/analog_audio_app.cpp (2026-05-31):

/*
 * Copyright (C) 2014 Jared Boone, ShareBrained Technology, Inc.
 * Copyright (C) 2018 Furrtek
 *
 * This file is part of PortaPack.
 *
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
 * You should have received a copy of the GNU General Public License
 * along with this program; see the file COPYING.  If not, write to
 * the Free Software Foundation, Inc., 51 Franklin Street,
 * Boston, MA 02110-1301, USA.
 */

#include "analog_audio_app.hpp"

#include "audio.hpp"
#include "baseband_api.hpp"
#include "file.hpp"
#include "portapack.hpp"
#include "portapack_persistent_memory.hpp"
#include "string_format.hpp"
#include "ui_freqman.hpp"
#include "utility.hpp"
#include "radio.hpp"
#include "i2cdevmanager.hpp"

using namespace portapack;
using namespace tonekey;

namespace ui {

/* AMOptionsView *********************************************************/

AMOptionsView::AMOptionsView(
    AnalogAudioView* view,
    Rect parent_rect,
    const Style* style)
    : View{parent_rect} {
    set_style(style);

    add_children({
        &label_config,
        &options_config,
        &zoom_config,
    });

    zoom_config.on_change = [this, view](size_t, OptionsField::value_t n) {            // n , has two option values. when GUI =zoom+1 => (0), when GUI=zoom+2 (6)
        receiver_model.set_am_configuration(view->get_previous_AM_mode_option() + n);  // n (0 or 6)
        view->set_zoom_factor(AM_MODULATION, n);
        view->set_previous_zoom_option(n);
    };

    // restore zoom selection
    zoom_config.set_by_value(view->get_zoom_factor(AM_MODULATION));

    freqman_set_bandwidth_option(AM_MODULATION, options_config);                                        // freqman.cpp to the options_config, only allowing 5 modes  freqman_bandwidths[AM]  {"DSB 9k", 0},  {"DSB 6k", 1},  {"USB+3k", 2}, {"LSB-3k", 3}, {"CW", 4},
    options_config.set_by_value(receiver_model.am_configuration() - view->get_previous_zoom_option());  // restore AM GUI option mode ,   AM FIR index filters (0..11) values ,  <baseband::AMConfig, 12> am_configs has 12 fir  index elements.
    options_config.on_change = [this, view](size_t, OptionsField::value_t n) {
        receiver_model.set_am_configuration(n + view->get_previous_zoom_option());  // we select proper FIR AM filter (0..11), = 0..4 GUI AM modes + offset +6 (if zoom+2)
        view->set_previous_AM_mode_option(n);                                       // (0..4) allowing 5 AM modes (DSB9K, DSB6K, USB,LSB, CW)
    };
}

/* NBFMOptionsView *******************************************************/

NBFMOptionsView::NBFMOptionsView(
    Rect parent_rect,
    const Style* style)
    : View{parent_rect} {
    set_style(style);

    add_children({&label_config,
                  &options_config,
                  &text_squelch,
                  &field_squelch});

    freqman_set_bandwidth_option(NFM_MODULATION, options_config);  // adding the common message from freqman.cpp to the options_config
    options_config.set_by_value(receiver_model.nbfm_configuration());
    options_config.on_change = [this](size_t, OptionsField::value_t n) {
        receiver_model.set_nbfm_configuration(n);
    };

    field_squelch.set_value(receiver_model.squelch_level());
    field_squelch.on_change = [this](int32_t v) {
        receiver_model.set_squelch_level(v);
    };
}

/* WFMOptionsView *******************************************************/

WFMOptionsView::WFMOptionsView(
    Rect parent_rect,
    const Style* style)
    : View{parent_rect} {
    set_style(style);

    add_children({
        &label_config,
        &options_config,
    });

    freqman_set_bandwidth_option(WFM_MODULATION, options_config);  // adding the common message from freqman.cpp to the options_config
    options_config.set_by_value(receiver_model.wfm_configuration());
    options_config.on_change = [this](size_t, OptionsField::value_t n) {
        receiver_model.set_wfm_configuration(n);
    };
}

/* WFMAMAptOptionsView *******************************************************/

WFMAMAptOptionsView::WFMAMAptOptionsView(
    Rect parent_rect,
    const Style* style)
    : View{parent_rect} {
    set_style(style);

    add_children({
        &label_config,
        &options_config,
    });

    freqman_set_bandwidth_option(WFMAM_MODULATION, options_config);  // adding the common message from freqman.cpp to the options_config
    options_config.set_by_value(receiver_model.wfmam_configuration());
    options_config.on_change = [this](size_t, OptionsField::value_t n) {
        receiver_model.set_wfmam_configuration(n);
    };
}

/* AMFMAptOptionsView *********************************************************/

AMFMAptOptionsView::AMFMAptOptionsView(
    AnalogAudioView* view,
    Rect parent_rect,
    const Style* style)
    : View{parent_rect} {
    set_style(style);

    add_children({
        &label_config,
        &options_config,
        &zoom_config,
    });

    freqman_set_bandwidth_option(AMFM_MODULATION, options_config);  // adding the common message from freqman.cpp to the options_config
    receiver_model.set_amfm_configuration(5);                       // Fix index 5 manually, not from freqman: set to  RX AM (USB+FM) mode to demod audio tone, and get Wefax_APT signal.
    options_config.set_by_value(receiver_model.amfm_configuration());

    zoom_config.on_change = [this, view](size_t, OptionsField::value_t n) {
        receiver_model.set_amfm_configuration(5 + n);
        view->set_zoom_factor(AMFM_MODULATION, n);
    };

    // restore zoom selection
    zoom_config.set_by_value(view->get_zoom_factor(AMFM_MODULATION));
}

/* SPECOptionsView *******************************************************/
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

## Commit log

2025-11-29 1MB code
    [Drill_PTH_Through.DRL, Drill_PTH_Through_Via.DRL, Gerber_BoardOutlineLayer.GKO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]
2026-05-31 add low power mode

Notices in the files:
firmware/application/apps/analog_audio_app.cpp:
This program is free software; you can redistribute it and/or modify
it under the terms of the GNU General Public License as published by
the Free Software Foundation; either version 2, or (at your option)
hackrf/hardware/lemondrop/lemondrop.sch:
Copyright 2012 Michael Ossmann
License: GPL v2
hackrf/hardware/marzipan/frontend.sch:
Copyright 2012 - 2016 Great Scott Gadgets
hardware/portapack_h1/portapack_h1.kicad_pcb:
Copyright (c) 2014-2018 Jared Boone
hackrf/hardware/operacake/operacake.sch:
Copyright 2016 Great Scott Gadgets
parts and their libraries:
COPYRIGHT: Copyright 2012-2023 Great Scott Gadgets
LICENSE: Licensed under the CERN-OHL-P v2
